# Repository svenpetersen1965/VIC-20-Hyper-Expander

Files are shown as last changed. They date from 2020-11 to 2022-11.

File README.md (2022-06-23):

# VIC-20-Hyper-Expander
The Hyper Expander is a cartridge for the Commodore VIC-20, which provides up to 16kB EPROM and up to 37kB RAM. It is a super-set of the original Commodore VIC-1211A Super Expander, which provides only 3k of RAM.

The Hyper Expander can hold up to two 27C512 EPROMs, the 8k memory bank of both EPROMs (A13...A15) can be selected for both EPROMs. The same selection applies to both of them. Each EPROM (IC1 and IC2) can be jumpered to two chip selects. That is BLK2 or BLK5 for IC1 and BLK1 or BLK3 for IC2. 

The RAM od two 32kB 62256 type static RAMs. The memory is divided into seven banks. Two 74LS148s decodes the active chip selects to one of each memory bank. The used chip selects can be configured with JP5 and JP4.

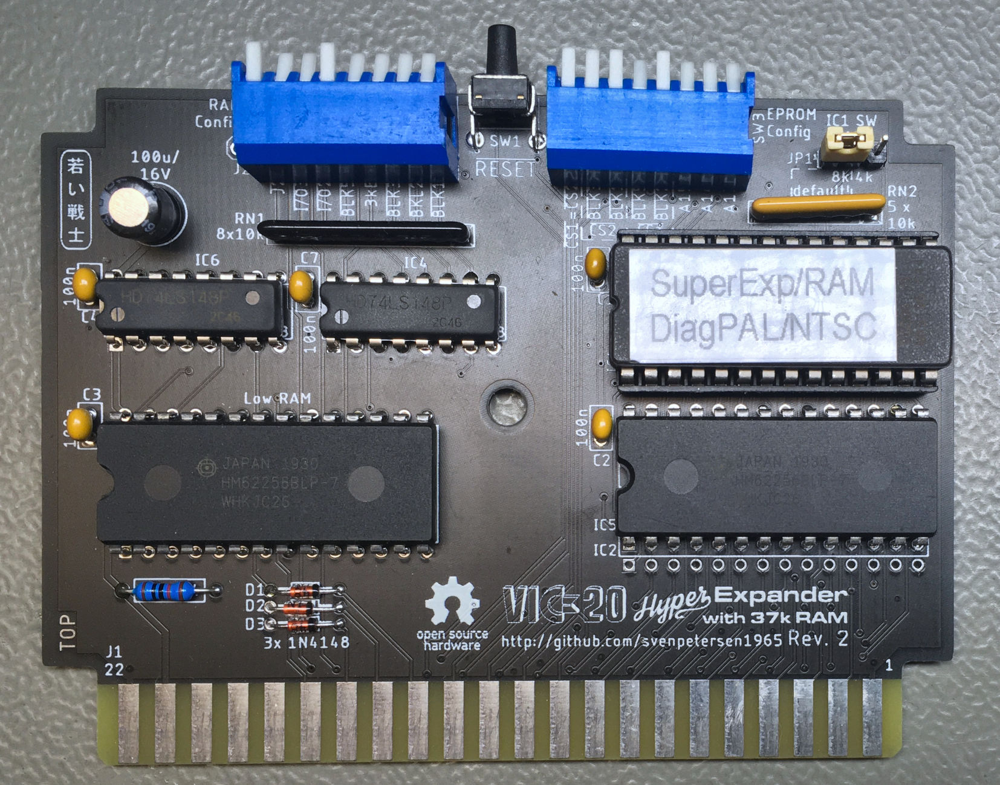
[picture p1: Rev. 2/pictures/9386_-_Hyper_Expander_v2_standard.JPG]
VIC-20 Hyper Expander


The BOM values do not include a case
* The calculated BOM value of Rev. 0 is: 12.86€ (12.12.2020)
* The calculated BOM value of Rev. 1 is: 15.23€ (11.04.2021)
* The calculated BOM value of Rev. 2 is: 16.17€ (02.11.2021)

# RAM issues
I was recently reported (May 2022), that there were cross-link issues with the Alliance 45ns and 55ns RAMs. I believe, that those might be too fast and that it is not an issue of the brand. Replacing those RAMs with slower models (70ns) has solved this problem. A friend has successfully used 100ns and 120ns RAMs as well (he had built a couple of the Hyper Expander). I am mainly using 70ns and 80ns RAMs and never found any issues with them. At least, my test software can recognize those problems.

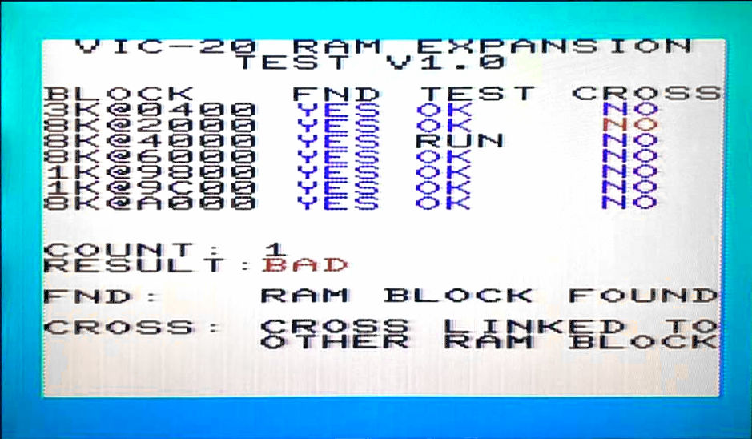
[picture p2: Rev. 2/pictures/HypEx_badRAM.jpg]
45ns RAM issue


# Testsoftware
Find the Testsoftware here: https://github.com/svenpetersen1965/VIC-20-RAM-Expansion-Test-Software

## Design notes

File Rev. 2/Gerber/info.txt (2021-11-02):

      
       Board: VIC20_HypExp
       Rev.:  2
  
       Files:
       ======
  
       All Gerber files are generated in extended gerber format (RS274X)
       *.TOP        : Film top copper
       *.BOT        :  -"- bottom copper
       *.STC        :  -"- top soldermask 
       *.STS        :  -"- bottom soldermask
       *.PLC        :  -"- silk screen top
       *.PLS        :  -"- silk screen bottom
       *.DK         : Drills plated Through (Excellon)
       *.NDK        : Drills not plated Through (Excellon)
       *.OUT        : Board outline

       Board Size:
       ===========
       Length     :   102.0 mm
       Width      :   75.0 mm
       Thickness  :   1.6 mm
       Material   :   FR 4
       Copper     :   35 um
       Surface    :   HASL
       
       Remarks:
       ========
       Width >= 8mil
       Distance >= 6mil
       Drill >= 0.35mm

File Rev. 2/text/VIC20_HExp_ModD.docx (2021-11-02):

Commodore VIC-20: Hyper Expander Rev. 2

Module Description

# Introduction

The Hyper Expander is a cartridge for the Commodore VIC-20, which provides up to 16kB EPROM and up to 37kB RAM. It is a super-set of the original Commodore VIC-1211A Super Expander, which provides only 3k of RAM.

The Hyper Expander can hold up to two 27C512 EPROMs, the 8k memory bank of both EPROMs (A13...A15) can be selected for both EPROMs. The same selection applies to both of them. Each EPROM (IC1 and IC2) can be configured to two chip selects (one each). That is or for IC1 and or for IC2 or in case SW3, switch 8 (CS1 = CS2) is selected, all four chip selects can be assigned to one EPROM (one at a time!).

The RAM consists of two 32kB 62256 type static RAMs. The memory is divided into four banks each. Two 74LS148 decode the active chip selects to one of each memory bank. The used chip selects can be configured with SW2.

# Configuration

## Note

The chip selects of the EPROM and the RAM can be concurrent. The same chip select must not be used for RAM and EPROM at the same time.

## DIP-Switches

There are two DIP Switches, which are used to configure the cartridge. The footprints of the DIP-switches are versatile and offer several ways for a fix or variable configuration:

1. A fix configuration via solder bridges
2. Jumpers
3. Horizontal DIP-switches
4. Vertical DIP-switches with 2.54mm (0.1”) row distance
5. Vertical (piano style) DIP-switches with 7.62mm (0.3”) row distance

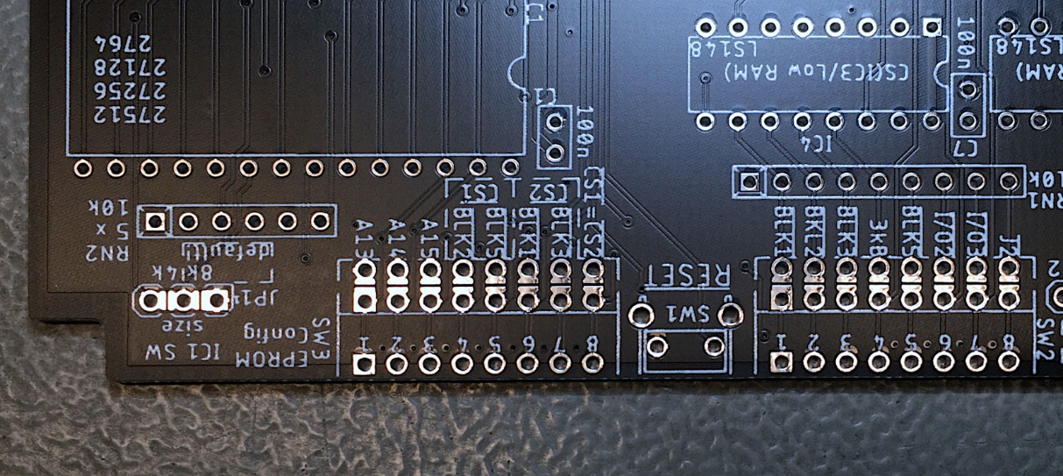
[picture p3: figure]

Figure 1: The footprint of the configuration DIP-switches allows a fix configuration with solder bridges

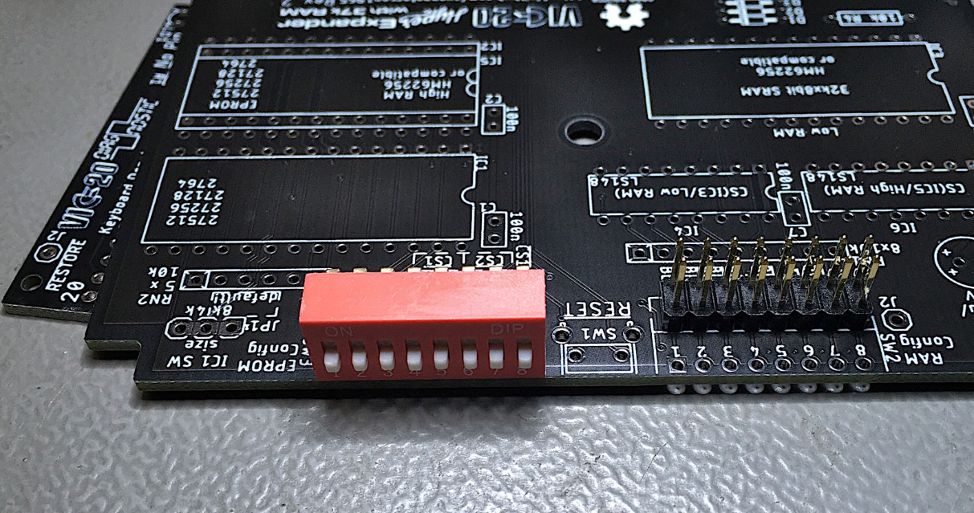
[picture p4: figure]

Figure 2: Vertical DIP-switch (row distance 2.54mm) or configuration with jumpers

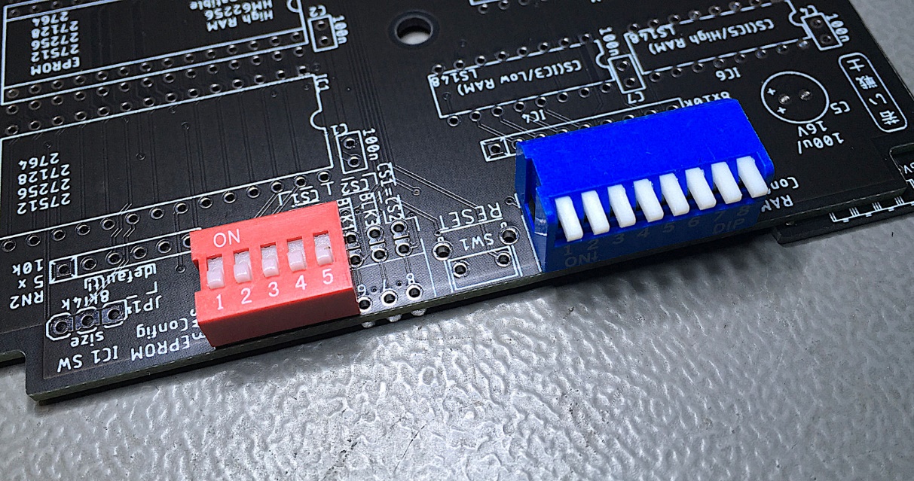
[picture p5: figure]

Figure 3: A horizontal or a piano style DIP-switch

## SW3 – EPROM configuration

The DIP switches do not need to be 8 switches wide, in case just one EPROM is used (refer to Figure 3). In this case, only a 5 switches wide model is sufficient. For a mere EPROM cartridge, it would be a good idea to program software that uses the same chip select () (or the same two chip selects for a 16k cartridge) and configure those with solder bridges. This way, the cartridge cannot be misconfigured.

Switch | Function | VIC-20 Address | Note
SW3-1 | EPROM Bank Select A13 | | Selects 8k Bank
SW3-2 | EPROM Bank Select A14 | | Selects 8k Bank
SW3-3 | EPROM Bank Select A15 | | Selects 8k Bank
SW3-4 | IC1 chip select | $4000 - $5FFF
SW3-5 | IC1 chip select | $A000 - $BFFF
SW3-6 | IC2 chip select | $2000 - $3FFF
SW3-7 | IC2 chip select | $6000 - $7FFF
SW3-8 | = | | All effect both ICs

Table 1: EPROM configuration

In case all four of the previous chip selects should be configured to address one of the EPROMs, switch 8 (“= “) could be closed. In this case, both chip selects are tied together. It is only allowed to activate one chip select! This configuration is desired, in case both RAMs are placed and EPROM software residing at $2000 or $6000 is contained in IC1.

The mapping of the chip selects to the ICs are inherited from the original Super Expander. They support the known 16kB cartridge configurations. Hence, they are not in an ascending sequence on the DIP switch.

In case an EPROM should be deactivated, it is only required to switch the respective switch “off”. The chip select then is HIGH (inactive) due to pull-up resistors.

## SW3 - Memory Bank Select (EPROM)

There are two different types of addresses mentioned in this document:

- VIC-20 Address
- EPROM Offset Address

Both types must not be confused! The EPROM Offset Address is the address of the selected memory bank within (the program buffer of the EPROM). This is, where you load the different binary files to the EPROM buffer. One of those memory banks is selected with the DIP Switch SW3 (switch 1/2/3). This appears in/is mapped to the VIC-20 memory at the address determined by the chip select (see Fehler! Verweisquelle konnte nicht gefunden werden.).

SW3-3 | SW3-2 | SW3-1 | Address Bits | | | EPROM Address (Offset)
A15 | A14 | A13 | A15 | A14 | A13
ON | ON | ON | L | L | L | 0x0000 – 0x1FFF
ON | ON | OFF | L | L | H | 0x2000 – 0x3FFF
ON | OFF | ON | L | H | L | 0x4000 – 0x5FFF
ON | OFF | OFF | L | H | H | 0x6000 – 0x7FFF
OFF | ON | ON | H | L | L | 0x8000 – 0x9FFF
OFF | ON | OFF | H | L | H | 0xA000 – 0xBFFF
OFF | OFF | ON | H | H | L | 0xC000 – 0xDFFF
OFF | OFF | OFF | H | H | H | 0xE000 – 0xFFFF

Table 2: 8k cartridges memory banks

A switch that is ON corresponds to a SET jumper, in case the cartridge is configured with jumpers instead of DIP-Switches.

For EPROMs smaller than a 27C512, the highest address pins have to be HIGH (see Table 7). To prevent these pins to accidentally be switched to LOW, the corresponding DIP-Switch pins could be clipped off.

## IC1 Software Size - JP1

The software size of IC1 can be set to 4kB. In this case, only the first 4kB of an 8kB EPROM bank is active. This may be desired, if the hyper expander (EPROM) should be combined with cartridges, that use the second 4k memory of an 8k bank, like some machine language monitor or serial cartridges do. Of course, this only works with a software, that only requires 4k, like the Super Expander software.

The address range of the EPROMs (as seen by the CPU) with JP1 set to “4k”

Chip Select | VIC-20 Address
| $4000 - $4FFF
| $A000 - $AFFF
| $2000 - $2FFF
| $6000 - $6FFF

Table 3: Address ranges with SW size (JP1) set to "4k"

The default software size is 8k. If it is desired to combine two cartridge software (like Super Expander and the VIC-MON machine language monitor, it is recommended to burn those two bin files in the same 8k block at the proper position.

## SW2 – RAM Configuration

SW2 activates the chip select signals, that are then decoded and address the respective RAM bank of IC3.

Switch | Jumper | Chip Select | Addresses
SW2-1 | 1-16 | | $2000 - $3FFF
SW2-2 | 2-15 | | $4000 - $5FFF
SW2-3 | 3-14 | | $6000 - $7FFF
SW2-4 | 4-13 | | $0400 - $0FFF
SW2-5 | 5-12 | | $A000 - $BFFF
SW2-6 | 6-11 | | $9800 - $9BFF
SW2-7 | 7-10 | | $9C00 - $9FFF
SW2-8 | 8-9 | | Unused (experimental)

Table 4: Settings SW2

# BYTES FREE

Be aware, that not all RAM configurations will lead to a more BASIC memory (the BYTES FREE) on switch on. The BASIC memory has to be coherent.

The memory map (screen RAM, BASIC RAM) of the VIC-20 depends on the memory expansion. It will be different for internal RAM and 3k Expansion.

RAM Configuration | BYTES FREE
| 6655
| 11775
and | 11775
and | 19967
, and | 28159
, , , and | 28159
, , | 6655

Table 5: Reported BASIC RAM

RAM that is not visible as BASIC RAM can of course still be accessed. In case is selected, the lowest 3k are not visible as BASIC RAM. In case a memory gap is configured (like and are configured, but is missing, the BASIC RAM consists of the internal RAM and the 3k RAM expansion.

The Super Expander Software (in ROM) requires 136 bytes of RAM. In case this software is activated (it is associated to) the BASIC memory will be reduced by this number of bytes.

# EPROMs

Four different types/sizes of EPROMs can be used with the Super Expander II, not all settings make sense with them. Their pin out is shown in Table 6.

The effect of the settings and the recommended configurations are shown in Table 7.

27C64
| 27C128
| | 27C256
| | | 27C512
| | | | SOCKET
Vpp | Vpp | Vpp | A15 | 1 | A15 | VCC | 28 | VCC | VCC | VCC | VCC
A12 | A12 | A12 | A12 | 2 | A12 | A14 | 27 | A14 | A14 | /PGM | /PGM
A7 | A7 | A7 | A7 | 3 | A7 | A13 | 26 | A13 | A13 | A13 | n.c.
A6 | A6 | A6 | A6 | 4 | A6 | A8 | 25 | A8 | A8 | A8 | A8
A5 | A5 | A5 | A5 | 5 | A5 | A9 | 24 | A9 | A9 | A9 | A9
A4 | A4 | A4 | A4 | 6 | A4 | A11 | 23 | A11 | A11 | A11 | A11
A3 | A3 | A3 | A3 | 7 | A3 | /OE | 22 | /G/Vpp | /G | /G | /G
A2 | A2 | A2 | A2 | 8 | A2 | A10 | 21 | A10 | A10 | A10 | A10
A1 | A1 | A1 | A1 | 9 | A1 | GND | 20 | /E | /E | /E | /E
A0 | A0 | A0 | A0 | 10 | A0 | D7 | 19 | D7 | D7 | D7 | D7
D0 | D0 | D0 | D0 | 11 | D0 | D6 | 18 | D6 | D6 | D6 | D6
D1 | D1 | D1 | D1 | 12 | D1 | D5 | 17 | D5 | D5 | D5 | D5
D2 | D2 | D2 | D2 | 13 | D2 | D4 | 16 | D4 | D4 | D4 | D4
GND | GND | GND | GND | 14 | GND | D3 | 15 | D3 | D3 | D3 | D3

Table 6: EPROM pin compatibility

EPROM | Size | A15 | A14 | A13
27C512 | 64kx8 | yes | yes | yes
27C256 | 32kx8 | HIGH | yes | yes
27C128 | 16kx8 | HIGH | HIGH | yes
27C64 | 8kx8 | HIGH | HIGH | HIGH

Table 7: Settings per EPROM type

In case Vpp is located at a dedicated pin (pin 1), A15 has no effect anymore. A HIGH level is recommended (switch is off). The /PGM Pin should be set HIGH. The n.c. (not connected) pin should be HIGH (with pull-up resistor) or open.

# Using parallel EEPROMs

There are parallel EPROMs, which fit into the EPROM sockets. They do not require erasing with a UV eraser, like EPROMs, but the price is higher.

Since they can be written, which is controlled by the signal, but the Super Expander II cartridge is lacking of this functionality, this signal has to be HIGH (inactive). The 28C256 has the A14 signal connected to Pin 1, which is A15 of the EEPROM socket. This is no problem, but it has to be kept in mind, that the jumper for A15 has effect on the bank select A14 of the EPROM.

28C64
| 28C256
| | SOCKET
n.c. | A14 | 1 | A15 | VCC | 28 | VCC | VCC
A12 | A12 | 2 | A12 | A14 | 27 | /WE | /WE
A7 | A7 | 3 | A7 | A13 | 26 | A13 | n.c
A6 | A6 | 4 | A6 | A8 | 25 | A8 | A8
A5 | A5 | 5 | A5 | A9 | 24 | A9 | A9
A4 | A4 | 6 | A4 | A11 | 23 | A11 | A11
A3 | A3 | 7 | A3 | /OE | 22 | /G/Vpp | /OE
A2 | A2 | 8 | A2 | A10 | 21 | A10 | A10
A1 | A1 | 9 | A1 | GND | 20 | /E | /CE
A0 | A0 | 10 | A0 | D7 | 19 | D7 | D7
D0 | D0 | 11 | D0 | D6 | 18 | D6 | D6
D1 | D1 | 12 | D1 | D5 | 17 | D5 | D5
D2 | D2 | 13 | D2 | D4 | 16 | D4 | D4
GND | GND | 14 | GND | D3 | 15 | D3 | D3

Table 8: EEPROM pin compatibility

EEPROM | Size | A15 | A14 | A13
28C256 | 32kx8 | =A14 | OPEN | yes
28C64 | 8kx8 | OPEN | OPEN | OPEN

Table 9: Settings per EEPROM type

# Dimensions

The dimensions of the Hyper Expander are identical to those of the original Super Expander PCB.

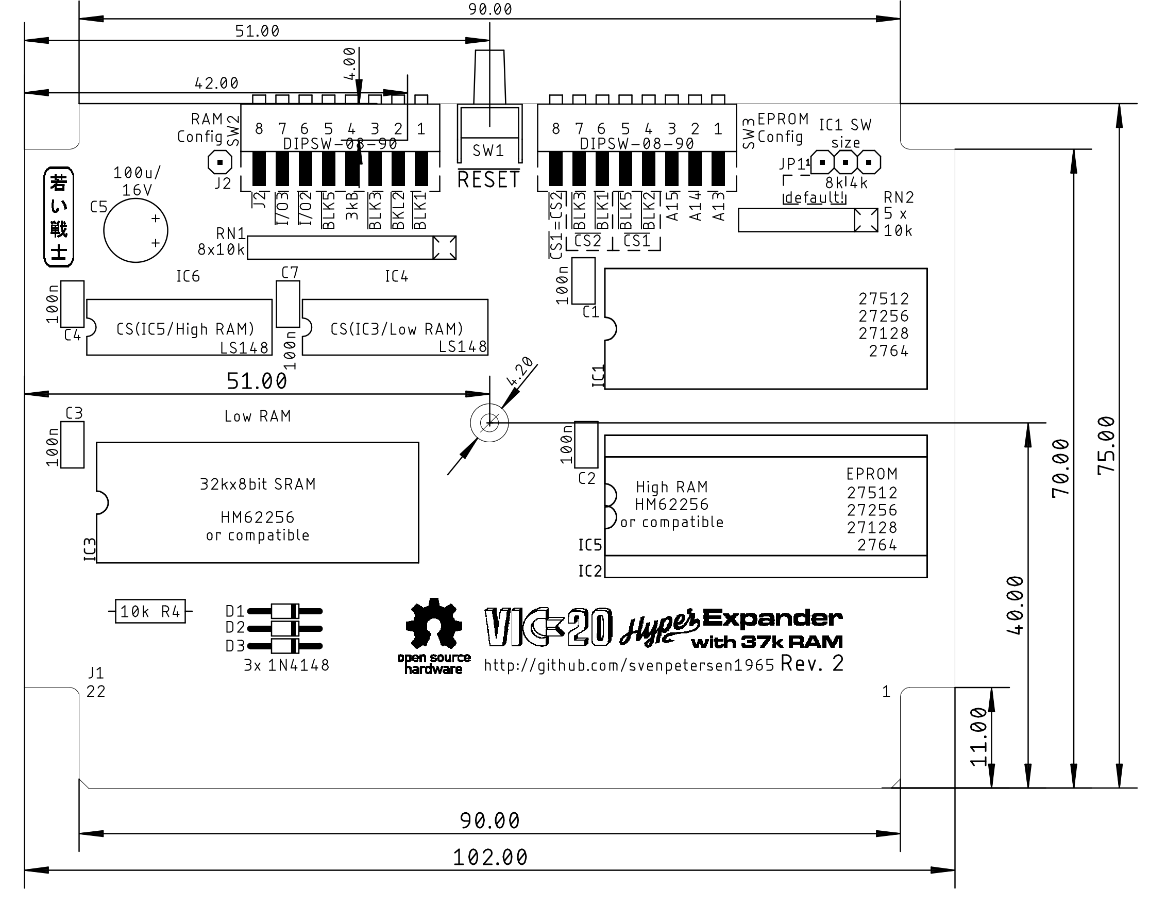
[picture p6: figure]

Figure 4: Dimensions of the Hyper Expander

The PCB fits the original Super Expander cartridge case, another VIC-20 cartridge case from Commodore or the tfw8bit.com cartridge case.

The VIC-20 cartridge cases are high enough to fits the Super Expander II PCB even with the ICs on sockets and vertical jumpers. This has been verified for the Super Expander case and the tfw8bit case. The tfw8bit case and the “other Commodore VIC-20” cases require two T-shaped board supports in the middle of the lower shell to be removed.

# Assembly and BOM

The High RAM (IC5) cannot be installed together with the 2nd EPROM (IC2).

## Full RAM Build

Do not place: JP2, IC2

## No RAM, just EPROM

Do not place: IC3, C3, IC4, C4, IC5, IC6, C6, RN1, D1-3, R4, SW2

# Revision History

## Rev. 0

- Prototype: Fully functional.

## Rev. 1

- Second optional RAM (IC5, “High RAM”) to provide the maximum possible RAM
- All jumpers moved to the front edge, so they can be accessed while the cartridge is installed
- Optional vertical RESET switch
- Resistor networks for many pull ups reduce the required space
- Pull ups for the EPROM chip selects

## Rev. 2

- A completely new layout
- DIP-Switch option for the jumpers
- All four can be configured to one EPROM (by setting = )
- The 4k Software size option for EPROM IC1

VIC20_HExp_ModD.docx 02.11.2021 16:48 Drafted by Sven Petersen Page 2 of 2 Doc.-No.: 172-6-01-02

VIC20_HExp_ModD.docx 02.11.2021 16:48 Drafted by Sven Petersen Page 1 of 1 Doc.-No.: 000-6-00-00

ENZIANWEG 16 ● 83052 BRUCKMÜHL TEL (08062) 728704 ● FAX (08062) 728705

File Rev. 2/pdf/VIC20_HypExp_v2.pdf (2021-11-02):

# Project Documentation

## Commodore VIC-20: Hyper Expander

## Project number: 172

## Revision: 2

## Date: 14.07.2021

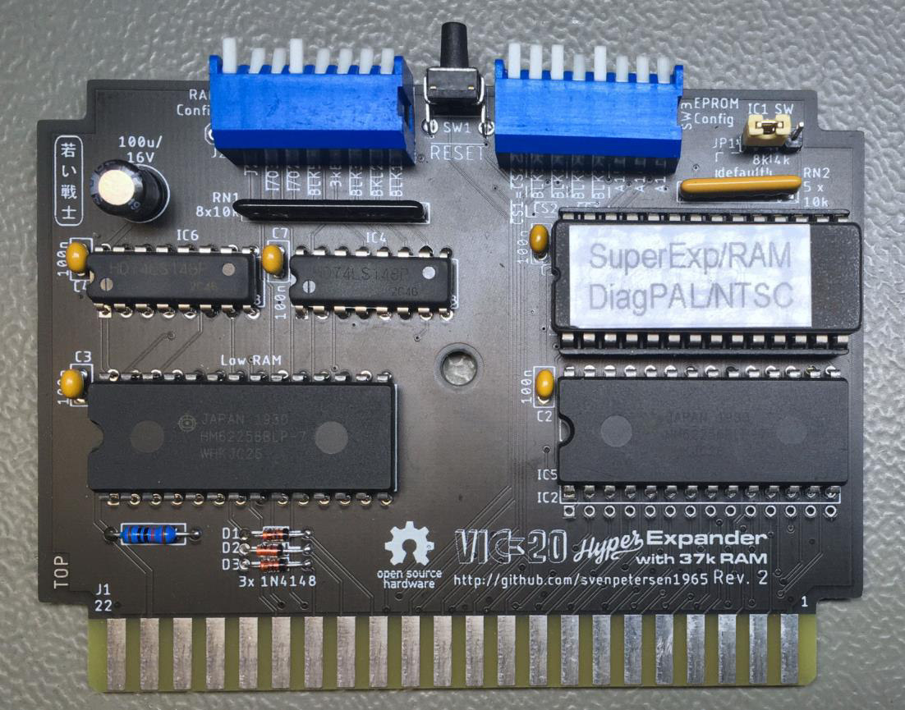
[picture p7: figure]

VIC20_HExp_ModD.docx | | 02.11.2021 16:48
Drafted by Sven Petersen | Page 1 of 9 | Doc.-No.: 172-6-01-02

### Commodore VIC-20: Hyper Expander Rev. 2

### Module Description

Table of Contents

## Introduction

The Hyper Expander is a cartridge for the Commodore VIC-20, which provides up to 16kB EPROM and up to 37kB RAM. It is a super-set of the original Commodore VIC-1211A Super Expander, which provides only 3k of RAM.

The Hyper Expander can hold up to two 27C512 EPROMs, the 8k memory bank of both EPROMs (A13...A15) can be selected for both EPROMs. The same selection applies to both of them. Each EPROM (IC1 and IC2) can be configured to two chip selects (one each). That is BLK2 or BLK5 for IC1 and BLK1 or BLK3 for IC2 or in case SW3, switch 8 (CS1 = CS2) is selected, all four chip selects can be assigned to one EPROM (one at a time!).

The RAM consists of two 32kB 62256 type static RAMs. The memory is divided into four banks each. Two 74LS148 decode the active chip selects to one of each memory bank. The used chip selects can be configured with SW2.

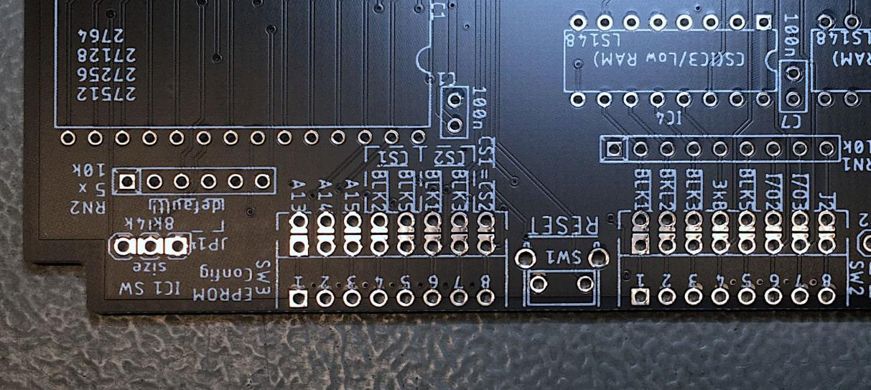
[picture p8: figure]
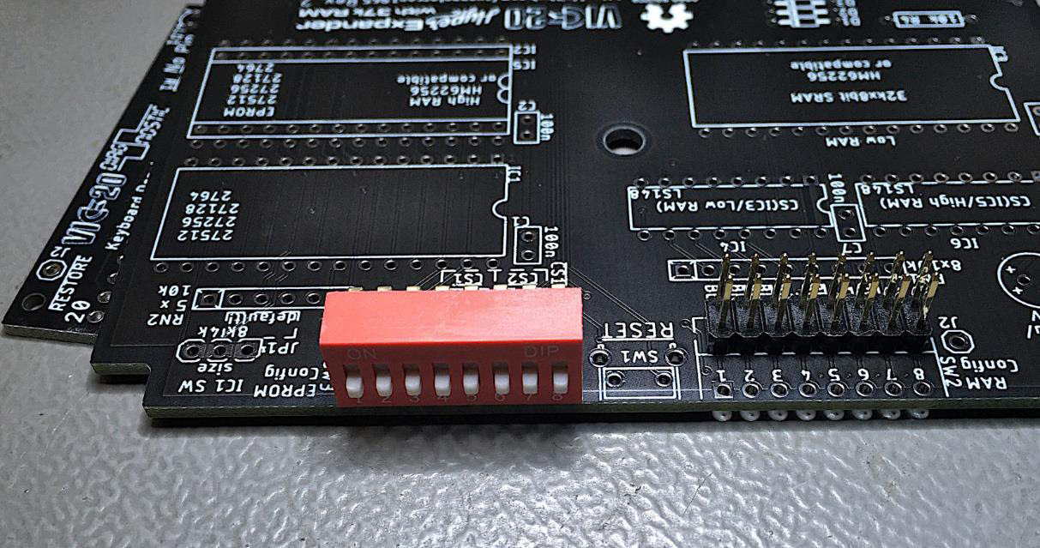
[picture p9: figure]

VIC20_HExp_ModD.docx | | 02.11.2021 16:48
Drafted by Sven Petersen | Page 2 of 9 | Doc.-No.: 172-6-01-02

## Configuration

### Note

The chip selects of the EPROM and the RAM can be concurrent. The same chip select must not be used for RAM and EPROM at the same time.

### DIP-Switches

There are two DIP Switches, which are used to configure the cartridge. The footprints of the DIP-switches are versatile and offer several ways for a fix or variable configuration:

### 1. A fix configuration via solder bridges 2. Jumpers 3. Horizontal DIP-switches

### 4. Vertical DIP-switches with 2.54mm (0.1”) row distance

### 5. Vertical (piano style) DIP-switches with 7.62mm (0.3”) row distance

Figure 1: The footprint of the configuration DIP-switches allows a fix configuration with solder bridges

Figure 2: Vertical DIP-switch (row distance 2.54mm) or configuration with jumpers

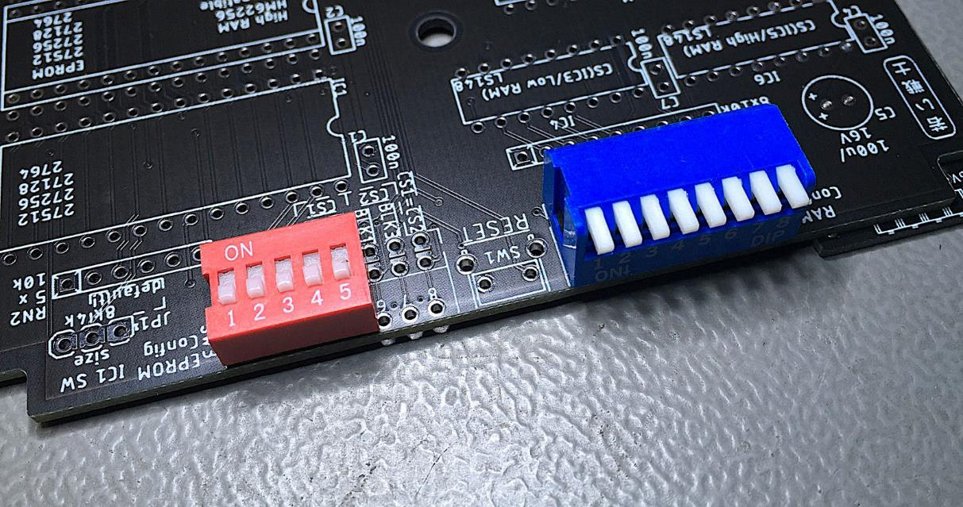
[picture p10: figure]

VIC20_HExp_ModD.docx | | 02.11.2021 16:48
Drafted by Sven Petersen | Page 3 of 9 | Doc.-No.: 172-6-01-02

Figure 3: A horizontal or a piano style DIP-switch

### SW3 – EPROM configuration

The DIP switches do not need to be 8 switches wide, in case just one EPROM is used (refer to Figure 3). In this case, only a 5 switches wide model is sufficient. For a mere EPROM cartridge, it would be a good idea to program software that uses the same chip select ( BLK* ) (or the same two chip selects for a 16k cartridge) and configure those with solder bridges. This way, the cartridge cannot be misconfigured.

Switch | Function | VIC-20 Address Note
SW3-1 | EPROM Bank Select A13 | | Selects 8k Bank
SW3-2 | EPROM Bank Select A14 | | Selects 8k Bank
SW3-3 | EPROM Bank Select A15 | | Selects 8k Bank
SW3-4 | IC1 chip select BLK2 | $4000 - $5FFF
SW3-5 | IC1 chip select BLK5 | $A000 - $BFFF
SW3-6 | IC2 chip select BLK1 | $2000 - $3FFF
SW3-7 | IC2 chip select BLK3 | $6000 - $7FFF
SW3-8 | CS1 = CS2 | | All BLK* effect both ICs

Table 1: EPROM configuration

In case all four of the previous chip selects should be configured to address one of the
EPROMs, switch 8 (“ CS1 = CS2 “) could be closed. In this case, both chip selects are tied

together. It is only allowed to activate one chip select! This configuration is desired, in case both RAMs are placed and EPROM software residing at $2000 or $6000 is contained in IC1.

The mapping of the chip selects BLK* to the ICs are inherited from the original Super Expander. They support the known 16kB cartridge configurations. Hence, they are not in an ascending sequence on the DIP switch.

In case an EPROM should be deactivated, it is only required to switch the respective switch “off”. The chip select then is HIGH (inactive) due to pull-up resistors.

VIC20_HExp_ModD.docx | | 02.11.2021 16:48
Drafted by Sven Petersen | Page 4 of 9 | Doc.-No.: 172-6-01-02

### SW3 - Memory Bank Select (EPROM)

There are two different types of addresses mentioned in this document:

- VIC-20 Address
- EPROM Offset Address

Both types must not be confused! The EPROM Offset Address is the address of the selected memory bank within (the program buffer of the EPROM). This is, where you load the different binary files to the EPROM buffer. One of those memory banks is selected with the DIP Switch SW3 (switch 1/2/3). This appears in/is mapped to the VIC-20 memory at the address determined by the chip select BLK* (see Fehler! Verweisquelle konnte nicht gefunden werden.).

SW3-3 | SW3-2 | SW3-1 | Address Bits | EPROM Address
A15 | A14 | A13 | A15 | A14 | A13 | (Offset)
ON | ON | ON | L | L | L | 0x0000 – 0x1FFF
ON | ON | OFF | L | L | H | 0x2000 – 0x3FFF
ON | OFF | ON | L | H | L | 0x4000 – 0x5FFF
ON | OFF | OFF | L | H | H | 0x6000 – 0x7FFF
OFF | ON | ON | H | L | L | 0x8000 – 0x9FFF
OFF | ON | OFF | H | L | H | 0xA000 – 0xBFFF
OFF | OFF | ON | H | H | L | 0xC000 – 0xDFFF
OFF | OFF | OFF | H | H | H | 0xE000 – 0xFFFF
Table 2: 8k cartridges memory banks

A switch that is ON corresponds to a SET jumper, in case the cartridge is configured with jumpers instead of DIP-Switches.

For EPROMs smaller than a 27C512, the highest address pins have to be HIGH (see Table 7). To prevent these pins to accidentally be switched to LOW, the corresponding DIP-Switch pins could be clipped off.

### IC1 Software Size - JP1

The software size of IC1 can be set to 4kB. In this case, only the first 4kB of an 8kB EPROM bank is active. This may be desired, if the hyper expander (EPROM) should be combined with cartridges, that use the second 4k memory of an 8k bank, like some machine language monitor or serial cartridges do. Of course, this only works with a software, that only requires 4k, like the Super Expander software.

### The address range of the EPROMs (as seen by the CPU) with JP1 set to “4k”

Chip Select | VIC-20 Address
BLK2 | $4000 - $4FFF
BLK5 | $A000 - $AFFF
BLK1 | $2000 - $2FFF
BLK3 | $6000 - $6FFF

Table 3: Address ranges with SW size (JP1) set to "4k"

The default software size is 8k. If it is desired to combine two cartridge software (like Super Expander and the VIC-MON machine language monitor, it is recommended to burn those two bin files in the same 8k block at the proper position.

VIC20_HExp_ModD.docx | | 02.11.2021 16:48
Drafted by Sven Petersen | Page 5 of 9 | Doc.-No.: 172-6-01-02

### SW2 – RAM Configuration

SW2 activates the chip select signals, that are then decoded and address the respective RAM bank of IC3.

Switch | Jumper | Chip Select | Addresses
SW2-1 | 1-16 | BLK1 | $2000 - $3FFF
SW2-2 | 2-15 | BLK2 | $4000 - $5FFF
SW2-3 | 3-14 | BLK3 | $6000 - $7FFF
SW2-4 | 4-13 | CS3K | $0400 - $0FFF
SW2-5 | 5-12 | BLK5 | $A000 - $BFFF
SW2-6 | 6-11 | I/O2 | $9800 - $9BFF
SW2-7 | 7-10 | I/O3 | $9C00 - $9FFF
SW2-8 | 8-9 | J2 | Unused (experimental)

Table 4: Settings SW2

## BYTES FREE

Be aware, that not all RAM configurations will lead to a more BASIC memory (the BYTES FREE) on switch on. The BASIC memory has to be coherent.

The memory map (screen RAM, BASIC RAM) of the VIC-20 depends on the memory expansion. It will be different for internal RAM and 3k Expansion.

RAM Configuration | BYTES FREE
CS3K | 6655
BLK1 | 11775
CS3K and BLK1 | 11775
BLK1 and BLK2 | 19967
BLK1 , BLK2 and BLK3 | 28159
BLK1 , BLK2 , BLK3 , CS3K and BLK5 | 28159
CS3K , BLK2 , BLK3 | 6655

Table 5: Reported BASIC RAM

RAM that is not visible as BASIC RAM can of course still be accessed. In case BLK1 is selected,

the lowest 3k are not visible as BASIC RAM. In case a memory gap is configured (like BLK2 and

BLK3 are configured, but BLK1 is missing, the BASIC RAM consists of the internal RAM and the 3k RAM expansion.

The Super Expander Software (in ROM) requires 136 bytes of RAM. In case this software is activated (it is associated to BLK5 ) the BASIC memory will be reduced by this number of bytes.

VIC20_HExp_ModD.docx | | 02.11.2021 16:48
Drafted by Sven Petersen | Page 6 of 9 | Doc.-No.: 172-6-01-02

## EPROMs

Four different types/sizes of EPROMs can be used with the Super Expander II, not all settings make sense with them. Their pin out is shown in Table 6.

The effect of the settings and the recommended configurations are shown in Table 7.

27C64

| 27C128
| 27C256
| 27C512
| SOCKET
Vpp | Vpp | Vpp | A15 | 1 A15 | VCC 28 | VCC | VCC | VCC | VCC
A12 | A12 | A12 | A12 | 2 A12 | A14 27 | A14 | A14 | /PGM | /PGM
A7 | A7 | A7 | A7 | 3 A7 | A13 26 | A13 | A13 | A13 | n.c.
A6 | A6 | A6 | A6 | 4 A6 | A8 25 | A8 | A8 | A8 | A8
A5 | A5 | A5 | A5 | 5 A5 | A9 24 | A9 | A9 | A9 | A9
A4 | A4 | A4 | A4 | 6 A4 | A11 23 | A11 | A11 | A11 | A11
A3 | A3 | A3 | A3 | 7 A3 | /OE 22 | /G/Vpp | /G | /G | /G
A2 | A2 | A2 | A2 | 8 A2 | A10 21 | A10 | A10 | A10 | A10
A1 | A1 | A1 | A1 | 9 A1 | GND 20 | /E | /E | /E | /E
A0 | A0 | A0 | A0 | 10 A0 | D7 19 | D7 | D7 | D7 | D7
D0 | D0 | D0 | D0 | 11 D0 | D6 18 | D6 | D6 | D6 | D6
D1 | D1 | D1 | D1 | 12 D1 | D5 17 | D5 | D5 | D5 | D5
D2 | D2 | D2 | D2 | 13 D2 | D4 16 | D4 | D4 | D4 | D4
GND | GND | GND | GND | 14 GND | D3 15 | D3 | D3 | D3 | D3

Table 6: EPROM pin compatibility

EPROM | Size | A15 | A14 | A13
27C512 | 64kx8 | yes | yes | yes
27C256 | 32kx8 | HIGH | yes | yes
27C128 | 16kx8 | HIGH | HIGH | yes
27C64 | 8kx8 | HIGH | HIGH | HIGH
Table 7: Settings per EPROM type

In case Vpp is located at a dedicated pin (pin 1), A15 has no effect anymore. A HIGH level is recommended (switch is off). The /PGM Pin should be set HIGH. The n.c. (not connected) pin should be HIGH (with pull-up resistor) or open.

VIC20_HExp_ModD.docx | | 02.11.2021 16:48
Drafted by Sven Petersen | Page 7 of 9 | Doc.-No.: 172-6-01-02

## Using parallel EEPROMs

There are parallel EPROMs, which fit into the EPROM sockets. They do not require erasing with a UV eraser, like EPROMs, but the price is higher.

Since they can be written, which is controlled by the WE signal, but the Super Expander II cartridge is lacking of this functionality, this signal has to be HIGH (inactive). The 28C256 has the A14 signal connected to Pin 1, which is A15 of the EEPROM socket. This is no problem, but it has to be kept in mind, that the jumper for A15 has effect on the bank select A14 of the EPROM.

28C64

| 28C256
| SOCKET
n.c. | A14 | 1 A15 | VCC 28 | VCC | VCC
A12 | A12 | 2 A12 | A14 27 | /WE | /WE
A7 | A7 | 3 A7 | A13 26 | A13 | n.c
A6 | A6 | 4 A6 | A8 25 | A8 | A8
A5 | A5 | 5 A5 | A9 24 | A9 | A9
A4 | A4 | 6 A4 | A11 23 | A11 | A11
A3 | A3 | 7 A3 | /OE 22 | /G/Vpp | /OE
A2 | A2 | 8 A2 | A10 21 | A10 | A10
A1 | A1 | 9 A1 | GND 20 | /E | /CE
A0 | A0 | 10 A0 | D7 19 | D7 | D7
D0 | D0 | 11 D0 | D6 18 | D6 | D6
D1 | D1 | 12 D1 | D5 17 | D5 | D5
D2 | D2 | 13 D2 | D4 16 | D4 | D4
GND | GND | 14 GND | D3 15 | D3 | D3

Table 8: EEPROM pin compatibility

EEPROM | Size | A15 | A14 | A13
28C256 | 32kx8 | =A14 | OPEN | yes
28C64 | 8kx8 | OPEN | OPEN | OPEN
Table 9: Settings per EEPROM type

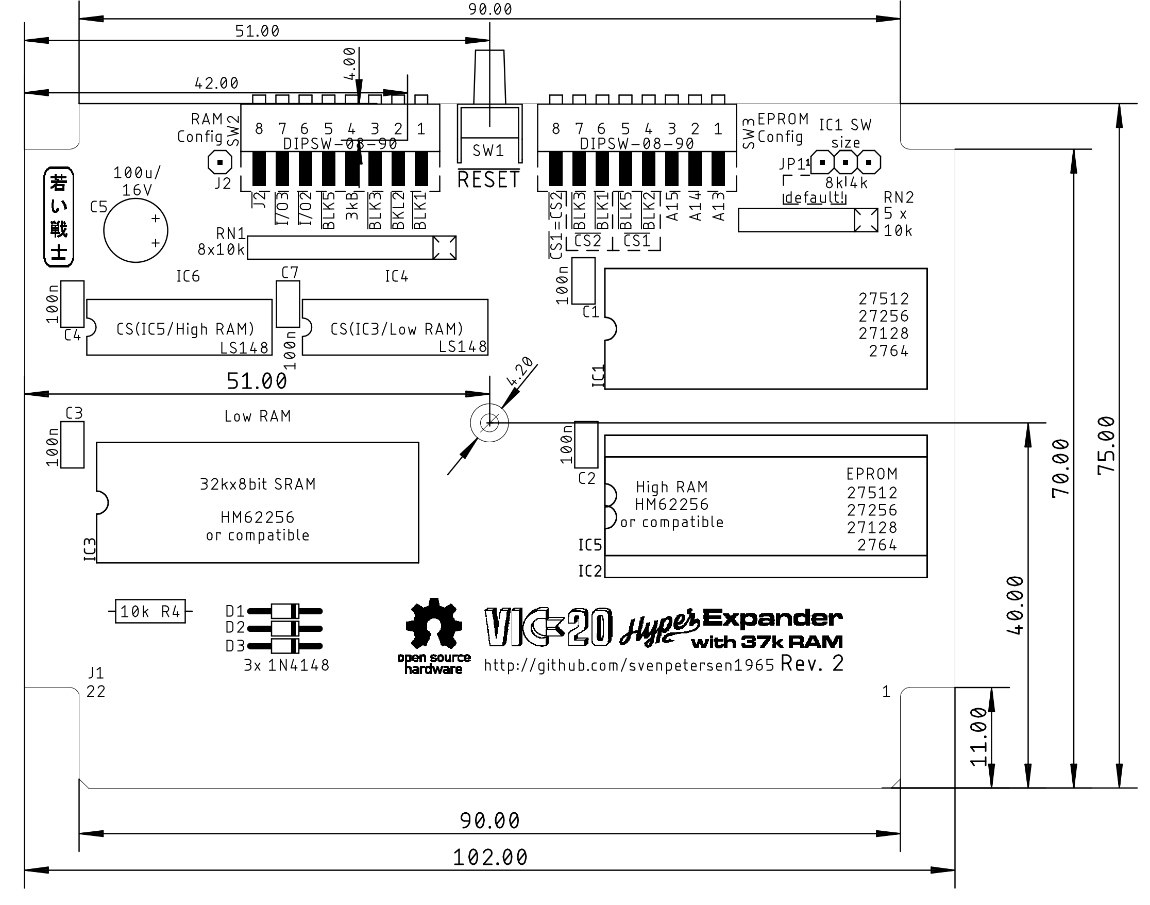
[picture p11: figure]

VIC20_HExp_ModD.docx | | 02.11.2021 16:48
Drafted by Sven Petersen | Page 8 of 9 | Doc.-No.: 172-6-01-02

## Dimensions

The dimensions of the Hyper Expander are identical to those of the original Super Expander PCB.

Figure 4: Dimensions of the Hyper Expander

The PCB fits the original Super Expander cartridge case, another VIC-20 cartridge case from Commodore or the tfw8bit.com cartridge case.

The VIC-20 cartridge cases are high enough to fits the Super Expander II PCB even with the ICs on sockets and vertical jumpers. This has been verified for the Super Expander case and the tfw8bit

### case. The tfw8bit case and the “other Commodore VIC-20” cases require two T-shaped board

supports in the middle of the lower shell to be removed.

## Assembly and BOM

The High RAM (IC5) cannot be installed together with the 2nd EPROM (IC2).

### Full RAM Build

Do not place: JP2, IC2

### No RAM, just EPROM

Do not place: IC3, C3, IC4, C4, IC5, IC6, C6, RN1, D1-3, R4, SW2

## Revision History

### Rev. 0

- Prototype: Fully functional.

### Rev. 1 - Second optional RAM (IC5, “High RAM”) to provide the maximum possible RAM

VIC20_HExp_ModD.docx | | 02.11.2021 16:48
Drafted by Sven Petersen | Page 9 of 9 | Doc.-No.: 172-6-01-02
- All jumpers moved to the front edge, so they can be accessed while the cartridge is installed
- Optional vertical RESET switch
- Resistor networks for many pull ups reduce the required space
- Pull ups for the EPROM chip selects

### Rev. 2

- A completely new layout
- DIP-Switch option for the jumpers
- All four BLK* can be configured to one EPROM (by setting CS1 = CS2 )
- The 4k Software size option for EPROM IC1

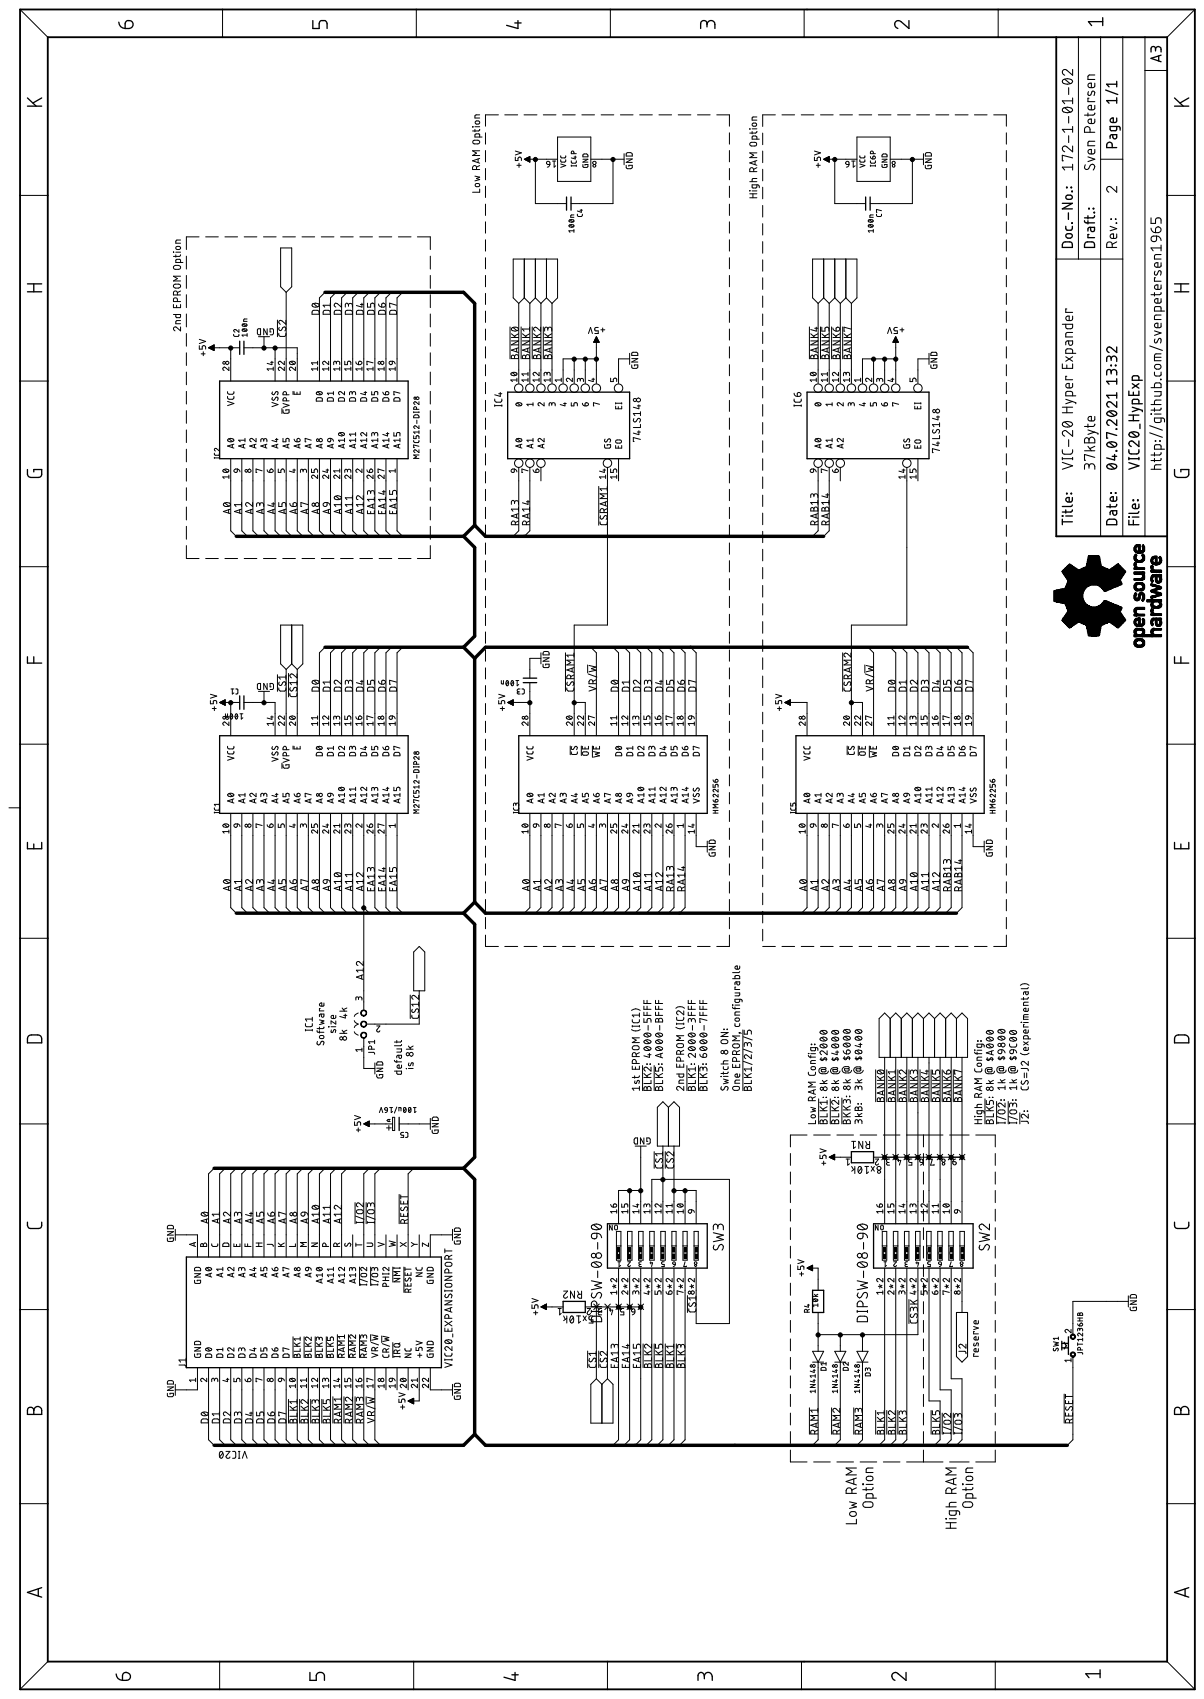
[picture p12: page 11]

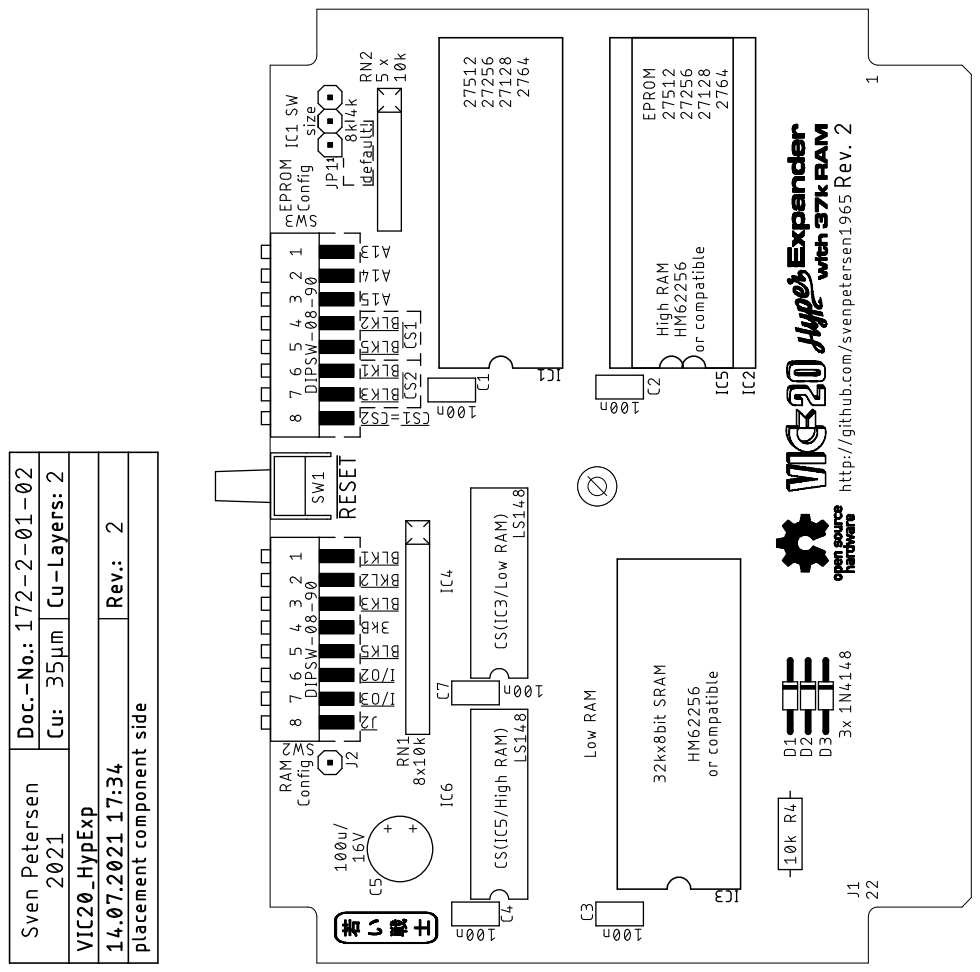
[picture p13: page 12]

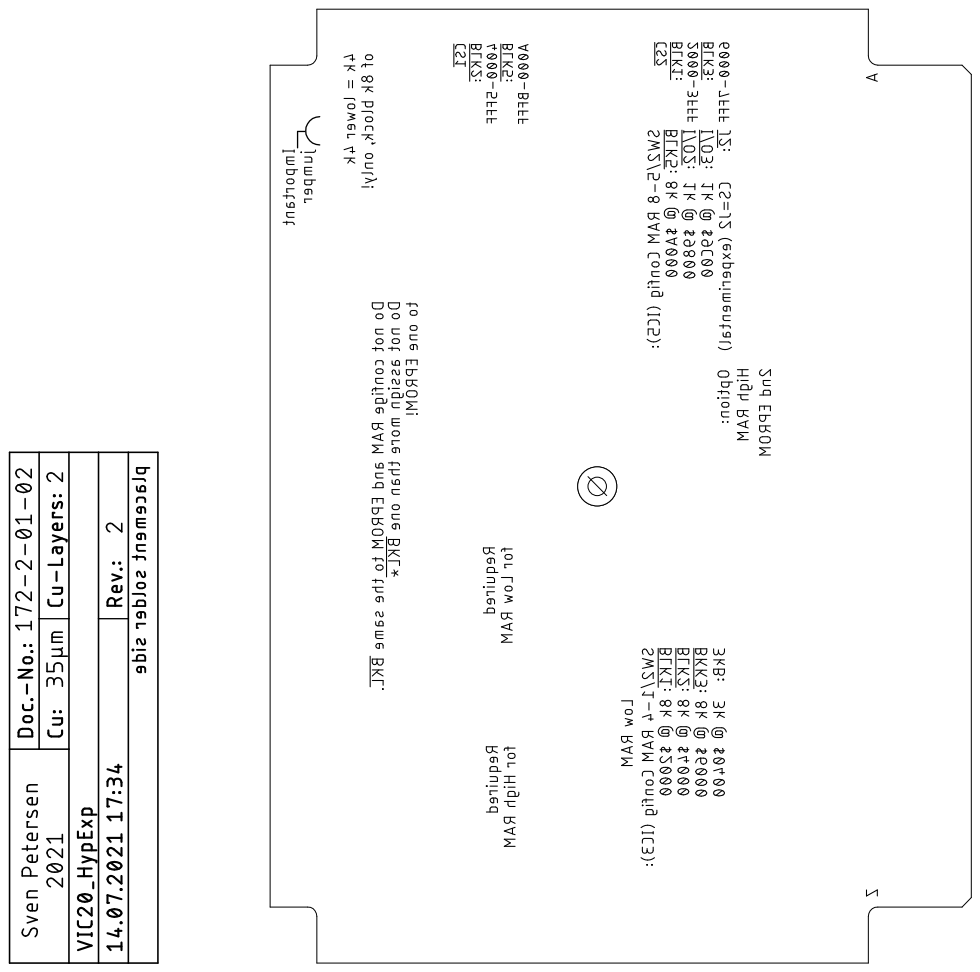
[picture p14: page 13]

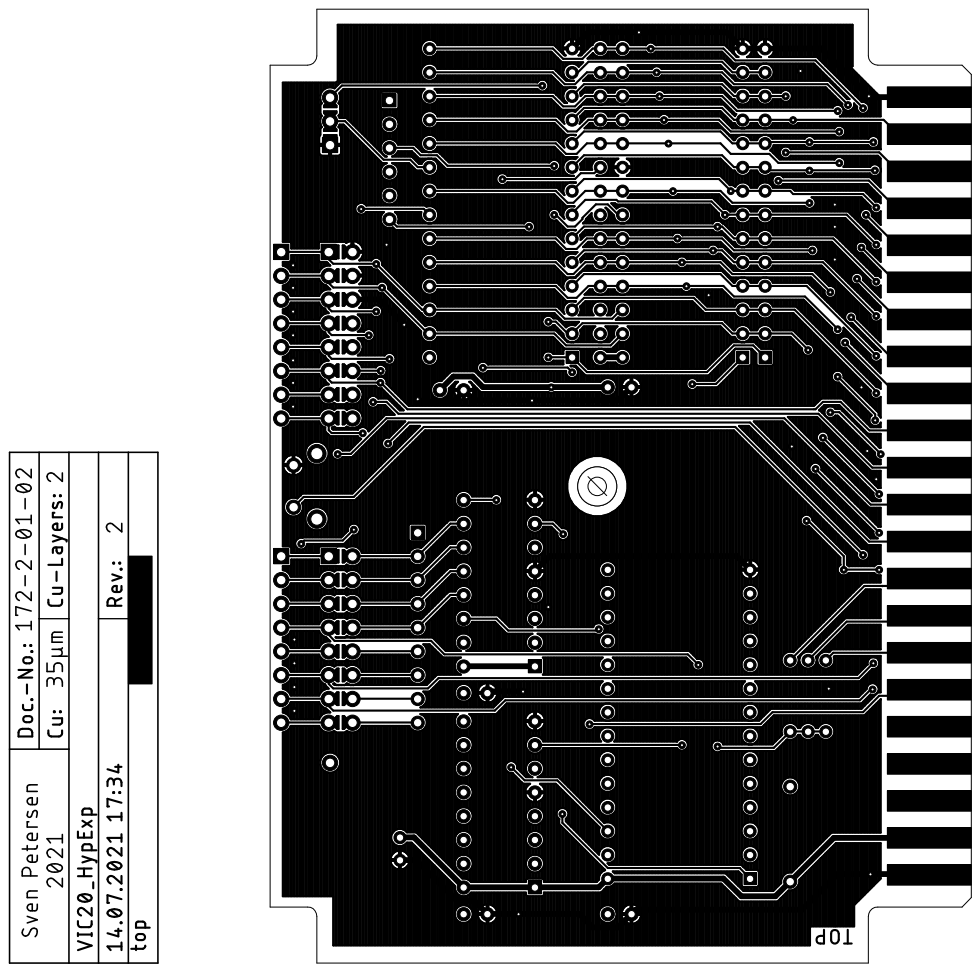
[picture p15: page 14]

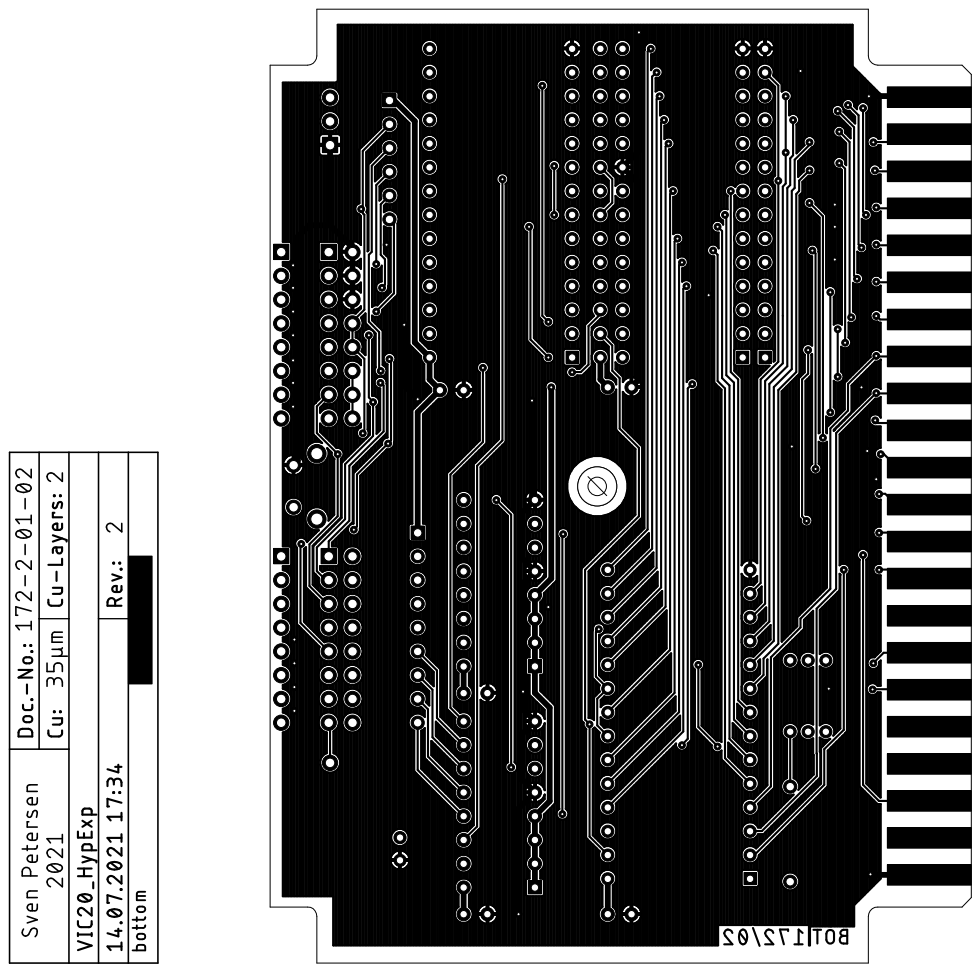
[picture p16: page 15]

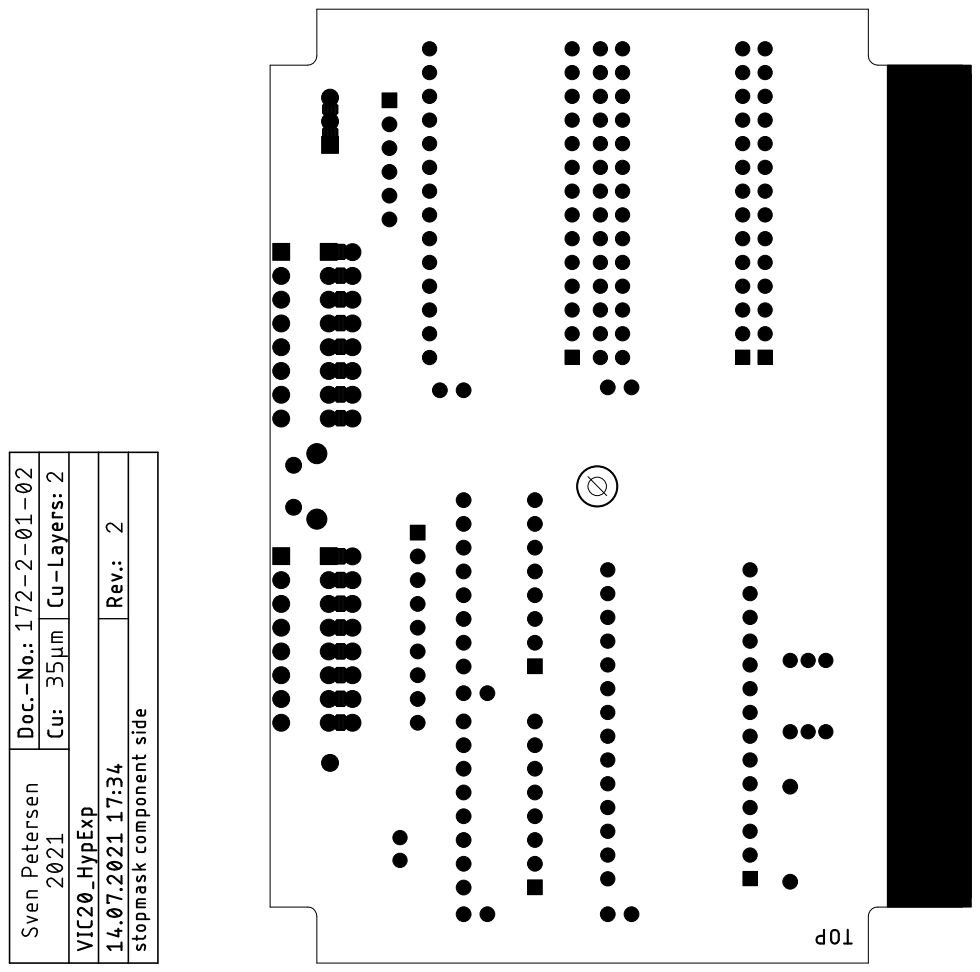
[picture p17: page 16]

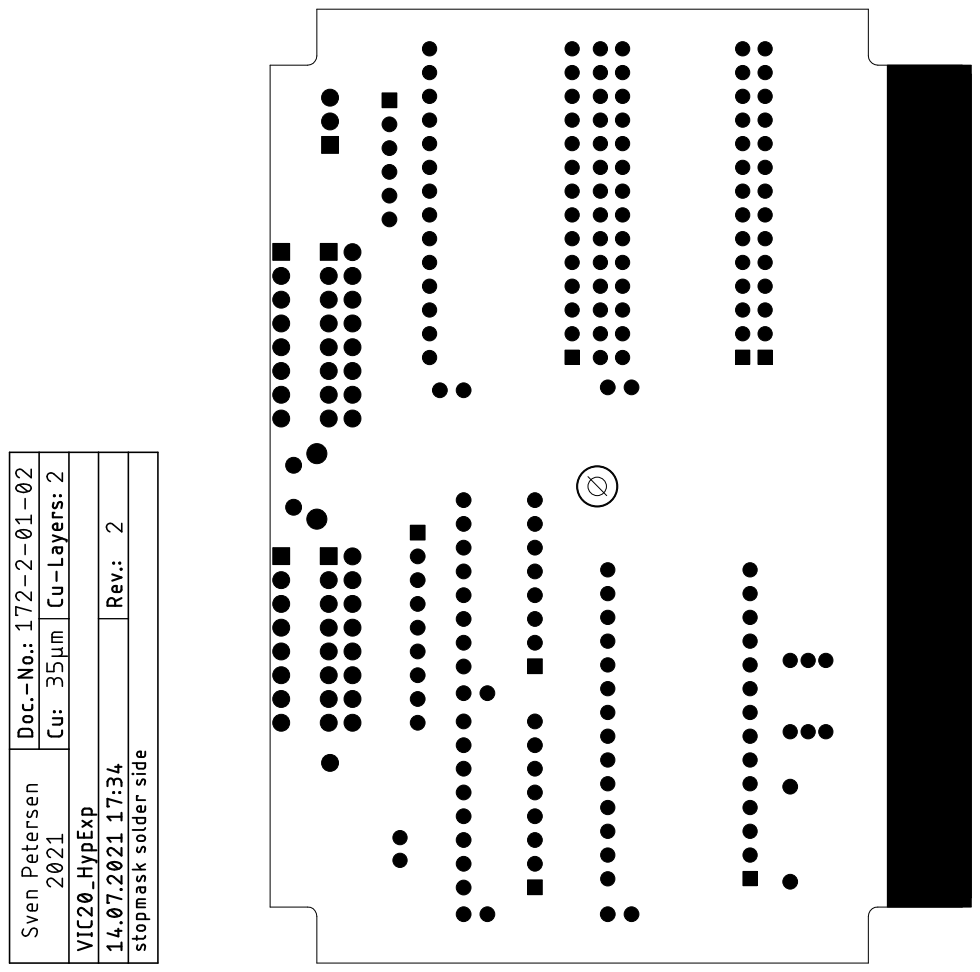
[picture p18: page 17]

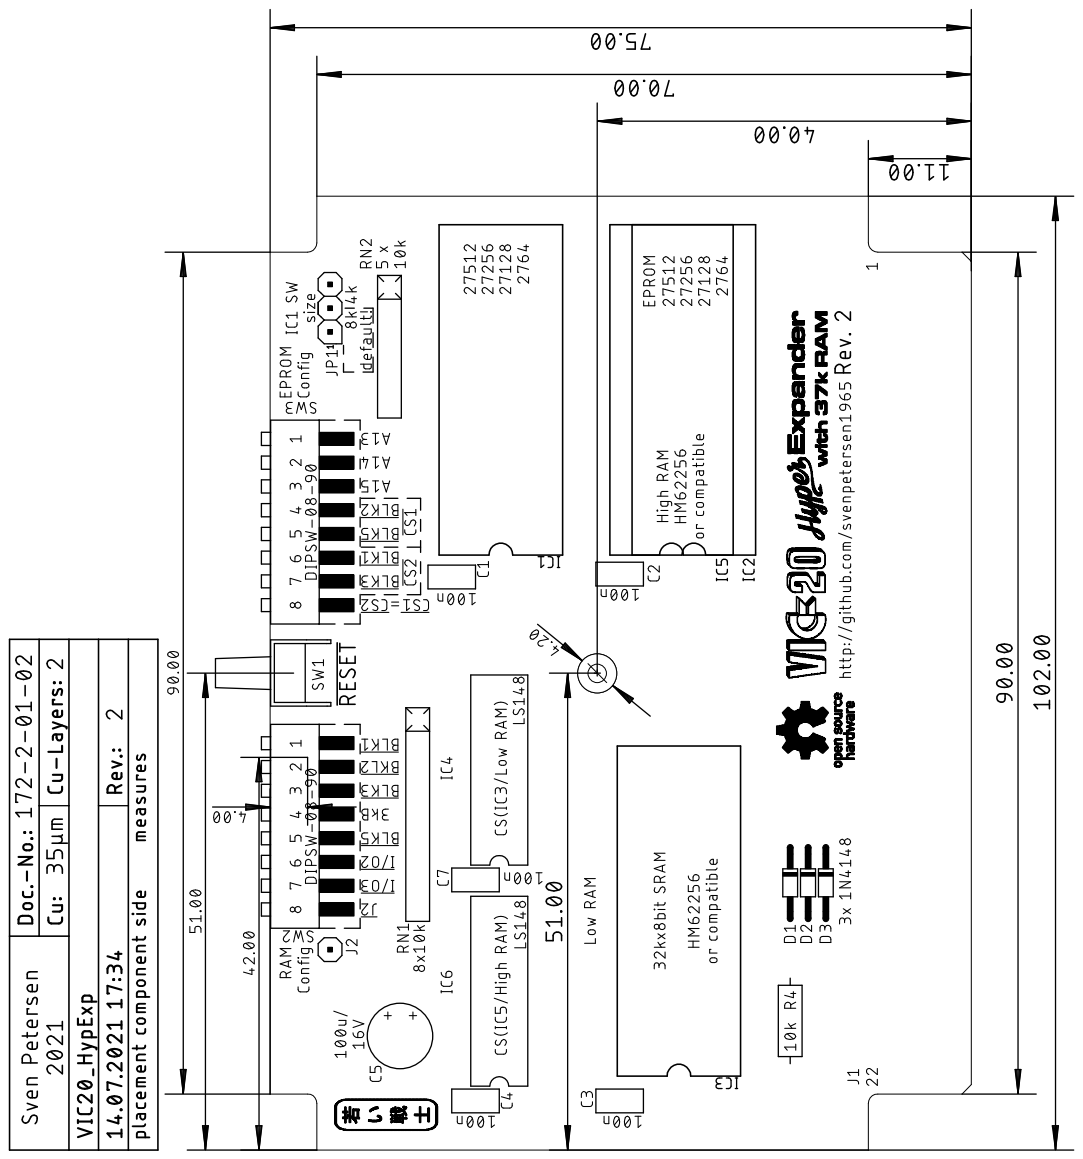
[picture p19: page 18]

VIC20_HExp_FunD.docx | | 02.11.2021 16:50
Drafted by Sven Petersen | Page 1 of 1 | Doc.-No.: 172-6-02-02

### Commodore VIC-20: Hyper Expander Rev. 2

### Functional Description

The EPROM part with IC1 and IC2 is pretty much a straight forward VIC-20 EPROM cartridge.

### The data bus (D0…D7) and the address bus (A0…A12) are connected to the EPROM. This allows to address 8k of memory. The address bit A13…A15 can be jumpered (SW3), which

results in selectable 8k memory banks.

The chip selects can be set for each EPROM differently (SW3). It is not every chip select possible to use with IC1 and IC2. Rev. 2 added the opportunity to set CS1 = CS2 .

IC3 and IC5 are static RAMs (32kByte each). Again, the data bus (D0…D7) and the address bus (A0…A12) is connected to both ICs, which results in an 8k RAM bank size. These four RAM banks are selected with the signals RA13 and RA14 (IC3 = Low RAM)) and RAB13 and RAB14 (IC5 = High RAM)). Those additional address signals are generated by the 8 to 3 decoder IC4 and IC6 for the High RAM). If one of the chip selects gets LOW, the signal CSRAM1 or

CSRAM2 gets LOW, too. This is forming the chip select signal of IC3/IC5.

The three chip select signals for the 3k RAM expansion are originally made for addressing 2114 1kx4 RAMs. Since the 4th RAM block is addressed with the 3k chip selects RAM1..3 , those need to be combined to a single chip select, which is accomplished with D1, D2 and D3 and the pull-up resistor R4. In case one of those signals is LOW, the combined CS3K is LOW as well.

The 2nd EPROM IC2 is optional and can only be installed, in case the High RAM IC5 is not installed. In this case, IC6 and JP4 are not required.

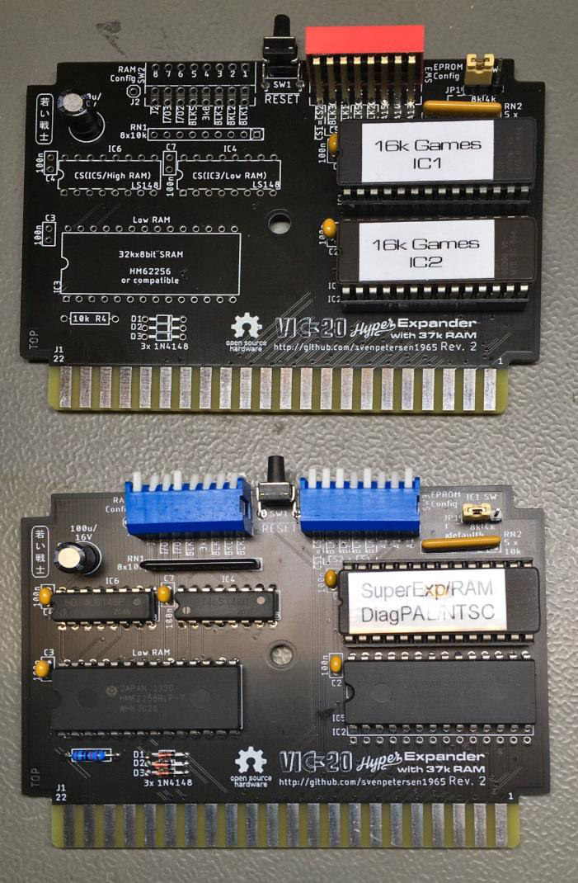
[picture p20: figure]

VIC20_HExpI_Test.docx | | 02.11.2021 16:51
Drafted by Sven Petersen | Page 1 of 7 | Doc.-No.: 171-6-03-02

### Commodore VIC-20: Hyper Expander Rev. 2

### Testing

## Test Setup

The tests were conducted with a VickyTwenty (a reproduction of the VIC-20 ASSY 250403) and two Hyper Expander cartridges Rev. 2. One was a RAM and 1 EPROM configuration with two HN61256BLP-7 RAM and up to two 27C512 EPROMs, the other was a 16k EPROM cartridge with two HN61256BLP-7 RAM.

Figure 1: Prototypes of Hyper Expander Rev. 2: 16kB EPROM (top), Full RAM and 8k EPROM (bottom)

## Test Execution

### Super Expander Software

First, the original Super Expander Software from zimmers.net and the VIC-MON for $B000 were programed to an EPROM. These two programs fit into one 8k memory bank, since the Super Expander software is a 4k software. The EPROM was inserted the in IC1 socket and CS1 was set

to BLK5 ($A000-$BFFF). The RAM was configured to 3k RAM expansion only (SW2: all off, except switch 4 on ).

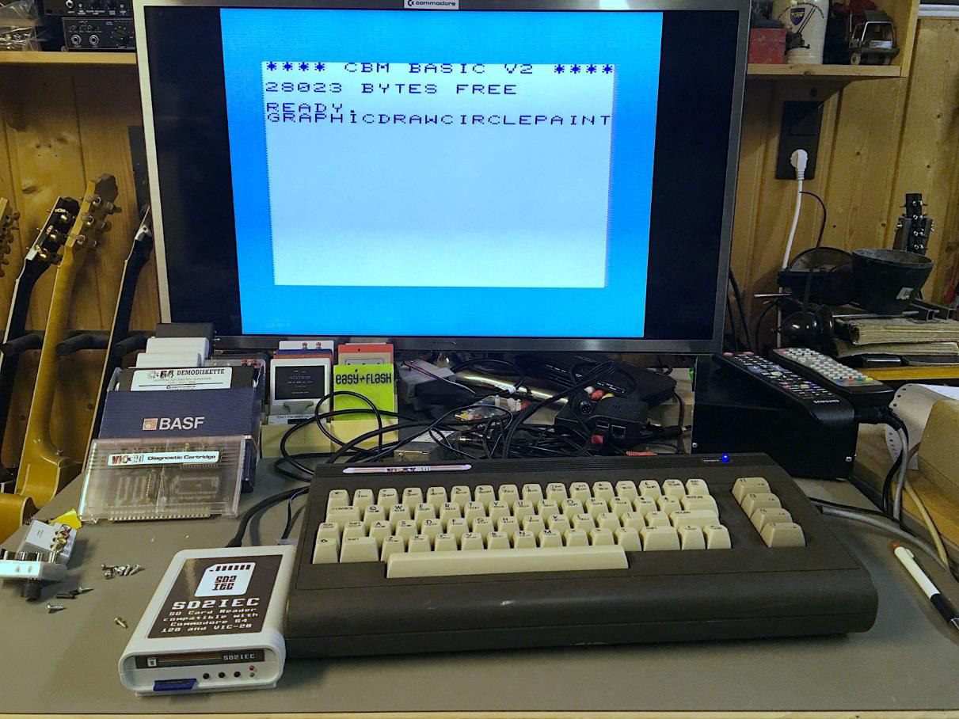
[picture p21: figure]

VIC20_HExpI_Test.docx | | 02.11.2021 16:51
Drafted by Sven Petersen | Page 2 of 7 | Doc.-No.: 171-6-03-02

SW3-8
CS1=CS2

SW3-7
BLK3

SW3-6
BLK1

SW3-5
BLK5

SW3-4
BLK2

SW3-3
A15

SW3-2
A14

SW3-1
A13
off | off | off | on | off | on | on | on

The cartridge was inserted into the VIC-20 and the computer was switched on. It booted normally and 6519 Bytes Free were reported. The Super Expander requires bytes in RAM, so this is correct.

Figure 2: Test with Super Expander Firmware and full RAM expansion

The function keys produce some of the additional Super Expander instructions. A short program, which is using those instructions, was executed successfully.

✓ Function of RAM and EPROM IC1 with BLK5 and the Super Expander Software verified.

SYS11*4096 (which is $B000) started the VIC-MON.

✓ Additional test.

The Super Expander Software was tested with all other RAM configurations, the VIC-20 always booted properly.

### RESET Button

The RESET button (SW1) was pressed. The VIC-20 rebooted properly.

✓ RESET button verified

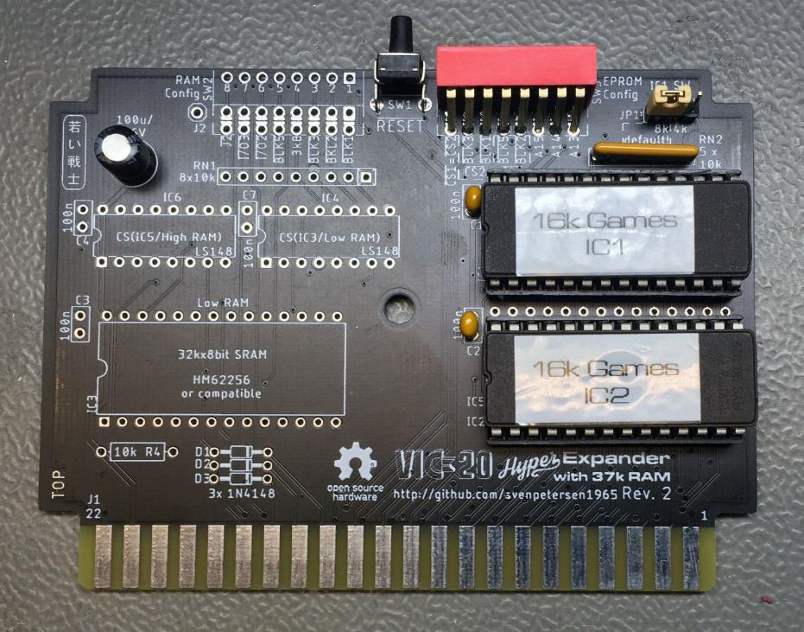
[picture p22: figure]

VIC20_HExpI_Test.docx | | 02.11.2021 16:51
Drafted by Sven Petersen | Page 3 of 7 | Doc.-No.: 171-6-03-02

### VIC-20 Diagnostic Software

The software (PAL) also origins from zimmers.net. It was programmed into the 2nd 8k bank of the said EPROM, a different version of this software (NTSC) was programmed to the 3rd 8k bank.

The EPROM banks were set to the 2nd 8k SW3 switch 5 remained on ( BLK5 ).

SW3-8
CS1=CS2

SW3-7
BLK3

SW3-6
BLK1

SW3-5
BLK5

SW3-4
BLK2

SW3-3
A15

SW3-2
A14

SW3-1
A13
off | off | off | on | off | on | on | off

The RAM was configured to 3k Expansion only.

The diagnostics software started and executed properly (together with the VIC-20 diagnostics harness). For the 2nd version of the diagnostic software, SW3 was set to the 3rd 8k bank

SW3-8 CS1=CS2 | SW3-7 BLK3 | SW3-6 BLK1 | SW3-5 BLK5 | SW3-4 BLK2 | SW3-3 A15 | SW3-2 A14 | SW3-1 A13
off | off | off | on | off | on | off | on

This software executed properly, too.

✓ Bank select (000, 001, 010) on SW3 verified

### Game Cartridge Donkey Kong

This game is a 16k game and requires both EPROMs.
The software for $A000 was programmed in a fresh EPROM, which was inserted into IC1. SW3 remained at BLK5 . The other part of the software, which is located at $2000 was programmed into another fresh EPROM, which was then inserted into the IC2 socket.

Figure 3: Configuration withn two EPROMs

SW3 was set to BLK1 (SW3-1..8: on, on, on,off, on, on, off, off).

VIC20_HExpI_Test.docx | | 02.11.2021 16:51
Drafted by Sven Petersen | Page 4 of 7 | Doc.-No.: 171-6-03-02

SW3-8
CS1=CS2

SW3-7
BLK3

SW3-6
BLK1

SW3-5
BLK5

SW3-4
BLK2

SW3-3
A15

SW3-2
A14

SW3-1
A13
off | off | on | on | off | on | on | on

The software started properly and the game could be played.

✓ EPROM IC2 with BLK1 verified

### Game Cartridge AE

The software origins from zimmers.net. It consisted of two images, one for $A000 and one for $6000. The images were programmed into two EPROMs, the $A000 software was inserted into IC1, the $6000 software into IC2 (chip select BLK3 ).

SW3-8 CS1=CS2 | SW3-7 BLK3 | SW3-6 BLK1 | SW3-5 BLK5 | SW3-4 BLK2 | SW3-3 A15 | SW3-2 A14 | SW3-1 A13
off | on | off | on | off | off | on | on

The software started properly and the game could be played.

✓ EPROM IC2 with BLK3 verified

### VIC-MON (for $4000)

The source of this software is once again zimmers.net. It was programmed into the 5th 8k memory bank (@ buffer address $8000) of an EPROM. The EPROM was inserted into IC1 and SW3 was set to BLK2 .

SW3-8 CS1=CS2 | SW3-7 BLK3 | SW3-6 BLK1 | SW3-5 BLK5 | SW3-4 BLK2 | SW3-3 A15 | SW3-2 A14 | SW3-1 A13
off | off | off | off | on | off | on | on
SYS4*1024 started the software properly.

✓ Bank select (100) on JP3 and BLK2 (JP1) verified

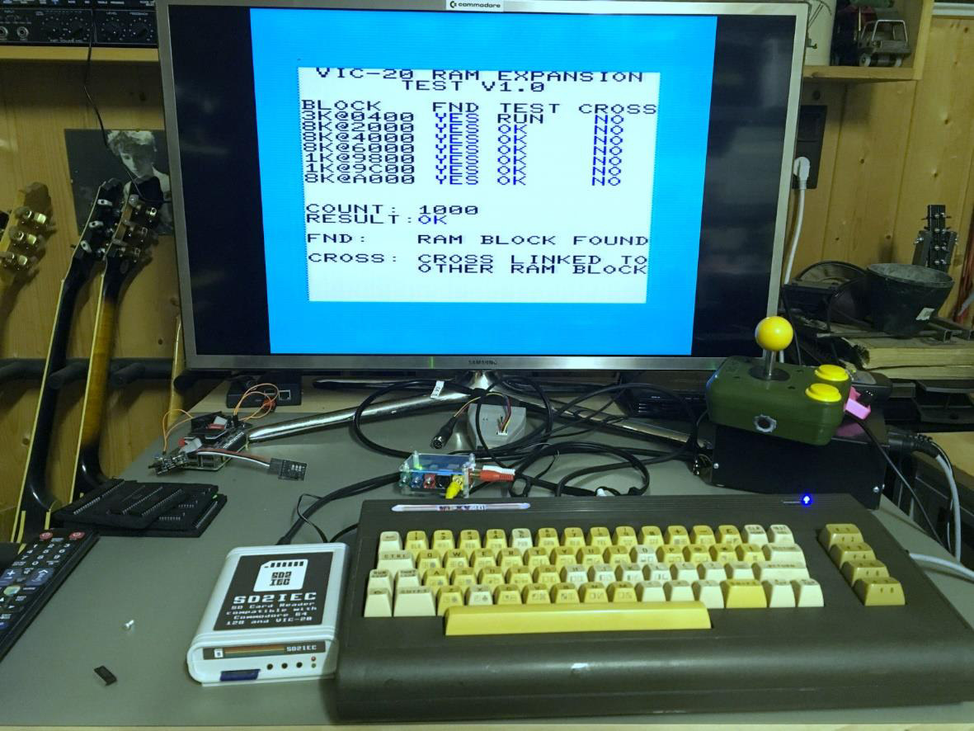
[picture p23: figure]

BLK5; BLK3; BLK2; BLK1; off

VIC20_HExpI_Test.docx | | 02.11.2021 16:51
Drafted by Sven Petersen | Page 5 of 7 | Doc.-No.: 171-6-03-02

### RAM Test

The RAM configuration was tested with the RAM Expansion Test Software Rev. 1.0 (https://github.com/svenpetersen1965/VIC-20-RAM-Expansion-Test-Software)

Figure 4: RAM Expansion Test running from EPROM

The version v1.0 of the RAM Test Software is capable of testing the RAM blocks attached to I/O2 and I/O3 . This software tests every bit in a RAM block for LOW and for HIGH. Also address line conflicts and a cross talk to other RAM blocks are detected.

EPROM configuration:

SW3-8
CS1=CS2

SW3-7
BLK3

SW3-6
BLK1

SW3-5
BLK5

SW3-4
BLK2

SW3-3
A15

SW3-2
A14

SW3-1
A13
off | off | off | on | off | on | off | on

RAM configuration

In the first pass, the RAM Test was running from the on-board EPROM IC1, configured to $A000 with BLK5). The test was running several thousand times without reporting any problems.

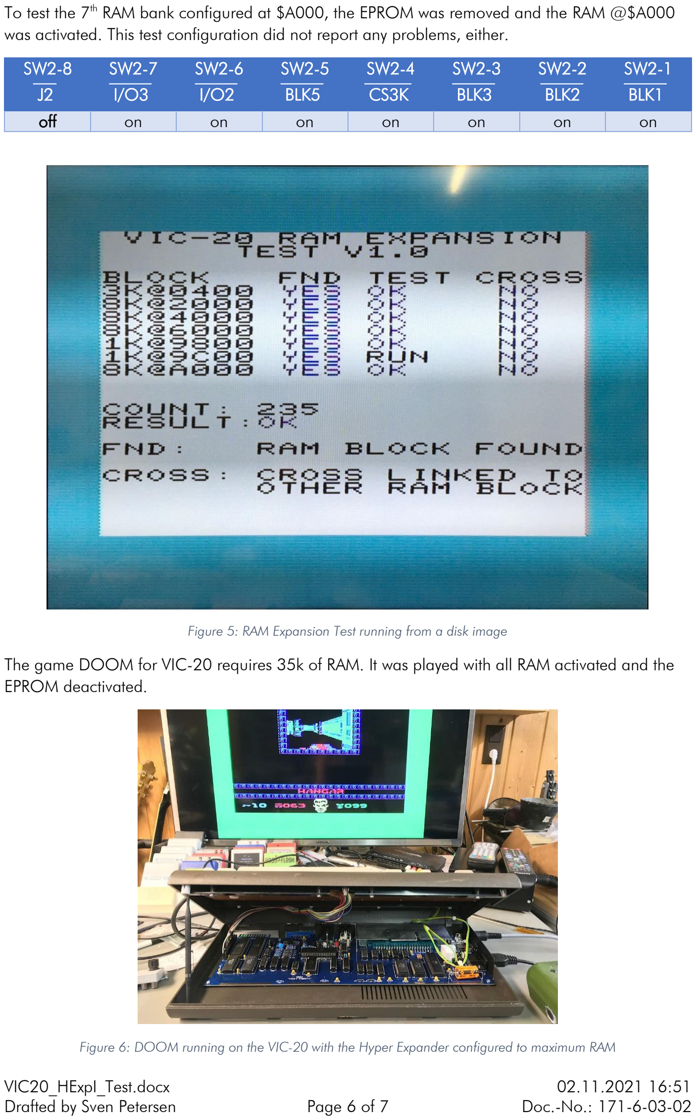
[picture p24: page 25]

VIC20_HExpI_Test.docx | | 02.11.2021 16:51
Drafted by Sven Petersen | Page 6 of 7 | Doc.-No.: 171-6-03-02

To test the 7th RAM bank configured at $A000, the EPROM was removed and the RAM @$A000 was activated. This test configuration did not report any problems, either.

SW2-8
J2

SW2-7
I/O3

SW2-6
I/O2

SW2-5
BLK5

SW2-4
CS3K

SW2-3
BLK3

SW2-2
BLK2

SW2-1
BLK1
off | on | on | on | on | on | on | on

Figure 5: RAM Expansion Test running from a disk image

The game DOOM for VIC-20 requires 35k of RAM. It was played with all RAM activated and the EPROM deactivated.

Figure 6: DOOM running on the VIC-20 with the Hyper Expander configured to maximum RAM

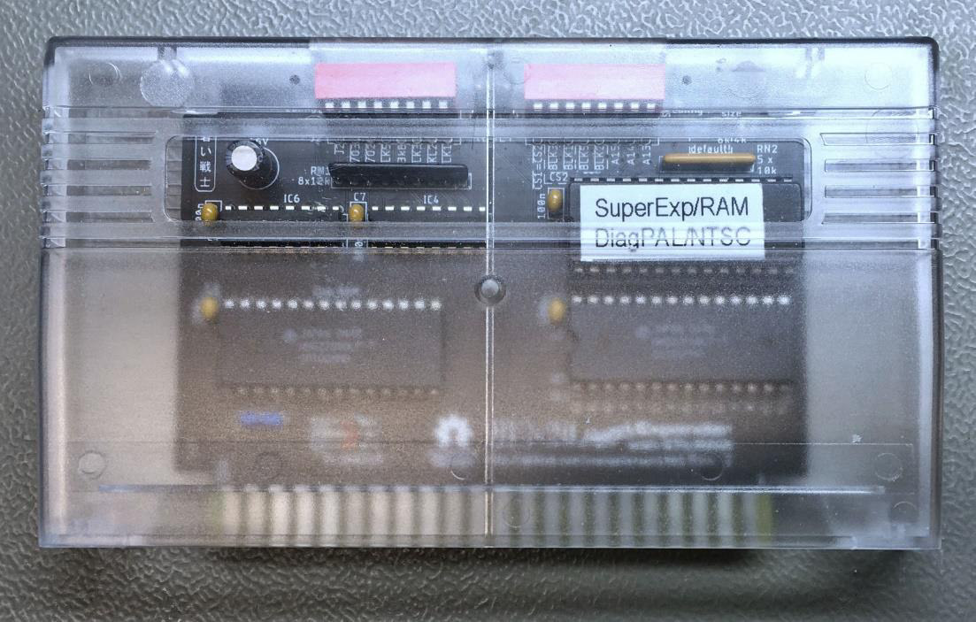
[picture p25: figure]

VIC20_HExpI_Test.docx | | 02.11.2021 16:51
Drafted by Sven Petersen | Page 7 of 7 | Doc.-No.: 171-6-03-02

✓ RAM function verified

### Installation in cartridge cases

Figure 7: Installation in a tfw8bit case

The tfw8bit.com VIC-20 cartridge case fits after removing the support structures for the short PCBs.

In case the RESET switch is desired, the cases require a modification (5mm hole in the back)

✓ Dimensions verified

## Conclusion

The Hyper Expander Rev. 2 is fully functional

Pos. Qty Value Footprint Ref.-No. Comment

1 1 172-2-01-02 2 Layer PCB Rev. 2 2 layer, Cu 35µ, HASL, 102.0mm x 75.0mm, 1.6mm FR4

2 5 100n C-2,5 C1, C2, C3, C4, C7 Ceramic capacitor, pitch 2.5mm (25V or 50V)

3 1 100u/16V C07/2,5 C5 Electrolytic cap, pitch 2.5mm, Ø 7mm

4 1 10k R-10 R4 Metal film resistor, 10% or better

5 3 1N4148 DO-35 D1, D2, D3 Diode

6 2 74LS148 DIL-16 IC4, IC6 TI or other

7 2 DIP-Switch 8, vertical DIP8 SW2, SW3 Vertical DIP-switches are recommended, horizontal are

possible, jumper or solder bridges are an option

8 1 1x2 pin header (2.54mm

pitch)

COMBI-1X2 JP1 standard pin header (option, can be configured with solder

bridge)

9 2 HM62256 DIL28-6 IC3, IC5 Hitachi SRAM, 32k or compatible. E.G. AliExpress

https://www.aliexpress.com/item/4001203718996.html?sp

m=a2g0s.9042311.0.0.22cb4c4dLFzppg, or Reichelt

62256-80

10 1 JPT1236HB JTP_1236HB SW1 Namae Electronics, e.g. Reichelt TASTER 3305B, tme.eu:

TACTA-68N-F

11 1 M27C512-DIP28 DIL28-6 IC1 EPROM: 27C64, 27C128, 27C256 possible. Refere to

document 172-6-01-**

12 1 M27C512-DIP28 DIL28-6 IC2 option, not required for super expander, do not populate for

full RAM

13 3 DIP28-Sockets (IC1), (IC2), (IC3 or IC5) option, refer to IC1, IC2 and IC3

14 1 pinheader 1 pin 1X01 J2 do not populate

15 1 5x10k RN-6 RN2 resistor network, 5 resistors, 6 pins

16 1 8x10k RN-9 RN1 resistor network, 8 resistors, 9 pins

## Commodore VIC-20: Hyper Expander Rev. 2

## Bill of Material Rev. 2.0

Please refer to the Module Description to determin the BOM required for your application

VIC20_HypExp_BOM_v2_0.xlsx

Drafted by Sven Petersen Page 1 of 1

02.11.2021 16:59
Doc.No.: 172-5-01-02.0

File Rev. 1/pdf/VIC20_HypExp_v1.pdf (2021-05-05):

# Project Documentation

## Commodore VIC-20: Hyper Expander

## Project number: 172

## Revision: 1

## Date: 05.05.2021

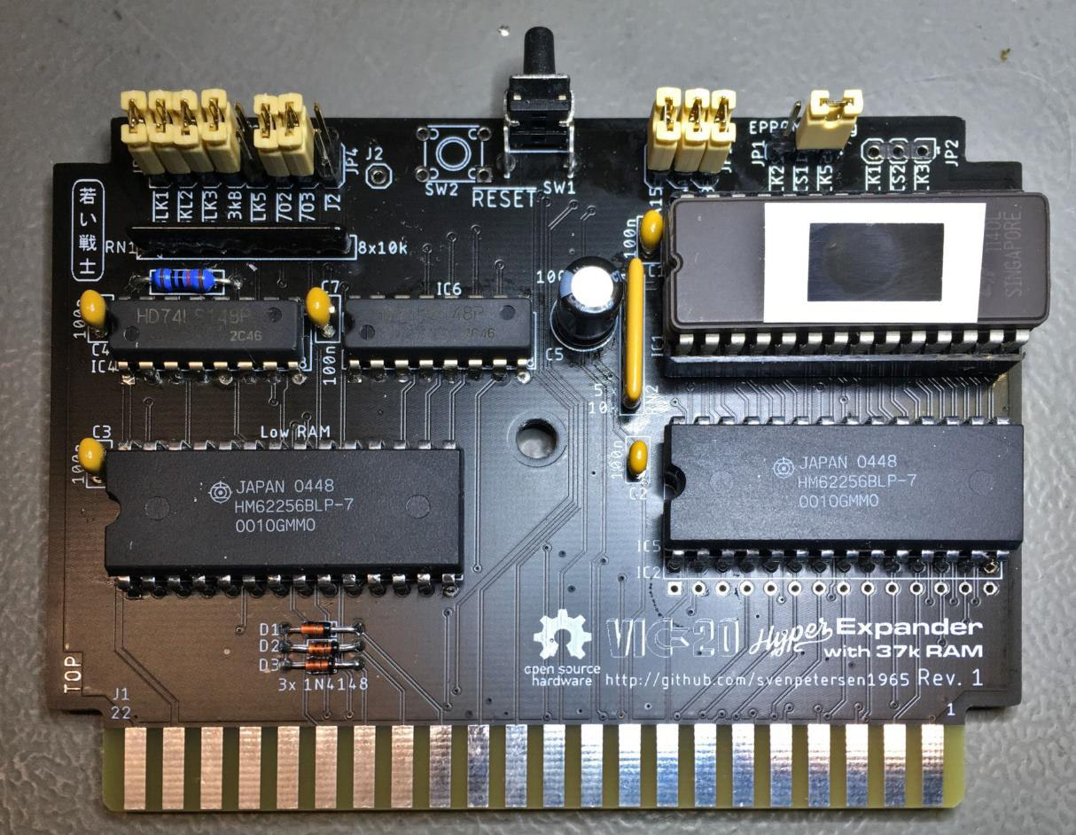
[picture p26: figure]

VIC20_HExp_ModD.docx | | 05.05.2021 18:44
Drafted by Sven Petersen | Page 1 of 7 | Doc.-No.: 172-6-01-01

### Commodore VIC-20: Hyper Expander Rev. 1

### Module Description

Table of Content

## Introduction

The Hyper Expander is a cartridge for the Commodore VIC-20, which provides up to 16kB EPROM and up to 37kB RAM. It is a super-set of the original Commodore VIC-1211A Super Expander, which provides only 3k of RAM.

The Hyper Expander can hold up to two 27C512 EPROMs, the 8k memory bank of both EPROMs (A13...A15) can be selected for both EPROMs. The same selection applies to both of them. Each EPROM (IC1 and IC2) can be jumpered to two chip selects. That is BLK2 or

BLK5 for IC1 and BLK1 or BLK3 for IC2.

The RAM consists of two 32kB 62256 type static RAMs. The memory is divided into four banks each. Two 74LS148 decode the active chip selects to one of each memory bank. The used chip selects can be configured with JP4 and JP5.

VIC20_HExp_ModD.docx | | 05.05.2021 18:44
Drafted by Sven Petersen | Page 2 of 7 | Doc.-No.: 172-6-01-01

## Configuration

### Note

The chip selects of the EPROM and the RAM can be concurrent. The same chip select must not be used for RAM and EPROM at the same time.

### EPROM Chip selects

EPROM | Jumper | Chip Select | VIC-20 Address
IC1 | JP1 | BLK2 | $4000 - $5FFF
| | BLK5 | $A000 - $BFFF
IC2 | JP2 | BLK1 | $2000 - $3FFF
| | BLK3 | $6000 - $7FFF

Table 1: Configurable Chip Selects

In case an EPROM should be deactivated, it is only required to pull JP1 and/or JP2. The chip select then is HIGH (inactive) due to new pull-up resistors.

### RAM Chip Selects

JP5
JP5 activates the chip select signals, that are then decoded and address the respective RAM bank of IC3.
Pin | Chip Select | Addresses
1-2 | BLK1 | $2000 - $3FFF
3-4 | BLK2 | $4000 - $5FFF
5-6 | BLK3 | $6000 - $7FFF
7-8 | CS3K | $0400 - $0FFF

Table 2: Jumper settings JP5

JP4
JP4 activates the chip select signals, that are then decoded and address the respective RAM bank of IC5.
Pin | Chip Select | Addresses
1-2 | BLK5 | $A000 - $BFFF
3-4 | I/O2 | $9800 - $9BFF
5-6 | I/O3 | $9C00 - $9FFF
7-8 | J2 | Unused (experimental)

Table 3: Jumper settings JP5

## BYTES FREE

Be aware, that not all RAM configurations will lead to a more BASIC memory (the BYTES FREE) on switch on. The BASIC memory has to be coherent.

VIC20_HExp_ModD.docx | | 05.05.2021 18:44
Drafted by Sven Petersen | Page 3 of 7 | Doc.-No.: 172-6-01-01

The memory map (screen RAM, BASIC RAM) of the VIC-20 depends on the memory expansion. It will be different for internal RAM and 3k Expansion.

RAM Configuration | BYTES FREE
CS3K | 6655
BLK1 | 11775
CS3K and BLK1 | 11775
BLK1 and BLK2 | 19967
BLK1 , BLK2 and BLK3 | 28159
BLK1 , BLK2 , BLK3 , CS3K and BLK5 | 28159
CS3K , BLK2 , BLK3 | 6655

Table 4: Reported BASIC RAM

RAM that is not visible as BASIC RAM can of course still be accessed. In case an BLK1 is selected, the lowest 3k are not visible as BASIC RAM. In case a memory gap is configured (like BLK2 and BLK3 are configured, but BLK1 is missing, the BASIC RAM consists of the internal RAM and the 3k RAM expansion.

The Super Expander Software (in ROM) requires 136 bytes of RAM. In case this software is activated (it is associated to BLK5 ) the BASIC memory will be reduced by this number of bytes.

## Memory Bank Select (EPROM)

There are two different types of addresses mentioned in this document:

- VIC-20 Address
- EPROM Offset Address

Both types must not be confused! The EPROM Offset Address is the address of the selected memory bank within (the program buffer of the EPROM). This is, where you load the different binary files to the EPROM buffer. One of those memory banks is selected with the Jumper JP3. This appears in/is mapped to the VIC-20 memory at the address determined by the chip select BLK1/2/3/5 (see Table 1).

JP3 | Address Bits | EPROM Address
A15 | A14 | A35 | A15 | A14 | A13 | (Offset)
SET | SET | SET | L | L | L | 0x0000 – 0x1FFF
SET | SET | OPEN | L | L | H | 0x2000 – 0x3FFF
SET | OPEN | SET | L | H | L | 0x4000 – 0x5FFF
SET | OPEN | OPEN | L | H | H | 0x6000 – 0x7FFF
OPEN | SET | SET | H | L | L | 0x8000 – 0x9FFF
OPEN | SET | OPEN | H | L | H | 0xA000 – 0xBFFF
OPEN | OPEN | SET | H | H | L | 0xC000 – 0xDFFF
OPEN | OPEN | OPEN | H | H | H | 0xE000 – 0xFFFF
Table 5: 8k cartridges memory banks

VIC20_HExp_ModD.docx | | 05.05.2021 18:44
Drafted by Sven Petersen | Page 4 of 7 | Doc.-No.: 172-6-01-01

## EPROMs

Four different types/sizes of EPROMs can be used with the Super Expander II, not all settings make sense with them. Their pin out is shown in Table 6.

The effect of the settings and the recommended configurations are shown in Table 7.

27C64

| 27C128
| 27C256
| 27C512
| SOCKET
Vpp | Vpp | Vpp | A15 | 1 A15 | VCC 28 | VCC | VCC | VCC | VCC
A12 | A12 | A12 | A12 | 2 A12 | A14 27 | A14 | A14 | /PGM | /PGM
A7 | A7 | A7 | A7 | 3 A7 | A13 26 | A13 | A13 | A13 | n.c.
A6 | A6 | A6 | A6 | 4 A6 | A8 25 | A8 | A8 | A8 | A8
A5 | A5 | A5 | A5 | 5 A5 | A9 24 | A9 | A9 | A9 | A9
A4 | A4 | A4 | A4 | 6 A4 | A11 23 | A11 | A11 | A11 | A11
A3 | A3 | A3 | A3 | 7 A3 | /OE 22 | /G/Vpp | /G | /G | /G
A2 | A2 | A2 | A2 | 8 A2 | A10 21 | A10 | A10 | A10 | A10
A1 | A1 | A1 | A1 | 9 A1 | GND 20 | /E | /E | /E | /E
A0 | A0 | A0 | A0 | 10 A0 | D7 19 | D7 | D7 | D7 | D7
D0 | D0 | D0 | D0 | 11 D0 | D6 18 | D6 | D6 | D6 | D6
D1 | D1 | D1 | D1 | 12 D1 | D5 17 | D5 | D5 | D5 | D5
D2 | D2 | D2 | D2 | 13 D2 | D4 16 | D4 | D4 | D4 | D4
GND | GND | GND | GND | 14 GND | D3 15 | D3 | D3 | D3 | D3

Table 6: EPROM pin compatibility

EPROM | Size | A15 | A14 | A13
27C512 | 64kx8 | yes | yes | yes
27C256 | 32kx8 | HIGH | yes | yes
27C128 | 16kx8 | HIGH | HIGH | yes
27C64 | 8kx8 | HIGH | HIGH | HIGH
Table 7: Settings per EPROM type

In case Vpp is located at a dedicated pin (pin 1), A15 has no effect anymore. A HIGH level is recommended (switch is off). The /PGM Pin should be set HIGH. The n.c. (not connected) pin should be HIGH (with pull-up resistor) or open.

VIC20_HExp_ModD.docx | | 05.05.2021 18:44
Drafted by Sven Petersen | Page 5 of 7 | Doc.-No.: 172-6-01-01

## Using parallel EEPROMs

There are parallel EPROMs, which fit into the EPROM sockets. They do not require erasing with a UV eraser, like EPROMs, but the price is higher.

Since they can be written, which is controlled by the WE signal, but the Super Expander II cartridge is lacking of this functionality, this signal has to be HIGH (inactive). The 28C256 has the A14 signal connected to Pin 1, which is A15 of the EEPROM socket. This is no problem, but it has to be kept in mind, that the jumper for A15 has effect on the bank select A14 of the EPROM.

28C64

| 28C256
| SOCKET
n.c. | A14 | 1 A15 | VCC 28 | VCC | VCC
A12 | A12 | 2 A12 | A14 27 | /WE | /WE
A7 | A7 | 3 A7 | A13 26 | A13 | n.c
A6 | A6 | 4 A6 | A8 25 | A8 | A8
A5 | A5 | 5 A5 | A9 24 | A9 | A9
A4 | A4 | 6 A4 | A11 23 | A11 | A11
A3 | A3 | 7 A3 | /OE 22 | /G/Vpp | /OE
A2 | A2 | 8 A2 | A10 21 | A10 | A10
A1 | A1 | 9 A1 | GND 20 | /E | /CE
A0 | A0 | 10 A0 | D7 19 | D7 | D7
D0 | D0 | 11 D0 | D6 18 | D6 | D6
D1 | D1 | 12 D1 | D5 17 | D5 | D5
D2 | D2 | 13 D2 | D4 16 | D4 | D4
GND | GND | 14 GND | D3 15 | D3 | D3

Table 8: EEPROM pin compatibility

EEPROM | Size | A15 | A14 | A13
28C256 | 32kx8 | =A14 | OPEN | yes
28C64 | 8kx8 | OPEN | OPEN | OPEN
Table 9: Settings per EEPROM type


VIC20_HExp_ModD.docx | | 05.05.2021 18:44
Drafted by Sven Petersen | Page 6 of 7 | Doc.-No.: 172-6-01-01

## Dimensions

The dimensions of the Hyper Expander are identical to those of the original Super Expander PCB.

Figure 1: Dimensions of the Super Expander II

The PCB fits the original Super Expander cartridge case, another VIC-20 cartridge case from Commodore or the tfw8bit.com cartridge case.

The VIC-20 cartridge cases are high enough to fits the Super Expander II PCB even with the ICs on sockets and vertical jumpers. This has been verified for the Super Expander case and the tfw8bit

### case. The tfw8bit case and the “other Commodore VIC-20” cases require two T-shaped board

supports in the middle of the lower shell to be removed.

## Assembly and BOM

The High RAM (IC5) cannot be installed together with the 2nd EPROM (IC2).

### 2 EPROM Build

Do not place: JP4, IC5 and IC6, C7

### Full RAM Build

Do not place: JP2, IC2

### No RAM, just EPROM

Do not place: IC3, C3, IC4, C4, IC5, IC6, C6, RN1, D1-3, R4, JP5, JP4

### Other Options

SW2 is a vertical RESET switch, while SW1 is the horizontal option. It is only required to place one.

JP4 and JP5 are in the same grid. If bother are required (for full RAM), one 8x2 pin header can be installed.

VIC20_HExp_ModD.docx | | 05.05.2021 18:44
Drafted by Sven Petersen | Page 7 of 7 | Doc.-No.: 172-6-01-01

## Revision History

### Rev. 0

- Prototype: Fully functional.

### Rev. 1

- Second optional RAM (IC5, “High RAM”) to provide the maximum possible RAM
- All jumpers moved to the front edge, so they can be accessed while the cartridge is installed
- Optional vertical RESET switch
- Resistor networks for many pull ups reduce the required space
- Pull ups for the EPROM chip selects










VIC20_HExp_FunD.docx | | 05.05.2021 17:56
Drafted by Sven Petersen | Page 1 of 1 | Doc.-No.: 172-6-02-01

### Commodore VIC-20: Hyper Expander Rev. 1

### Functional Description

The EPROM part with IC1 and IC2 is pretty much a straight forward VIC-20 EPROM cartridge.

### The data bus (D0…D7) and the address bus (A0…A12) are connected to the EPROM. This allows to address 8k of memory. The address bit A13…A15 can be jumpered (JP3), which

results in selectable 8k memory banks.

The chip selects can be set for each EPROM differently (JP1 and JP2). It is not every chip select possible to use with IC1 and IC2.

IC3 and IC5 are static RAMs (32kByte each). Again, the data bus (D0…D7) and the address bus (A0…A12) is connected to both ICs, which results in an 8k RAM bank size. These four RAM banks are selected with the signals RA13 and RA14 (IC3 = Low RAM)) and RAB13 and RAB14 (IC5 = High RAM)). Those additional address signals are generated by the 8 to 3 decoder IC4 and IC6 for the High RAM). If one of the chip selects gets LOW, the signal CSRAM1 or CSRAM2 gets LOW, too. This is forming the chip select signal of IC3/IC5.

The three chip select signals for the 3k RAM expansion are originally made for addressing 2114 1kx4 RAMs. Since the 4th RAM block is addressed with the 3k chip selects RAM1..3 , those need to be combined to a single chip select, which is accomplished with D1, D2 and D3 and the pull-up resistor R4. In case one of those signals is LOW, the combined CS3K is LOW as well.

The 2nd EPROM IC2 is optional and can only be installed, in case the High RAM IC5 is not installed. In this case, IC6 and JP4 are not required.


VIC20_HExpI_Test.docx | | 05.05.2021 21:03
Drafted by Sven Petersen | Page 1 of 6 | Doc.-No.: 171-6-03-01

### Commodore VIC-20: Hyper Expander Rev. 1

### Testing

## Test Setup

The tests were conducted with a VickyTwenty (a reproduction of the VIC-20 ASSY 250403) and a Hyper Expander cartridge (Rev. 1) with two HN61256BLP-7 RAM and up to two 27C512 EPROMs.

Figure 1: Prototype of Hyper Expander Rev. 1

## Test Execution

### Super Expander Software

First, the original Super Expander Software from zimmers.net and the VIC-MON for $B000 were programed to an EPROM. These two programs fit into one 8k memory bank, since the Super Expander software is a 4k software. The EPROM was inserted the in IC1 socket and CS1 (JP1) was

set to BLK5 ($A000-$BFFF). The RAM was configured to 3k RAM expansion only (JP4=3k, J5: 7-8 only = BLK5/3k).

The cartridge was inserted into the VIC-20 and the computer was switched on. It booted normally and 6519 Bytes Free were reported. The Super Expander requires bytes in RAM, so this is correct.


VIC20_HExpI_Test.docx | | 05.05.2021 21:03
Drafted by Sven Petersen | Page 2 of 6 | Doc.-No.: 171-6-03-01

Figure 2: Test with Super Expander Firmware and full RAM expansion

The function keys produce some of the additional Super Expander instructions. A short program, which is using those instructions, was executed successfully.

✓ Function of RAM and EPROM IC1 with BLK5 and the Super Expander Software verified.

SYS11*4096 (which is $B000) started the VIC-MON.

✓ Additional test.

The Super Expander Software was tested with all other RAM configurations, the VIC-20 always booted properly.

### RESET Button

The RESET button (SW1) was pressed. The VIC-20 rebooted properly. The same applies to SW2.

✓ RESET button verified

### VIC-20 Diagnostic Software

The software (PAL) also origins from zimmers.net. It was programmed into the 2nd 8k of the said EPROM, a different version of this software (NTSC) was programmed to the 3rd 8k.

The jumpers on JP3 were set to the 2nd 8k (A15...A13: set open), JP1 remained at BLK5 .

The RAM was configured to 3k Expansion only.

The diagnostics software started and executed properly (together with the VIC-20 diagnostics harness). For the 2nd version of the diagnostic software, JP3 was set to the 3rd 8k bank (A15...A13: set open set). This software executed properly, too.


VIC20_HExpI_Test.docx | | 05.05.2021 21:03
Drafted by Sven Petersen | Page 3 of 6 | Doc.-No.: 171-6-03-01

✓ Bank select (000, 001, 010) on JP3 verified

### Game Cartridge Donkey Kong

This game is a 16k game and requires both EPROMs.
The software for $A000 was programmed in a fresh EPROM, which was inserted into IC1. JP1 remained at BLK5 . The other part of the software, which is located at $2000 was programmed into another fresh EPROM, which was then inserted into the IC2 socket.

Figure 3: Configuration withn two EPROMs

JP2 was set to BLK1 . All jumpers on JP3 were set. The software started properly and the game could be played.

✓ EPROM IC2 with BLK1 verified

### Game Cartridge AE

The software origins from zimmers.net. It consisted of two images, one for $A000 and one for $6000. The images were programmed into two EPROMs, the $A000 software was inserted into IC1, the $6000 software into IC2. Jumper JP1 was set to BLK5 , JP2 to BLK3 . The software started properly and the game could be played.

✓ EPROM IC2 with BLK3 verified

### VIC-MON (for $4000)

The source of this software is once again zimmers.net. It was programmed into the 5th 8k memory bank (@ buffer address $8000) of an EPROM. The EPROM was inserted into IC1 and JP1 was set to BLK2 .

SYS4x1022 started the software properly.

✓ Bank select (100) on JP3 and BLK2 (JP1) verified


VIC20_HExpI_Test.docx | | 05.05.2021 21:03
Drafted by Sven Petersen | Page 4 of 6 | Doc.-No.: 171-6-03-01

### RAM Test

The RAM configuration was tested with the RAM Expansion Test Software Rev. 1.0 (https://github.com/svenpetersen1965/VIC-20-RAM-Expansion-Test-Software)

Figure 4: RAM Expansion Test running from EPROM

The version v1.0 of the RAM Test Software is capable of testing the RAM blocks attached to I/O2 and I/O3 . This software tests every bit in a RAM block for LOW and for HIGH. Also address line conflicts and a cross talk to other RAM blocks are detected.

In the first pass, the RAM Test was running from the on-board EPROM IC1, configured to $A000 with BLK5). The test was running several thousand times without reporting any problems.

To test the 7th RAM bank configured at $A000, the EPROM was removed and the JP4 was set to BLK5. This test configuration did not report any problems, either.


VIC20_HExpI_Test.docx | | 05.05.2021 21:03
Drafted by Sven Petersen | Page 5 of 6 | Doc.-No.: 171-6-03-01

Figure 5: RAM Expansion Test running from a disk image

The game DOOM for VIC-20 requires 35k of RAM. It was played with all RAM activated and the EPROM deactivated.

Figure 6: DOOM running on the VIC-20 with the Hyper Expander configured to maximum RAM


VIC20_HExpI_Test.docx | | 05.05.2021 21:03
Drafted by Sven Petersen | Page 6 of 6 | Doc.-No.: 171-6-03-01

✓ RAM function verified

### Installation in cartridge cases

The fully assembled Hyper Expander PCB (all ICs on sockets and all vertical jumpers) was installed in the original Commodore Super Expander cartridge case. This could be accomplished without a problem.

Figure 7: Installation in a tfw8bit case

The original Commodore Game cartridge case required removing some support structures for small PCBs, after that, it also fit.

The tfw8bit.com VIC-20 cartridge case fits after removing the support structures for the short PCBs.

In case the RESET switch is desired, the cases require a modification (5mm hole in the back)

✓ Dimensions verified

## Conclusion

The Hyper Expander Rev. 1 is fully functional

Pos. Qty Value Footprint Ref.-No. Comment

1 1 172-2-01-01 2 Layer PCB Rev. 1 2 layer, Cu 35µ, HASL, 102.0mm x 75.0mm, 1.6mm FR4

2 5 100n C-2,5 C1, C2, C3, C4, C7 Ceramic capacitor, pitch 2.5mm (25V or 50V)

3 1 100u/16V C07/2,5 C5 Electrolytic cap, pitch 2.5mm, Ø 7mm

4 1 10k R-10 R4 Metal film resistor, 10% or better

5 3 1N4148 DO-35 D1, D2, D3 Diode

6 2 74LS148 DIL-16 IC4, IC6 TI or other

7 2 1x3 pin header (2.54mm

pitch)

COMBI-3P JP1, JP2 standard pin header (option, can be configured with solder

bridge)

8 1 3X2 pin header (2.54mm

pitch)

COMBI-3X2 JP3 standard pin header (option, can be configured with solder

bridge)

9 1 8X2 pin header (2.54mm

pitch)

COMBI-4X2 JP4 and JP5 standard pin header (option, can be configured with solder

bridge), JP4 and JP5 share the same raster, one component

can be püopulated

10 2 HM62256 DIL28-6 IC3, IC5 Hitachi SRAM, 32k or compatible. E.G. AliExpress

https://www.aliexpress.com/item/4001203718996.html?sp

m=a2g0s.9042311.0.0.22cb4c4dLFzppg, or Reichelt

62256-80

11 1 JPT1236HB JTP_1236HB SW1 Namae Electronics, e.g. Reichelt TASTER 3305B, tme.eu:

TACTA-68N-F

12 1 6x6mm tact switch SW2 alternative to SW1

12 1 M27C512-DIP28 DIL28-6 IC1 EPROM: 27C64, 27C128, 27C256 possible. Refere to

document 172-6-01-**

13 1 M27C512-DIP28 DIL28-6 IC2 option, not required for super expander, do not populate for

full RAM

14 3 DIP28-Sockets (IC1), (IC2), (IC3 or IC5) option, refer to IC1, IC2 and IC3

15 1 pinheader 1 pin 1X01 J2 do not populate

16 1 5x10k RN-6 RN2 resistor network, 5 resistors, 6 pins

17 1 8x10k RN-9 RN1 resistor network, 8 resistors, 9 pins

## Commodore VIC-20: Hyper Expander Rev. 1

## Bill of Material Rev. 1.0

Please refer to the Module Description to determin the BOM required for your application

VIC20_HypExp_BOM_v1_0.xlsx

Drafted by Sven Petersen Page 1 of 1

05.05.2021 21:06
Doc.No.: 172-5-01-01.0

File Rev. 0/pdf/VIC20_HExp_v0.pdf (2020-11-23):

# Project Documentation

## Commodore VIC-20: Hyper Expander

## Project number: 172

## Revision: 0

## Date: 02.11.2020


VIC20_HExp_ModD.docx | | 23.11.2020 20:33
Drafted by Sven Petersen | Page 1 of 6 | Doc.-No.: 172-6-01-00

### Commodore VIC-20: Hyper Expander Rev. 0

### Module Description

Table of Content

## Introduction

The Hyper Expander is a cartridge for the Commodore VIC-20, which provides up to 16kB EPROM and up to 32kB RAM. It is a super-set of the original Commodore VIC-1211A Super Expander, which provides only 3k of RAM.

The Hyper Expander can hold up to two 27C512 EPROMs, the 8k memory bank of both EPROMs (A13...A15) can be selected for both EPROMs. The same selection applies to both of them. Each EPROM (IC1 and IC2) can be jumpered to two chip selects. That is BLK2 or

BLK5 for IC1 and BLK1 or BLK3 for IC2.

The RAM is a 32kB 62256 type static RAM. The memory is divided into four banks. A 74LS148 decodes the active chip selects to one of each memory bank. The used chip selects can be configured with JP5 and JP4.

## Configuration

### Note

The chip selects of the EPROM and the RAM can be concurrent. The same chip select must not be used for RAM and EPROM at the same time.

VIC20_HExp_ModD.docx | | 23.11.2020 20:33
Drafted by Sven Petersen | Page 2 of 6 | Doc.-No.: 172-6-01-00

### EPROM Chip selects

EPROM | Jumper | Chip Select | VIC-20 Address
IC1 | JP1 | BLK2 | $4000 - $5FFF
| | BLK5 | $A000 - $BFFF
IC2 | JP2 | BLK1 | $2000 - $3FFF
| | BLK3 | $6000 - $7FFF

Table 1: Configurable Chip Selects

### RAM Chip Selects

JP4

JP4 selects between the three RAM chip selects ( RAM1 , RAM2 and RAM3 ) which are

merged to a single chip selects by the diode AND (D1…D3) to CS3K or BLK5 . Both, the 3k

Expansion and the 8k Expansion of BLK5 cannot be configured at the same time.

JP5
JP5 activates the chip select signals, that are then decoded and address the respective RAM bank.
Pin | Chip Select | Addresses
1-2 | BLK1 | $2000 - $3FFF
3-4 | BLK2 | $4000 - $5FFF
5-6 | BLK3 | $6000 - $7FFF
7-8 | CS3K or BLK5 | $0400 - $0FFF or $A000 - $BFFF (see JP4)

Table 2: Jumper settings JP5

## BYTES FREE

Be aware, that not all RAM configurations will lead to a more BASIC memory (the BYTES FREE) on switch on. The BASIC memory has to be coherent.

The memory map (screen RAM, BASIC RAM) of the VIC-20 depends on the memory expansion. It will be different for internal RAM and 3k Expansion.

RAM Configuration | BYTES FREE
CS3K
| 6655
| 11775
CS3K and BLK1 | 11775
BLK1 and BLK2 | 19967
BLK1 , BLK2 and BLK3 | 28159
BLK1 , BLK2 , BLK3 and BLK5 | 28159
CS3K , BLK2 , BLK3 | 6655

BLK1

Table 3: Reported BASIC RAM

VIC20_HExp_ModD.docx | | 23.11.2020 20:33
Drafted by Sven Petersen | Page 3 of 6 | Doc.-No.: 172-6-01-00

RAM that is not visible as BASIC RAM can of course still be accessed. In case an BLK1 is selected, the lowest 3k are not visible as BASIC RAM. In case a memory gap is configured (like BLK2 and BLK3 are configured, but BLK1 is missing, the BASIC RAM consists of the internal RAM and the 3k RAM expansion.

The Super Expander Software (in ROM) requires 136 bytes of RAM. In case this software is activated (it is associated to BLK5 ) the BASIC memory will be reduced by this number of bytes.

## Memory Bank Select (EPROM)

There are two different types of addresses mentioned in this document:

- VIC-20 Address
- EPROM Offset Address

Both types must not be confused! The EPROM Offset Address is the address of the selected memory bank within (the program buffer of the EPROM). This is, where you load the different binary files to the EPROM buffer. One of those memory banks is selected with the Jumper JP3. This appears in/is mapped to the VIC-20 memory at the address determined by the chip select BLK1/2/3/5 (see Table 1).

JP3 | Address Bits | EPROM Address
A15 | A14 | A35 | A15 | A14 | A13 | (Offset)
SET | SET | SET | L | L | L | 0x0000 – 0x1FFF
SET | SET | OPEN | L | L | H | 0x2000 – 0x3FFF
SET | OPEN | SET | L | H | L | 0x4000 – 0x5FFF
SET | OPEN | OPEN | L | H | H | 0x6000 – 0x7FFF
OPEN | SET | SET | H | L | L | 0x8000 – 0x9FFF
OPEN | SET | OPEN | H | L | H | 0xA000 – 0xBFFF
OPEN | OPEN | SET | H | H | L | 0xC000 – 0xDFFF
OPEN | OPEN | OPEN | H | H | H | 0xE000 – 0xFFFF
Table 4: 8k cartridges memory banks

VIC20_HExp_ModD.docx | | 23.11.2020 20:33
Drafted by Sven Petersen | Page 4 of 6 | Doc.-No.: 172-6-01-00

## EPROMs

Four different types/sizes of EPROMs can be used with the Super Expander II, not all settings make sense with them. Their pin out is shown in Table 5.

The effect of the settings and the recommended configurations are shown in Table 6.

27C64

27C128

27C256

27C512

SOCKET

Vpp | Vpp | Vpp | A15 | 1 A15 | VCC 28 VCC | VCC VCC | VCC
A12 | A12 | A12 | A12 | 2 A12 | A14 27 A14 | A14 | /PGM /PGM
A7 | A7 | A7 | A7 | 3 A7 | A13 26 A13 | A13 | A13 | n.c.
A6 | A6 | A6 | A6 | 4 A6 | A8 25 A8 | A8 | A8 | A8
A5 | A5 | A5 | A5 | 5 A5 | A9 24 A9 | A9 | A9 | A9
A4 | A4 | A4 | A4 | 6 A4 | A11 23 A11 | A11 | A11 | A11
A3 | A3 | A3 | A3 | 7 A3 | /OE 22 /G/Vpp /G | /G | /G
A2 | A2 | A2 | A2 | 8 A2 | A10 21 A10 | A10 | A10 | A10
A1 | A1 | A1 | A1 | 9 A1 | GND 20 /E | /E | /E | /E
A0 | A0 | A0 | A0 10 A0 | D7 19 D7 | D7 | D7 | D7
D0 | D0 | D0 | D0 11 D0 | D6 18 D6 | D6 | D6 | D6
D1 | D1 | D1 | D1 12 D1 | D5 17 D5 | D5 | D5 | D5
D2 | D2 | D2 | D2 13 D2 | D4 16 D4 | D4 | D4 | D4
GND GND GND | GND 14 GND | D3 15 D3 | D3 | D3 | D3

Table 5: EPROM pin compatibility

EPROM | Size | A15 | A14 | A13
27C512 | 64kx8 | yes | yes | yes
27C256 | 32kx8 | HIGH | yes | yes
27C128 | 16kx8 | HIGH | HIGH | yes
27C64 | 8kx8 | HIGH | HIGH | HIGH
Table 6: Settings per EPROM type

In case Vpp is located at a dedicated pin (pin 1), A15 has no effect anymore. A HIGH level is recommended (switch is off). The /PGM Pin should be set HIGH. The n.c. (not connected) pin should be HIGH (with pull-up resistor) or open.

VIC20_HExp_ModD.docx | | 23.11.2020 20:33
Drafted by Sven Petersen | Page 5 of 6 | Doc.-No.: 172-6-01-00

## Using parallel EEPROMs

There are parallel EPROMs, which fit into the EPROM sockets. They do not require erasing with a UV eraser, like EPROMs, but the price is higher.

Since they can be written, which is controlled by the WE signal, but the Super Expander II cartridge is lacking of this functionality, this signal has to be HIGH (inactive). The 28C256 has the A14 signal connected to Pin 1, which is A15 of the EEPROM socket. This is no problem, but it has to be kept in mind, that the jumper for A15 has effect on the bank select A14 of the EPROM.

28C64

28C256

SOCKET

n.c. A14 | 1 A15 | VCC 28 | VCC | VCC
A12 | A12 | 2 A12 | A14 27 | /WE | /WE
A7 | A7 | 3 A7 | A13 26 | A13 | n.c
A6 | A6 | 4 A6 | A8 25 | A8 | A8
A5 | A5 | 5 A5 | A9 24 | A9 | A9
A4 | A4 | 6 A4 | A11 23 | A11 | A11
A3 | A3 | 7 A3 | /OE 22 | /G/Vpp /OE
A2 | A2 | 8 A2 | A10 21 | A10 | A10
A1 | A1 | 9 A1 | GND 20 | /E | /CE
A0 | A0 | 10 A0 | D7 19 | D7 | D7
D0 | D0 | 11 D0 | D6 18 | D6 | D6
D1 | D1 | 12 D1 | D5 17 | D5 | D5
D2 | D2 | 13 D2 | D4 16 | D4 | D4
GND | GND | 14 GND | D3 15 | D3 | D3

Table 7: EEPROM pin compatibility

EEPROM | Size | A15 | A14 | A13
28C256 | 32kx8 | =A14 | OPEN | yes
28C64 | 8kx8 | OPEN | OPEN | OPEN
Table 8: Settings per EEPROM type


VIC20_HExp_ModD.docx | | 23.11.2020 20:33
Drafted by Sven Petersen | Page 6 of 6 | Doc.-No.: 172-6-01-00

## Dimensions

The dimensions of the Hyper Expander are identical to those of the original Super Expander PCB.

Figure 1: Dimensions of the Super Expander II

The PCB fits the original Super Expander cartridge case, another VIC-20 cartridge case from Commodore or the tfw8bit.com cartridge case.

The VIC-20 cartridge cases are high enough to fits the Super Expander II PCB even with the ICs on sockets and vertical jumpers. This has been verified for the Super Expander case and the tfw8bit

### case. The tfw8bit case and the “other Commodore VIC-20” cases require two T-shaped board

supports in the middle of the lower shell to be removed.

## Revision History

### Rev. 0

- Prototype: Fully functional.









VIC20_HExp_FunD.docx | | 23.11.2020 19:34
Drafted by Sven Petersen | Page 1 of 1 | Doc.-No.: 172-6-02-00

### Commodore VIC-20: Hyper Expander Rev. 0

### Functional Description

The EPROM part with IC1 and IC2 is pretty much a straight forward VIC-20 EPROM cartridge. The data bus (D0…D7) and the address bus (A0…A12) are connected to the EPROM. This allows to address 8k of memory. The address bit A13…A15 can be jumpered (JP3), which results in selectable 8k memory banks.

The chip selects can be set for each EPROM differently (JP1 and JP2). It is not every chip select possible to use with IC1 and IC2.

IC3 is a static 32kB RAM. Again, the data bus (D0…D7) and the address bus (A0…A12) is connected to IC3, which results in an 8k RAM bank size. These four RAM banks are selected with the signals RA13 and RA14. Those additional address signals are generated by the 8 to 3 decoder IC4. If one of the chip selects gets LOW, the signal CSRAM gets LOW, too. This is forming the chip select signal of IC3.

The three chip select signals for the 3k RAM expansion are originally made for addressing 2114 1kx4 RAMs. Since the 4th RAM block is either addressed with BLK5 or the 3k chip

selects RAM1..3 , those need to be combined to a single chip select, which is accomplished with D1, D2 and D3 and the pull-up resistor R4. In case one of those signals is LOW, the combined CS3K is LOW as well.


VIC20_HExpI_Test.docx | | 23.11.2020 20:31
Drafted by Sven Petersen | Page 1 of 5 | Doc.-No.: 171-6-03-00

### Commodore VIC-20: Hyper Expander Rev. 0

### Testing

## Test Setup

The tests were conducted with a VIC-20 (ASSY 250403 Rev. D) and a Hyper Expander cartridge (Rev. 0) with a HN61256BLP-7 RAM and up to two 27C512 EPROMs.

## Test Execution

### Super Expander Software

First, the original Super Expander Software from zimmers.net and the VIC-MON for $B000 were programed to an EPROM. These two programs fit into one 8k memory bank, since the Super Expander software is a 4k software. The EPROM was inserted the in IC1 socket and CS1 (JP1) was

set to BLK5 ($A000-$BFFF). The RAM was configured to 3k RAM expansion only (JP4=3k, J5: 7-8 only = BLK5/3k).

The cartridge was inserted into the VIC-20 and the computer was switched on. It booted normally and 6519 Bytes Free were reported. The Super Expander requires bytes in RAM, so this is correct.

Figure 1: Test with Super Expander Firmware and full RAM expansion

The function keys produce some of the additional Super Expander instructions. A short program, which is using those instructions, was executed successfully.

✓ Function of RAM and EPROM IC1 with BLK5 and the Super Expander Software verified.

SYS11*4096 (which is $B000) started the VIC-MON.

VIC20_HExpI_Test.docx | | 23.11.2020 20:31
Drafted by Sven Petersen | Page 2 of 5 | Doc.-No.: 171-6-03-00

✓ Additional test.

The Super Expander Software was tested with all other RAM configurations, the VIC-20 always booted properly.

### RESET Button

The RESET button (SW1) was pressed. The VIC-20 rebooted properly.

✓ RESET button verified

### VIC-20 Diagnostic Software

The software (PAL) also origins from zimmers.net. It was programmed into the 2nd 8k of the said EPROM, a different version of this software (NTSC) was programmed to the 3rd 8k.

The jumpers on JP3 were set to the 2nd 8k (A15...A13: set open), JP1 remained at BLK5 .

The RAM was configured to 3k Expansion only.

The diagnostics software started and executed properly (together with the VIC-20 diagnostics harness). For the 2nd version of the diagnostic software, JP3 was set to the 3rd 8k bank (A15...A13: set open set). This software executed properly, too.

✓ Bank select (000, 001, 010) on JP3 verified

### Game Cartridge Donkey Kong

This game is a 16k game and requires both EPROMs.
The software for $A000 was programmed in a fresh EPROM, which was inserted into IC1. JP1 remained at BLK5 . The other part of the software, which is located at $2000 was programmed

into another fresh EPROM, which was then inserted into the IC2 socket. JP2 was set to BLK1 . All jumpers on JP3 were set.

The software started properly and the game could be played.

✓ EPROM IC2 with BLK1 verified

### Game Cartridge AE

The software origins from zimmers.net. It consisted of two images, one for $A000 and one for $6000. The images were programmed into two EPROMs, the $A000 software was inserted into IC1, the $6000 software into IC2. Jumper JP1 was set to BLK5 , JP2 to BLK3 . The software started properly and the game could be played.

✓ EPROM IC2 with BLK3 verified

### VIC-MON (for $4000)

The source of this software is once again zimmers.net. It was programmed into the 5th 8k memory bank (@ buffer address $8000) of an EPROM. The EPROM was inserted into IC1 and JP1 was set to BLK2 .

SYS4x1022 started the software properly.


VIC20_HExpI_Test.docx | | 23.11.2020 20:31
Drafted by Sven Petersen | Page 3 of 5 | Doc.-No.: 171-6-03-00

✓ Bank select (100) on JP3 and BLK2 (JP1) verified

### RAM Test

The RAM configuration was tested with the RAM Expansion Test Software Rev. 0.0 (https://github.com/svenpetersen1965/VIC-20-RAM-Expansion-Test-Software)

This software tests every bit in a RAM block for LOW and for HIGH. Also address line conflicts and a cross talk to other RAM blocks are detected.

In the first pass, the RAM Test was running from the on-board EPROM IC1, configured to $A000 with BLK5). The 4th RAM block was configured to be the 3kByte RAM expansion.

The test was running several thousand times without reporting any problems.

Figure 2: RAM Expansion Test running from EPROM

To test the 4th RAM bank configured at $A000, the EPROM was removed and the JP4 was set to BLK5.

This test configuration did not report any problems, either.


VIC20_HExpI_Test.docx | | 23.11.2020 20:31
Drafted by Sven Petersen | Page 4 of 5 | Doc.-No.: 171-6-03-00

Figure 3: RAM Expansion Test running from a disk image

✓ RAM function verified

### Installation in cartridge cases

The fully assembled Hyper Expander PCB (all ICs on sockets and all vertical jumpers) was installed in the original Commodore Super Expander cartridge case. This could be accomplished without a problem.

Figure 4: Installation in a tfw8bit case

VIC20_HExpI_Test.docx | | 23.11.2020 20:31
Drafted by Sven Petersen | Page 5 of 5 | Doc.-No.: 171-6-03-00

The original Commodore Game cartridge case required removing some support structures for small PCBs, after that, it also fit.

The tfw8bit.com VIC-20 cartridge case fits after removing the support structures for the short PCBs.

In case the RESET switch is desired, the cases require a modification (5mm hole in the back)

✓ Dimensions verified

## Conclusion

The Hyper Expander Rev. 0 is fully functional

Pos. Qty Value Footprint Ref.-No. Comment

1 1 172-2-01-00 2 Layer PCB Rev. 0 2 layer, Cu 35µ, HASL, 102.0mm x 75.0mm, 1.6mm FR4

2 4 100n C-2,5 C1, C2, C3, C4 Ceramic capacitor, pitch 2.5mm (25V or 50V)

3 1 100u/16V C07/2,5 C5 Electrolytic cap, pitch 2.5mm, Ø 7mm

4 8 10k R-10 R1, R2, R3, R4, R5, R6, R7, R8 Metal film resistor, 10% or better

5 3 1N4148 DO-35 D1, D2, D3 Diode

6 1 74LS148 DIL-16 IC4 TI or other

7 3 1x3 pin header (2.54mm

pitch)

COMBI-3P JP1, JP2 standard pin header (option, can be configured with solder

bridge)

8 1 3X2 pin header (2.54mm

pitch)

COMBI-3X2 JP3 standard pin header (option, can be configured with solder

bridge)

9 1 4X2 pin header (2.54mm

pitch)

COMBI-4X2 JP5 standard pin header (option, can be configured with solder

bridge)

10 1 HM62256 DIL28-6 IC3 Hitachi SRAM, 32k or compatible. E.G. AliExpress

https://www.aliexpress.com/item/4001203718996.html?sp

m=a2g0s.9042311.0.0.22cb4c4dLFzppg

11 1 JPT1236HB JTP_1236HB SW1 Namae Electronics, e.g. Reichelt TASTER 3305B, tme.eu:

TACTA-68N-F

12 1 M27C512-DIP28 DIL28-6 IC1 EPROM: 27C64, 27C128, 27C256 possible. Refere to

document 172-6-01-**

13 1 M27C512-DIP28 DIL28-6 IC2 option, not required for super expander

14 3 DIP28-Sockets (IC1), (IC2), (IC3) option, refer to IC1, IC2 and IC3

## Commodore VIC-20: Hyper Expander Rev. 0

## Bill of Material Rev. 0.0

VIC20_HypExp_BOM_v0_0.xlsx

Drafted by Sven Petersen Page 1 of 1

23.11.2020 21:52
Doc.No.: 172-5-01-00.0

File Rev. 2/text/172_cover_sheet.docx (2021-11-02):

Project Documentation

Commodore VIC-20: Hyper Expander

Project number: 172

Revision: 2

Date: 14.07.2021


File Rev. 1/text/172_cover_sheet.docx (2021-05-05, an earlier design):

Project Documentation

Commodore VIC-20: Hyper Expander

Project number: 172

Revision: 1

Date: 05.05.2021


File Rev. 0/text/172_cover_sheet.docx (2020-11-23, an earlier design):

Project Documentation

Commodore VIC-20: Hyper Expander

Project number: 172

Revision: 0

Date: 02.11.2020


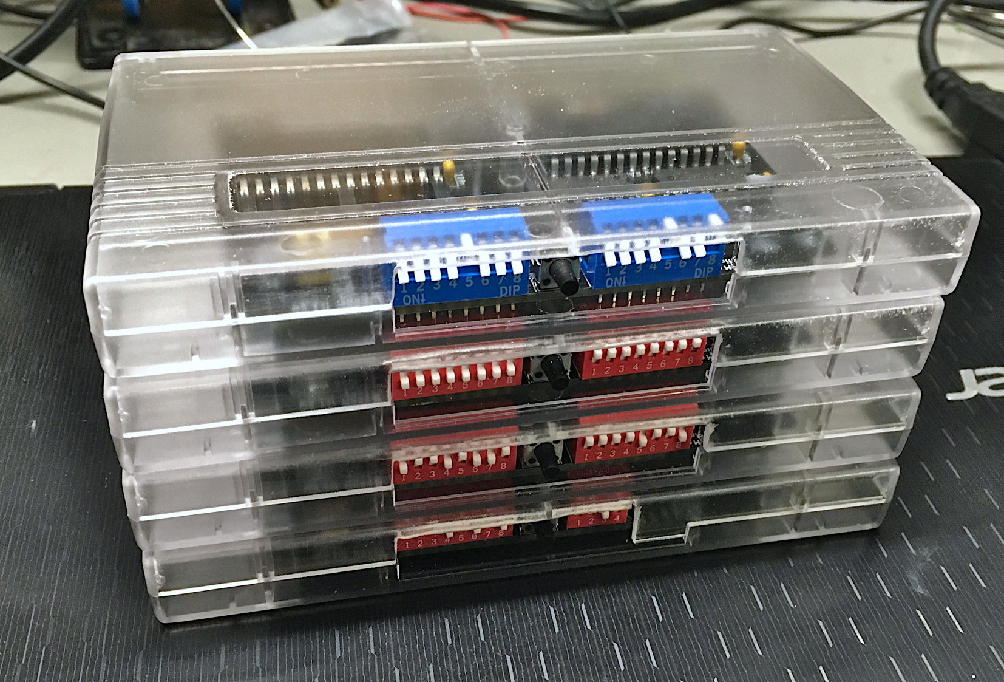
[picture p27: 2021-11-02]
Rev. 2/pictures/9750_4x_in case.JPG

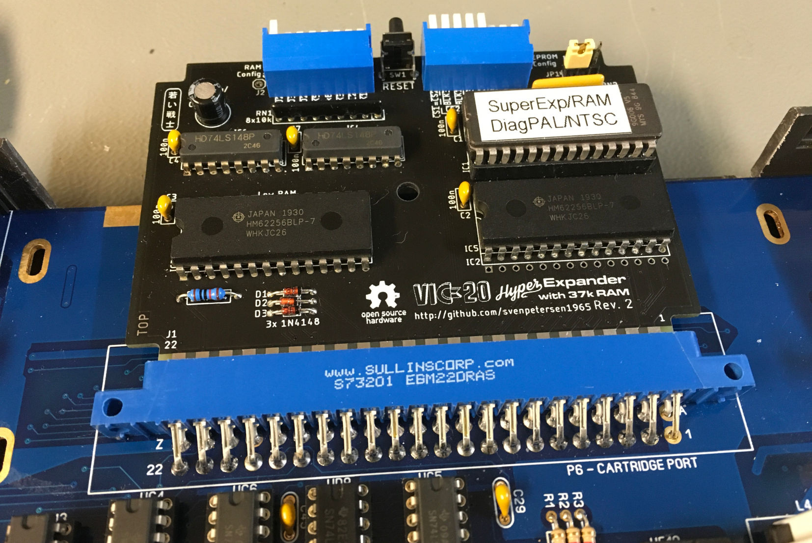
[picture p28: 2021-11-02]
Rev. 2/pictures/9292_-_Rev.2_in_slot.JPG

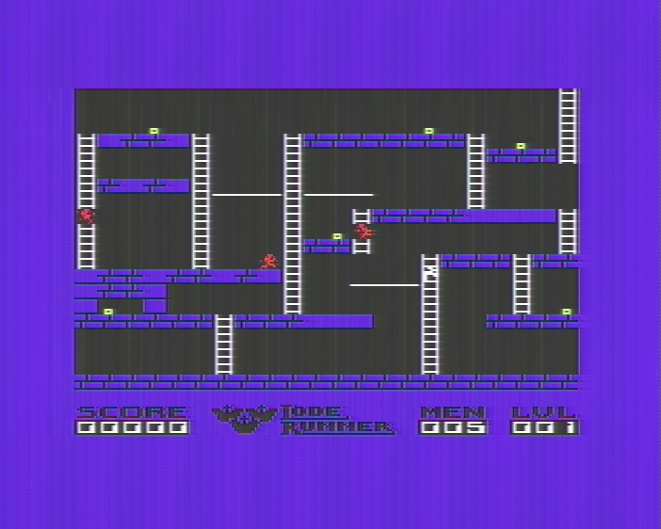
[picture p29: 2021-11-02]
Rev. 2/pictures/loderunner.png

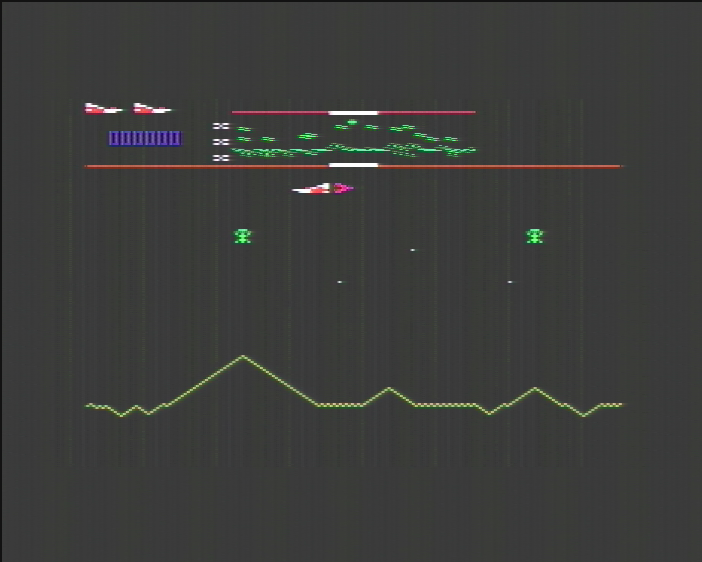
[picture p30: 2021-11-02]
Rev. 2/pictures/defender.png

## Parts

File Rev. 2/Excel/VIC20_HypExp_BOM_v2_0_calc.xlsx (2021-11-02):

Commodore VIC-20: Hyper Expander Rev. 2
Calculation Rev. 2.0
Pos. | Qty | Value | €/ea | € | Comment
1 | 1 | 172-2-01-01 | 1.00 € | 1.00 € | 2 layer, Cu 35µ, HASL, 102.0mm x 75.0mm, 1.6mm FR4
2 | 5 | 100n | 0.20 € | 1.00 € | Ceramic capacitor, pitch 2.5mm (25V or 50V)
3 | 1 | 100u/16V | 0.22 € | 0.22 € | Electrolytic cap, pitch 2.5mm, Ø 7mm
4 | 1 | 10k | 0.08 € | 0.08 € | Metal film resistor, 10% or better
5 | 3 | 1N4148 | 0.02 € | 0.06 € | Diode
6 | 2 | 74LS148 | 0.97 € | 1.94 € | TI or other
7 | 2 | DIP-SW8 | 0.80 € | 1.60 € | standard pin header (option, can be configured with solder bridge)
8 | 1 | 1X2 pin header (2.54mm pitch) | 0.14 € | 0.14 € | standard pin header (option, can be configured with solder bridge)
9 | 2 | HM62256 | 1.60 € | 3.20 € | Hitachi SRAM, 32k or compatible. E.G. AliExpress https://www.aliexpress.com/item/4001203718996.html?spm=a2g0s.9042311.0.0.22cb4c4dLFzppg
10 | 1 | JPT1236HB | 0.15 € | 0.15 € | Namae Electronics, e.g. Reichelt TASTER 3305B, tme.eu: TACTA-68N-F
11 | 1 | M27C512-DIP28 | 5.50 € | 5.50 € | EPROM: 27C64, 27C128, 27C256 possible. Refere to document 172-6-01-**
12 | 1 | M27C512-DIP28 | 0.00 € | 0.00 € | option, not required for super expander
13 | 3 | DIP28-Sockets | 0.42 € | 1.26 € | option, refer to IC1, IC2 and IC3
14 | 1 | Jumper 2.54mm) | 0.02 € | 0.02 €
 |  | Total |  | 16.17 €

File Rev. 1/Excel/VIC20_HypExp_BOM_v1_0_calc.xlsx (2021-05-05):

Commodore VIC-20: Hyper Expander Rev. 1
Calculation Rev. 1.0
Pos. | Qty | Value | €/ea | € | Comment
1 | 1 | 172-2-01-01 | 1.00 € | 1.00 € | 2 layer, Cu 35µ, HASL, 102.0mm x 75.0mm, 1.6mm FR4
2 | 5 | 100n | 0.20 € | 1.00 € | Ceramic capacitor, pitch 2.5mm (25V or 50V)
3 | 1 | 100u/16V | 0.22 € | 0.22 € | Electrolytic cap, pitch 2.5mm, Ø 7mm
4 | 1 | 10k | 0.08 € | 0.08 € | Metal film resistor, 10% or better
5 | 3 | 1N4148 | 0.02 € | 0.06 € | Diode
6 | 2 | 74LS148 | 0.97 € | 1.94 € | TI or other
7 | 2 | 1x3 pin header (2.54mm pitch) | 0.07 € | 0.14 € | standard pin header (option, can be configured with solder bridge)
8 | 1 | 3X2 pin header (2.54mm pitch) | 0.14 € | 0.14 € | standard pin header (option, can be configured with solder bridge)
9 | 2 | 4X2 pin header (2.54mm pitch) | 0.17 € | 0.34 € | standard pin header (option, can be configured with solder bridge)
10 | 2 | HM62256 | 1.60 € | 3.20 € | Hitachi SRAM, 32k or compatible. E.G. AliExpress https://www.aliexpress.com/item/4001203718996.html?spm=a2g0s.9042311.0.0.22cb4c4dLFzppg
11 | 1 | JPT1236HB | 0.15 € | 0.15 € | Namae Electronics, e.g. Reichelt TASTER 3305B, tme.eu: TACTA-68N-F
12 | 1 | M27C512-DIP28 | 5.50 € | 5.50 € | EPROM: 27C64, 27C128, 27C256 possible. Refere to document 172-6-01-**
13 | 1 | M27C512-DIP28 | 0.00 € | 0.00 € | option, not required for super expander
14 | 3 | DIP28-Sockets | 0.42 € | 1.26 € | option, refer to IC1, IC2 and IC3
15 | 10 | Jumper 2.54mm) | 0.02 € | 0.20 €
 |  | Total |  | 15.23 €

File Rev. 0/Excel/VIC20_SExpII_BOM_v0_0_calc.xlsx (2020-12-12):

Commodore VIC-20: Super Expander II Rev. 0
Bill of Material Rev. 0.0
Pos. | Qty | Value | €/ea | € | Comment
1 | 1 | 157-2-01-00 | 1.00 € | 1.00 € | 2 layer, Cu 35µ, HASL, 102.0mm x 75.0mm, 1.6mm FR4
 | 8 | 100n | 0.20 € | 1.60 € | Ceramic capacitor, pitch 2.5mm (25V or 50V)
 | 1 | 100u/16V | 0.22 € | 0.22 € | Electrolytic cap, pitch 2.5mm
 | 3 | 10k | 0.08 € | 0.24 € | Metal fil resistor
 | 6 | 2114 | 1.66 € | 9.96 € | 1k x 4 Static RAM. Type 2114. AliExpress search term "uPD2114". Or some retro computer stores like restore-store.de
 | 6 | DIP18-Sockets | 0.32 € | 1.92 € | optional
 | 2 | 1x3 pin header (2.54mm pitch) | 0.07 € | 0.14 € | standard pin header (option, can be configured with solder bridge)
 | 1 | 3X2 pin header (2.54mm pitch) | 0.14 € | 0.14 € | standard pin header (option, can be configured with solder bridge)
 | 5 | jumper 2.54mm | 0.02 € | 0.10 € | standard jumper. Refer to JP1-3
 | 1 | JTP-1130 | 0.15 € | 0.15 € | 6 x 6 mm tact switch (standard)
 | 1 | M27C512-DIP28 | 5.50 € | 5.50 € | EPROM: 27C64, 27C128, 27C256 possible. Refere to document 157-6-02-**
 | 1 | M27C512-DIP28 | 0.00 € | 0.00 € | option, not required for super expander
 | 1 | DIP28-Sockets | 0.42 € | 0.42 € | option, refer to IC1 and IC2
 |  | Total |  | 21.39 €

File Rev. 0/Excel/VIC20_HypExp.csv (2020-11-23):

Qty | Value | Device | Package | Parts | Description
4 | 100n | CAP01 | C-2,5 | C1, C2, C3, C4
1 | 100u/16V | C07/2,5 | C07/2,5 | C5
8 | 10k | RES04 | R-10 | R1, R2, R3, R4, R5, R6, R7, R8
3 | 1N4148 | 1N41480.3";DO-35/3" | D1, D2, D3
1 | 74LS148 | 74148DIL | DIL-16 | IC4
3 | COMBI-3P | COMBI-3P | COMBI-3P | JP1, JP2, JP4
1 | COMBI-3X2P | COMBI-3X2P | COMBI-3X2 | JP3
1 | COMBI-4X2P | COMBI-4X2P | COMBI-4X2 | JP5
1 | HM62256 | HM62256 | DIL28-6 | IC3
1 | JPT1236HB | JPT1236HB | JTP_1236HB | SW1
2 | M27C512-DIP28 | M27C512-DIP28 | DIL28-6 | IC1, IC2
1 | OPEN_SOURCE_HW | OPEN_SOURCE_HW | OPENHW | U$2
1 | VIC20_EXPANSIONPORT | VIC20_EXPANSIONPORT | VIC20_EXPANSION | J1

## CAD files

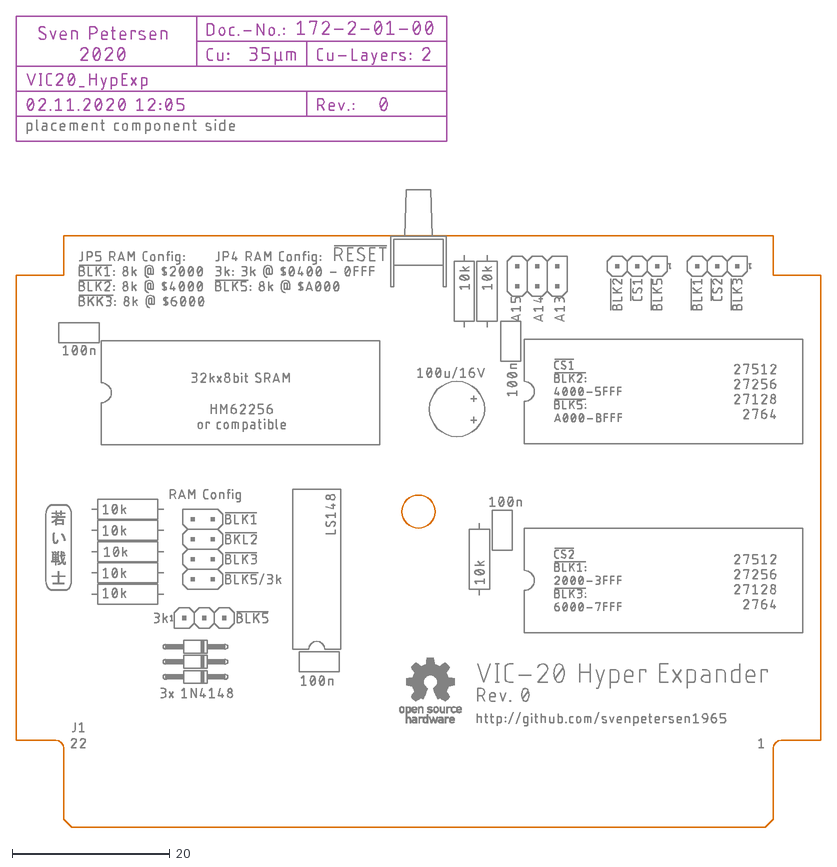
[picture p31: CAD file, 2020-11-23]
Rev. 0/dxf/VIC20_HypExp.dxf
102.0 x 102.9

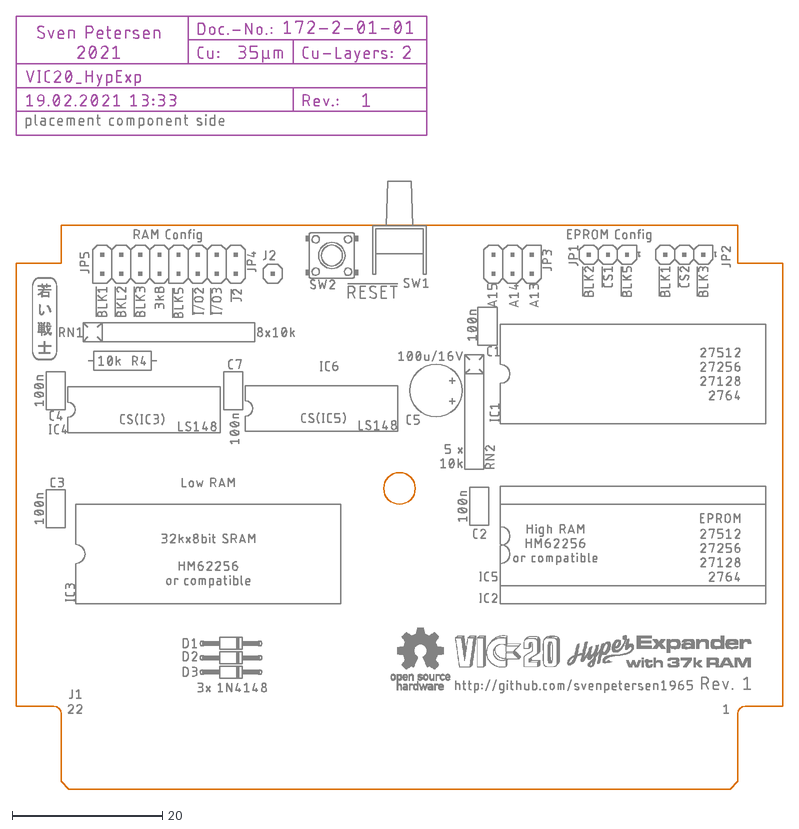
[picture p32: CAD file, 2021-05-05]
Rev. 1/dxf/VIC20_HypExp.dxf
102.0 x 102.9

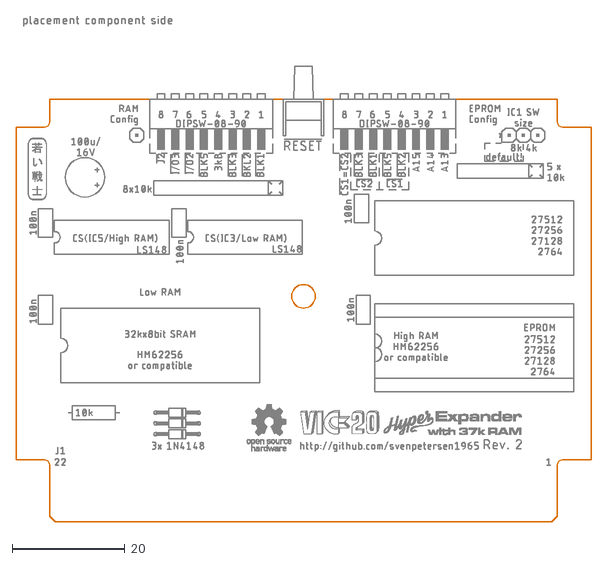
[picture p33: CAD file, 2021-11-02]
Rev. 2/dxf/VIC20_HypExp.dxf
102.0 x 89.7

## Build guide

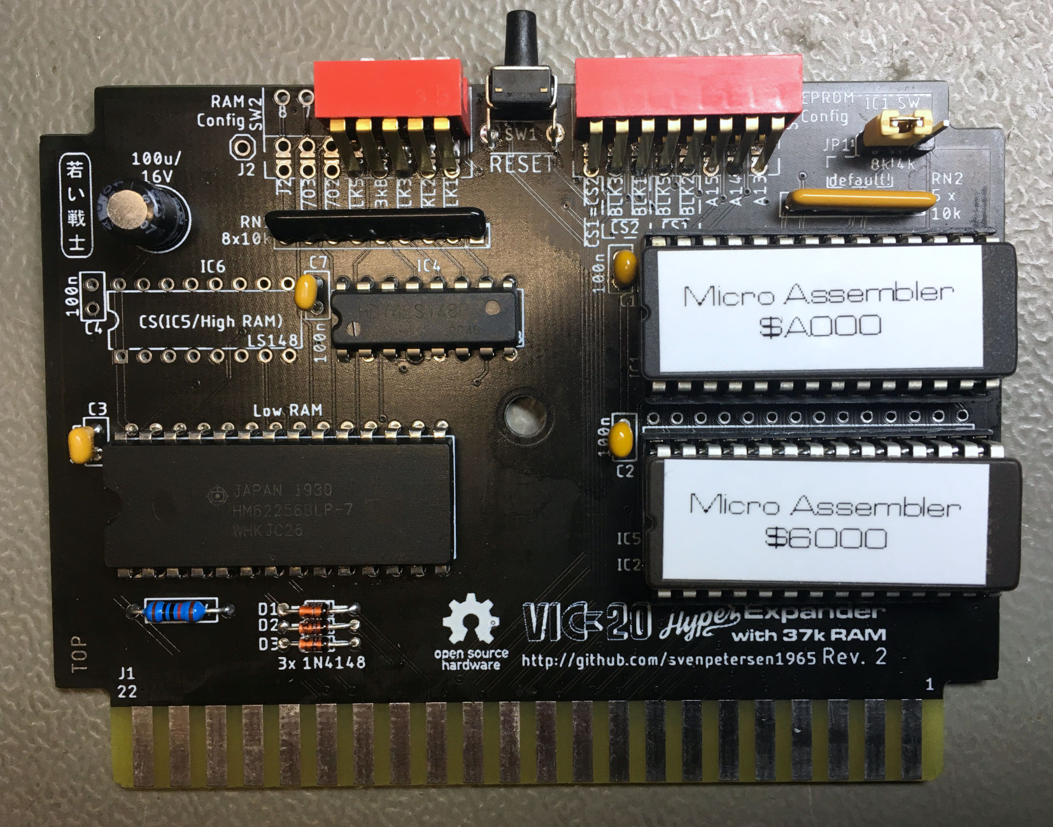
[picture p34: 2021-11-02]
Rev. 2/pictures/9394_-_Hyper_Expander_v2_MicroAssembler.JPG

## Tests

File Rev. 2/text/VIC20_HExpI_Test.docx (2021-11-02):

Commodore VIC-20: Hyper Expander Rev. 2

Testing

# Test Setup

The tests were conducted with a VickyTwenty (a reproduction of the VIC-20 ASSY 250403) and two Hyper Expander cartridges Rev. 2. One was a RAM and 1 EPROM configuration with two HN61256BLP-7 RAM and up to two 27C512 EPROMs, the other was a 16k EPROM cartridge with two HN61256BLP-7 RAM.

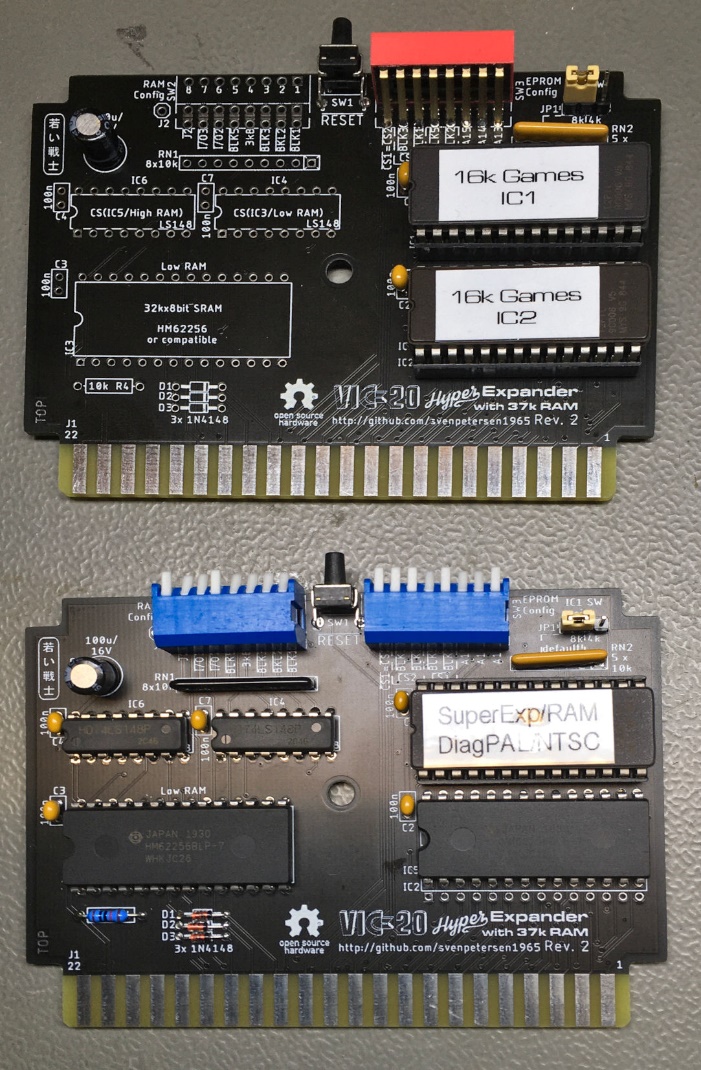
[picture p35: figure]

Figure 1: Prototypes of Hyper Expander Rev. 2: 16kB EPROM (top), Full RAM and 8k EPROM (bottom)

# Test Execution

## Super Expander Software

First, the original Super Expander Software from zimmers.net and the VIC-MON for $B000 were programed to an EPROM. These two programs fit into one 8k memory bank, since the Super Expander software is a 4k software. The EPROM was inserted the in IC1 socket and was set to ($A000-$BFFF). The RAM was configured to 3k RAM expansion only (SW2: all off, except switch 4 on ).

SW3-8 CS1=CS2 | SW3-7 BLK3 | SW3-6 BLK1 | SW3-5 BLK5 | SW3-4 BLK2 | SW3-3 A15 | SW3-2 A14 | SW3-1 A13
off | off | off | on | off | on | on | on

The cartridge was inserted into the VIC-20 and the computer was switched on. It booted normally and 6519 Bytes Free were reported. The Super Expander requires bytes in RAM, so this is correct.

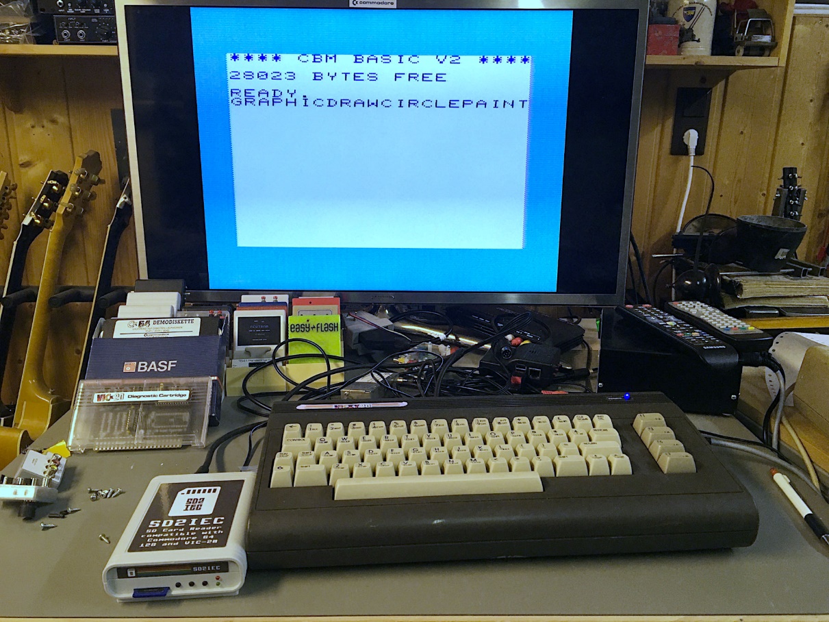
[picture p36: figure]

Figure 2: Test with Super Expander Firmware and full RAM expansion

The function keys produce some of the additional Super Expander instructions. A short program, which is using those instructions, was executed successfully.

- Function of RAM and EPROM IC1 with and the Super Expander Software verified.

SYS11*4096 (which is $B000) started the VIC-MON.

- Additional test.

The Super Expander Software was tested with all other RAM configurations, the VIC-20 always booted properly.

## RESET Button

The RESET button (SW1) was pressed. The VIC-20 rebooted properly.

- RESET button verified

## VIC-20 Diagnostic Software

The software (PAL) also origins from zimmers.net. It was programmed into the 2nd 8k bank of the said EPROM, a different version of this software (NTSC) was programmed to the 3rd 8k bank.

The EPROM banks were set to the 2nd 8k SW3 switch 5 remained on ().

SW3-8 CS1=CS2 | SW3-7 BLK3 | SW3-6 BLK1 | SW3-5 BLK5 | SW3-4 BLK2 | SW3-3 A15 | SW3-2 A14 | SW3-1 A13
off | off | off | on | off | on | on | off

The RAM was configured to 3k Expansion only.

The diagnostics software started and executed properly (together with the VIC-20 diagnostics harness). For the 2nd version of the diagnostic software, SW3 was set to the 3rd 8k bank

SW3-8 CS1=CS2 | SW3-7 BLK3 | SW3-6 BLK1 | SW3-5 BLK5 | SW3-4 BLK2 | SW3-3 A15 | SW3-2 A14 | SW3-1 A13
off | off | off | on | off | on | off | on

This software executed properly, too.

- Bank select (000, 001, 010) on SW3 verified

## Game Cartridge Donkey Kong

This game is a 16k game and requires both EPROMs.
The software for $A000 was programmed in a fresh EPROM, which was inserted into IC1. SW3 remained at . The other part of the software, which is located at $2000 was programmed into another fresh EPROM, which was then inserted into the IC2 socket.

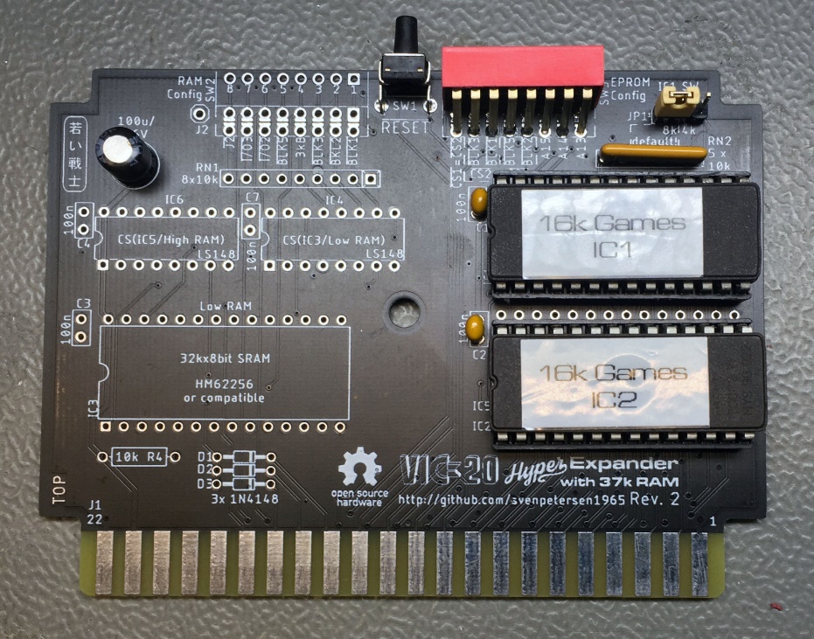
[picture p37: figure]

Figure 3: Configuration withn two EPROMs

SW3 was set to (SW3-1..8: on, on, on,off, on, on, off, off).

SW3-8 CS1=CS2 | SW3-7 BLK3 | SW3-6 BLK1 | SW3-5 BLK5 | SW3-4 BLK2 | SW3-3 A15 | SW3-2 A14 | SW3-1 A13
off | off | on | on | off | on | on | on

The software started properly and the game could be played.

- EPROM IC2 with verified

## Game Cartridge AE

The software origins from zimmers.net. It consisted of two images, one for $A000 and one for $6000. The images were programmed into two EPROMs, the $A000 software was inserted into IC1, the $6000 software into IC2 (chip select ).

SW3-8 CS1=CS2 | SW3-7 BLK3 | SW3-6 BLK1 | SW3-5 BLK5 | SW3-4 BLK2 | SW3-3 A15 | SW3-2 A14 | SW3-1 A13
off | on | off | on | off | off | on | on

The software started properly and the game could be played.

- EPROM IC2 with verified

## VIC-MON (for $4000)

The source of this software is once again zimmers.net. It was programmed into the 5th 8k memory bank (@ buffer address $8000) of an EPROM. The EPROM was inserted into IC1 and SW3 was set to .

SW3-8 CS1=CS2 | SW3-7 BLK3 | SW3-6 BLK1 | SW3-5 BLK5 | SW3-4 BLK2 | SW3-3 A15 | SW3-2 A14 | SW3-1 A13
off | off | off | off | on | off | on | on

SYS4*1024 started the software properly.

- Bank select (100) on JP3 and (JP1) verified

## RAM Test

The RAM configuration was tested with the RAM Expansion Test Software Rev. 1.0 (https://github.com/svenpetersen1965/VIC-20-RAM-Expansion-Test-Software)

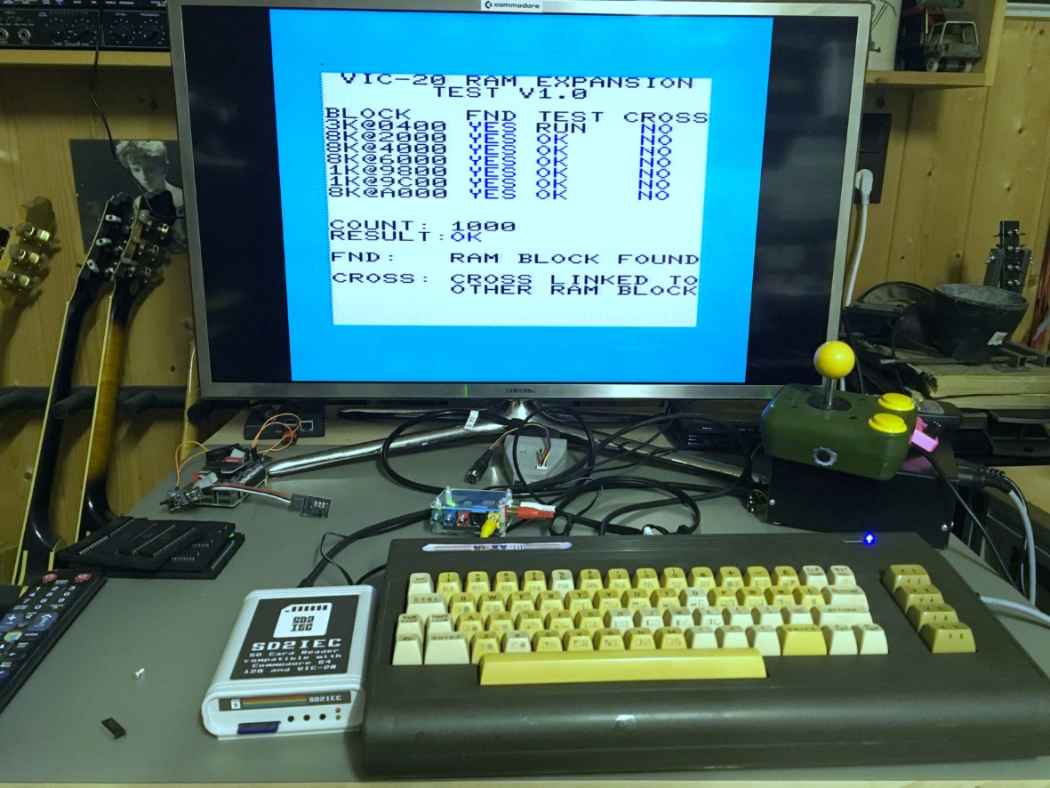
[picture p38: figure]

Figure 4: RAM Expansion Test running from EPROM

The version v1.0 of the RAM Test Software is capable of testing the RAM blocks attached to and . This software tests every bit in a RAM block for LOW and for HIGH. Also address line conflicts and a cross talk to other RAM blocks are detected.

EPROM configuration:

SW3-8 CS1=CS2 | SW3-7 BLK3 | SW3-6 BLK1 | SW3-5 BLK5 | SW3-4 BLK2 | SW3-3 A15 | SW3-2 A14 | SW3-1 A13
off | off | off | on | off | on | off | on

RAM configuration

SW2-8 | SW2-7 | SW2-6 | SW2-5 | SW2-4 | SW2-3 | SW2-2 | SW2-1
off | on | on | off | on | on | on | on

In the first pass, the RAM Test was running from the on-board EPROM IC1, configured to $A000 with BLK5). The test was running several thousand times without reporting any problems.

To test the 7th RAM bank configured at $A000, the EPROM was removed and the RAM @$A000 was activated. This test configuration did not report any problems, either.

SW2-8 | SW2-7 | SW2-6 | SW2-5 | SW2-4 | SW2-3 | SW2-2 | SW2-1
off | on | on | on | on | on | on | on

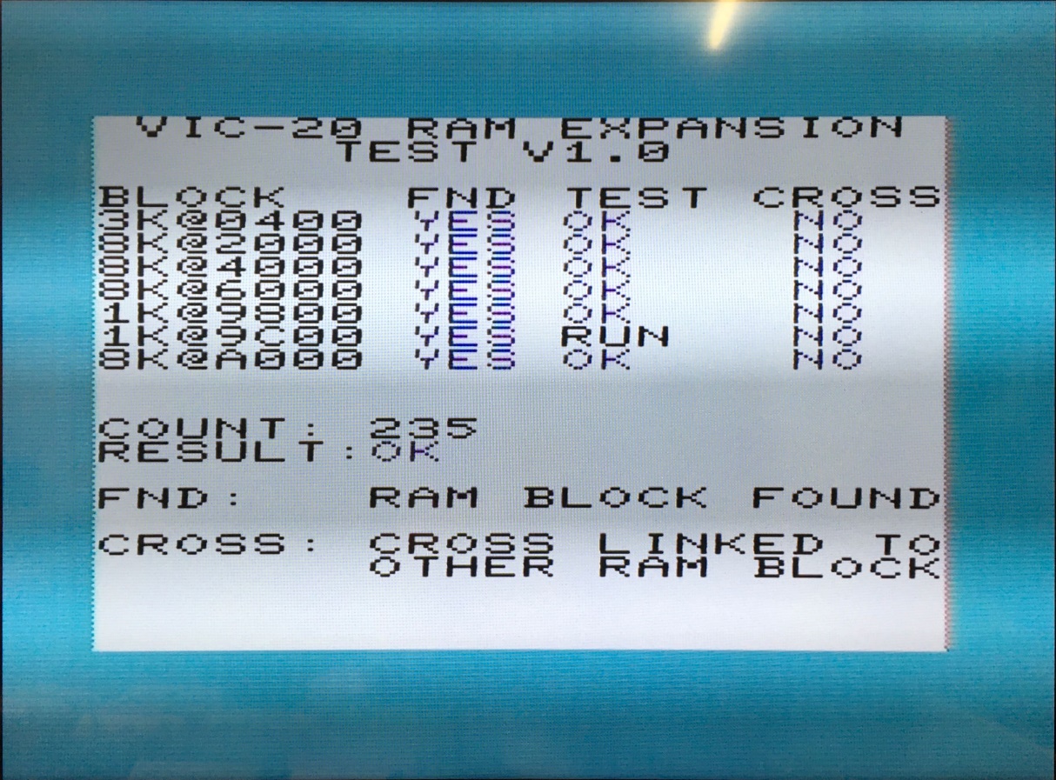
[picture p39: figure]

Figure 5: RAM Expansion Test running from a disk image

The game DOOM for VIC-20 requires 35k of RAM. It was played with all RAM activated and the EPROM deactivated.

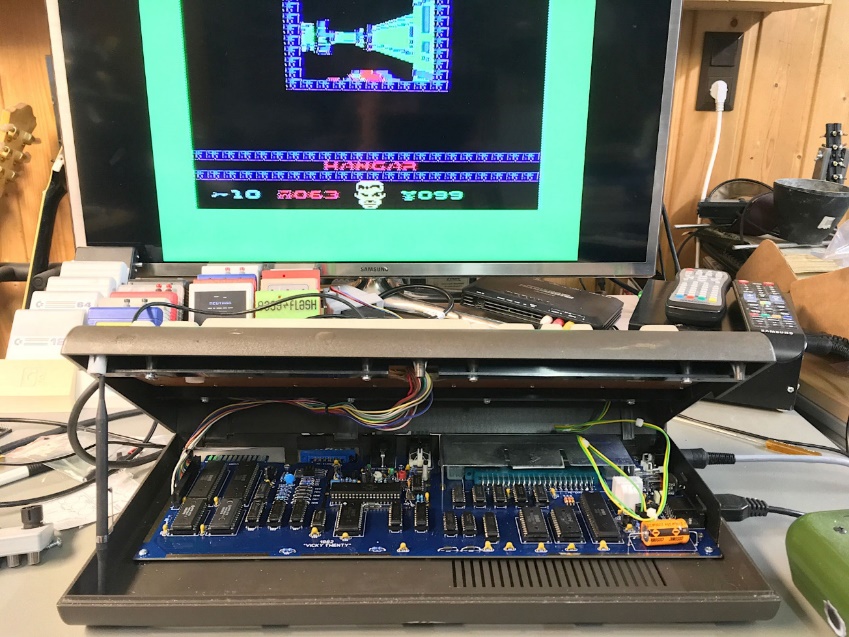
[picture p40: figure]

Figure 6: DOOM running on the VIC-20 with the Hyper Expander configured to maximum RAM

- RAM function verified

## Installation in cartridge cases

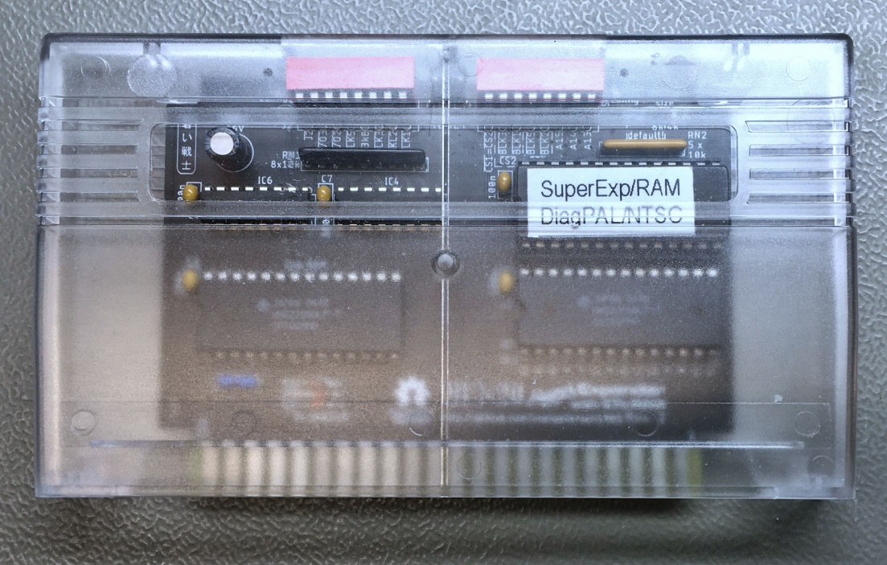
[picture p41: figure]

Figure 7: Installation in a tfw8bit case

The tfw8bit.com VIC-20 cartridge case fits after removing the support structures for the short PCBs.

In case the RESET switch is desired, the cases require a modification (5mm hole in the back)

- Dimensions verified

# Conclusion

The Hyper Expander Rev. 2 is fully functional

VIC20_HExpI_Test.docx 02.11.2021 16:51 Drafted by Sven Petersen Page 2 of 2 Doc.-No.: 171-6-03-02

VIC20_HExpI_Test.docx 02.11.2021 16:51 Drafted by Sven Petersen Page 1 of 1 Doc.-No.: 000-6-00-00

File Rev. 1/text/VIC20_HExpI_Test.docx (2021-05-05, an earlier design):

Commodore VIC-20: Hyper Expander Rev. 1

Testing

# Test Setup

The tests were conducted with a VickyTwenty (a reproduction of the VIC-20 ASSY 250403) and a Hyper Expander cartridge (Rev. 1) with two HN61256BLP-7 RAM and up to two 27C512 EPROMs.

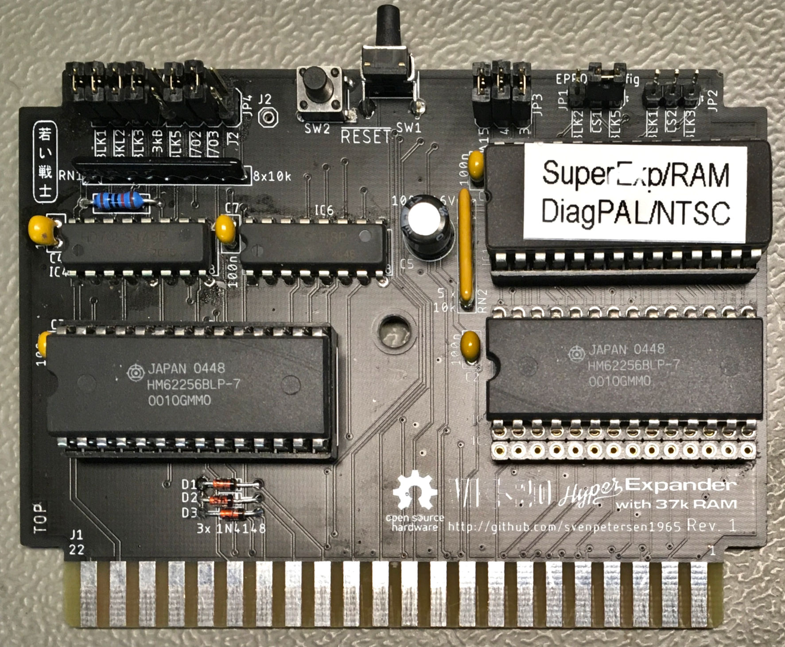
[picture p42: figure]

Figure 1: Prototype of Hyper Expander Rev. 1

# Test Execution

## Super Expander Software

First, the original Super Expander Software from zimmers.net and the VIC-MON for $B000 were programed to an EPROM. These two programs fit into one 8k memory bank, since the Super Expander software is a 4k software. The EPROM was inserted the in IC1 socket and (JP1) was set to ($A000-$BFFF). The RAM was configured to 3k RAM expansion only (JP4=3k, J5: 7-8 only = BLK5/3k).

The cartridge was inserted into the VIC-20 and the computer was switched on. It booted normally and 6519 Bytes Free were reported. The Super Expander requires bytes in RAM, so this is correct.


Figure 2: Test with Super Expander Firmware and full RAM expansion

The function keys produce some of the additional Super Expander instructions. A short program, which is using those instructions, was executed successfully.

- Function of RAM and EPROM IC1 with and the Super Expander Software verified.

SYS11*4096 (which is $B000) started the VIC-MON.

- Additional test.

The Super Expander Software was tested with all other RAM configurations, the VIC-20 always booted properly.

## RESET Button

The RESET button (SW1) was pressed. The VIC-20 rebooted properly. The same applies to SW2.

- RESET button verified

## VIC-20 Diagnostic Software

The software (PAL) also origins from zimmers.net. It was programmed into the 2nd 8k of the said EPROM, a different version of this software (NTSC) was programmed to the 3rd 8k.

The jumpers on JP3 were set to the 2nd 8k (A15...A13: set open), JP1 remained at .

The RAM was configured to 3k Expansion only.

The diagnostics software started and executed properly (together with the VIC-20 diagnostics harness). For the 2nd version of the diagnostic software, JP3 was set to the 3rd 8k bank (A15...A13: set open set). This software executed properly, too.

- Bank select (000, 001, 010) on JP3 verified

## Game Cartridge Donkey Kong

This game is a 16k game and requires both EPROMs.
The software for $A000 was programmed in a fresh EPROM, which was inserted into IC1. JP1 remained at . The other part of the software, which is located at $2000 was programmed into another fresh EPROM, which was then inserted into the IC2 socket.

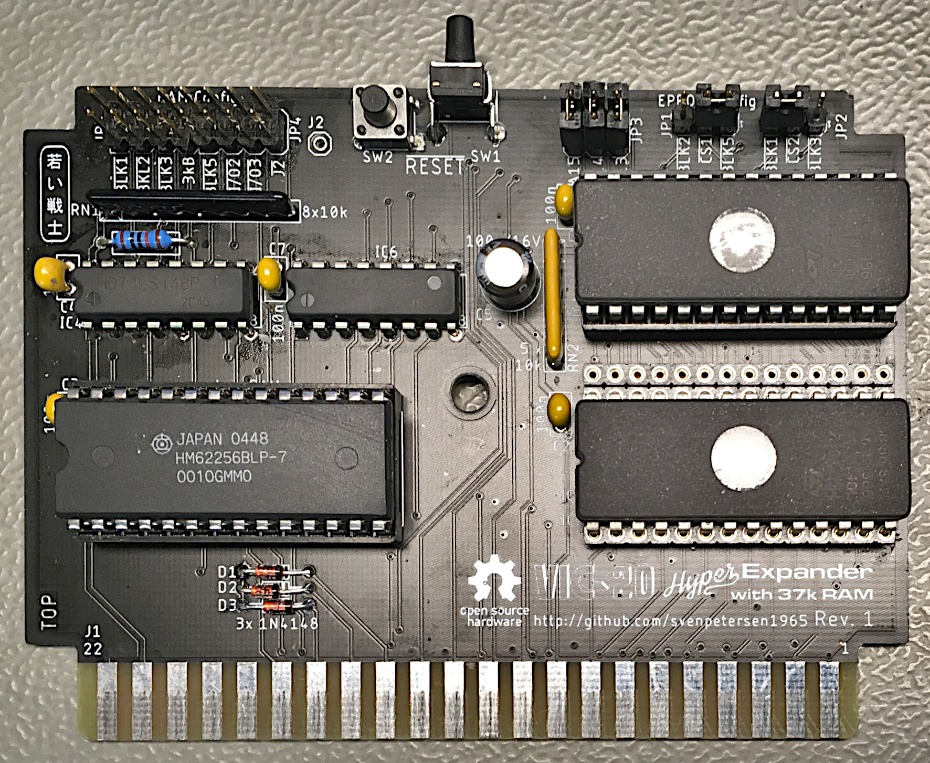
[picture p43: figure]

Figure 3: Configuration withn two EPROMs

JP2 was set to . All jumpers on JP3 were set. The software started properly and the game could be played.

- EPROM IC2 with verified

## Game Cartridge AE

The software origins from zimmers.net. It consisted of two images, one for $A000 and one for $6000. The images were programmed into two EPROMs, the $A000 software was inserted into IC1, the $6000 software into IC2. Jumper JP1 was set to , JP2 to . The software started properly and the game could be played.

- EPROM IC2 with verified

## VIC-MON (for $4000)

The source of this software is once again zimmers.net. It was programmed into the 5th 8k memory bank (@ buffer address $8000) of an EPROM. The EPROM was inserted into IC1 and JP1 was set to .

SYS4x1022 started the software properly.

- Bank select (100) on JP3 and (JP1) verified

## RAM Test

The RAM configuration was tested with the RAM Expansion Test Software Rev. 1.0 (https://github.com/svenpetersen1965/VIC-20-RAM-Expansion-Test-Software)

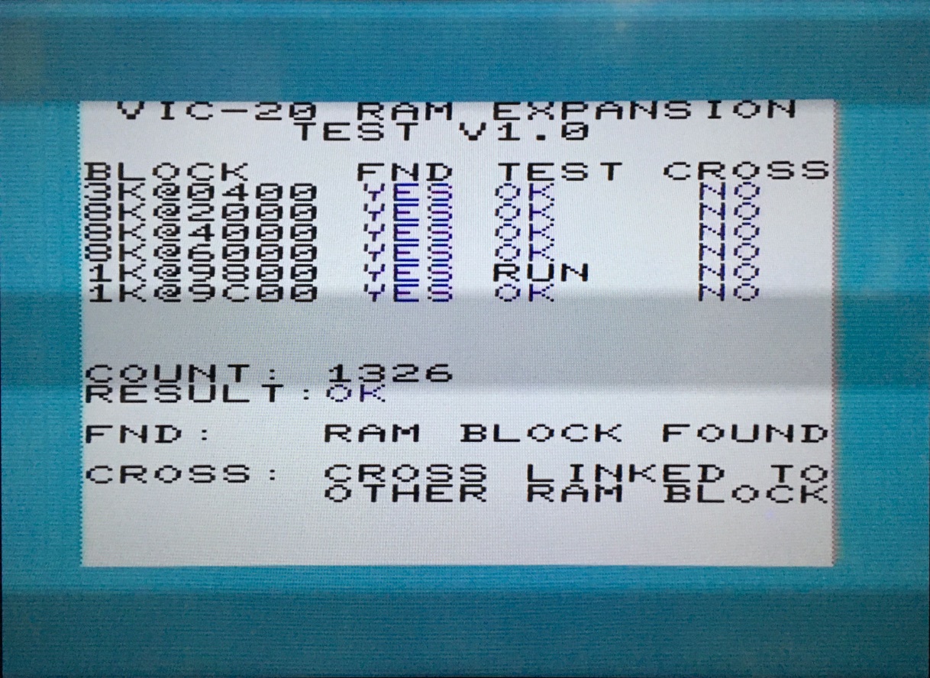
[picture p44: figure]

Figure 4: RAM Expansion Test running from EPROM

The version v1.0 of the RAM Test Software is capable of testing the RAM blocks attached to and . This software tests every bit in a RAM block for LOW and for HIGH. Also address line conflicts and a cross talk to other RAM blocks are detected.

In the first pass, the RAM Test was running from the on-board EPROM IC1, configured to $A000 with BLK5). The test was running several thousand times without reporting any problems.

To test the 7th RAM bank configured at $A000, the EPROM was removed and the JP4 was set to BLK5. This test configuration did not report any problems, either.


Figure 5: RAM Expansion Test running from a disk image

The game DOOM for VIC-20 requires 35k of RAM. It was played with all RAM activated and the EPROM deactivated.


Figure 6: DOOM running on the VIC-20 with the Hyper Expander configured to maximum RAM

- RAM function verified

## Installation in cartridge cases

The fully assembled Hyper Expander PCB (all ICs on sockets and all vertical jumpers) was installed in the original Commodore Super Expander cartridge case. This could be accomplished without a problem.


Figure 7: Installation in a tfw8bit case

The original Commodore Game cartridge case required removing some support structures for small PCBs, after that, it also fit.

The tfw8bit.com VIC-20 cartridge case fits after removing the support structures for the short PCBs.

In case the RESET switch is desired, the cases require a modification (5mm hole in the back)

- Dimensions verified

# Conclusion

The Hyper Expander Rev. 1 is fully functional

VIC20_HExpI_Test.docx 05.05.2021 21:03 Drafted by Sven Petersen Page 2 of 2 Doc.-No.: 171-6-03-01

VIC20_HExpI_Test.docx 05.05.2021 21:03 Drafted by Sven Petersen Page 1 of 1 Doc.-No.: 000-6-00-00

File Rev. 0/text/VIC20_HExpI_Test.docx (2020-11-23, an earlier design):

Commodore VIC-20: Hyper Expander Rev. 0

Testing

# Test Setup

The tests were conducted with a VIC-20 (ASSY 250403 Rev. D) and a Hyper Expander cartridge (Rev. 0) with a HN61256BLP-7 RAM and up to two 27C512 EPROMs.

# Test Execution

## Super Expander Software

First, the original Super Expander Software from zimmers.net and the VIC-MON for $B000 were programed to an EPROM. These two programs fit into one 8k memory bank, since the Super Expander software is a 4k software. The EPROM was inserted the in IC1 socket and (JP1) was set to ($A000-$BFFF). The RAM was configured to 3k RAM expansion only (JP4=3k, J5: 7-8 only = BLK5/3k).

The cartridge was inserted into the VIC-20 and the computer was switched on. It booted normally and 6519 Bytes Free were reported. The Super Expander requires bytes in RAM, so this is correct.


Figure 1: Test with Super Expander Firmware and full RAM expansion

The function keys produce some of the additional Super Expander instructions. A short program, which is using those instructions, was executed successfully.

- Function of RAM and EPROM IC1 with and the Super Expander Software verified.

SYS11*4096 (which is $B000) started the VIC-MON.

- Additional test.

The Super Expander Software was tested with all other RAM configurations, the VIC-20 always booted properly.

## RESET Button

The RESET button (SW1) was pressed. The VIC-20 rebooted properly.

- RESET button verified

## VIC-20 Diagnostic Software

The software (PAL) also origins from zimmers.net. It was programmed into the 2nd 8k of the said EPROM, a different version of this software (NTSC) was programmed to the 3rd 8k.

The jumpers on JP3 were set to the 2nd 8k (A15...A13: set open), JP1 remained at .

The RAM was configured to 3k Expansion only.

The diagnostics software started and executed properly (together with the VIC-20 diagnostics harness). For the 2nd version of the diagnostic software, JP3 was set to the 3rd 8k bank (A15...A13: set open set). This software executed properly, too.

- Bank select (000, 001, 010) on JP3 verified

## Game Cartridge Donkey Kong

This game is a 16k game and requires both EPROMs.
The software for $A000 was programmed in a fresh EPROM, which was inserted into IC1. JP1 remained at . The other part of the software, which is located at $2000 was programmed into another fresh EPROM, which was then inserted into the IC2 socket. JP2 was set to . All jumpers on JP3 were set.

The software started properly and the game could be played.

- EPROM IC2 with verified

## Game Cartridge AE

The software origins from zimmers.net. It consisted of two images, one for $A000 and one for $6000. The images were programmed into two EPROMs, the $A000 software was inserted into IC1, the $6000 software into IC2. Jumper JP1 was set to , JP2 to . The software started properly and the game could be played.

- EPROM IC2 with verified

## VIC-MON (for $4000)

The source of this software is once again zimmers.net. It was programmed into the 5th 8k memory bank (@ buffer address $8000) of an EPROM. The EPROM was inserted into IC1 and JP1 was set to .

SYS4x1022 started the software properly.

- Bank select (100) on JP3 and (JP1) verified

## RAM Test

The RAM configuration was tested with the RAM Expansion Test Software Rev. 0.0 (https://github.com/svenpetersen1965/VIC-20-RAM-Expansion-Test-Software)

This software tests every bit in a RAM block for LOW and for HIGH. Also address line conflicts and a cross talk to other RAM blocks are detected.

In the first pass, the RAM Test was running from the on-board EPROM IC1, configured to $A000 with BLK5). The 4th RAM block was configured to be the 3kByte RAM expansion.

The test was running several thousand times without reporting any problems.


Figure 2: RAM Expansion Test running from EPROM

To test the 4th RAM bank configured at $A000, the EPROM was removed and the JP4 was set to BLK5.

This test configuration did not report any problems, either.


Figure 3: RAM Expansion Test running from a disk image

- RAM function verified

## Installation in cartridge cases

The fully assembled Hyper Expander PCB (all ICs on sockets and all vertical jumpers) was installed in the original Commodore Super Expander cartridge case. This could be accomplished without a problem.


Figure 4: Installation in a tfw8bit case

The original Commodore Game cartridge case required removing some support structures for small PCBs, after that, it also fit.

The tfw8bit.com VIC-20 cartridge case fits after removing the support structures for the short PCBs.

In case the RESET switch is desired, the cases require a modification (5mm hole in the back)

- Dimensions verified

# Conclusion

The Hyper Expander Rev. 0 is fully functional

VIC20_HExpI_Test.docx 23.11.2020 20:31 Drafted by Sven Petersen Page 2 of 2 Doc.-No.: 171-6-03-00

VIC20_HExpI_Test.docx 23.11.2020 20:31 Drafted by Sven Petersen Page 1 of 1 Doc.-No.: 000-6-00-00

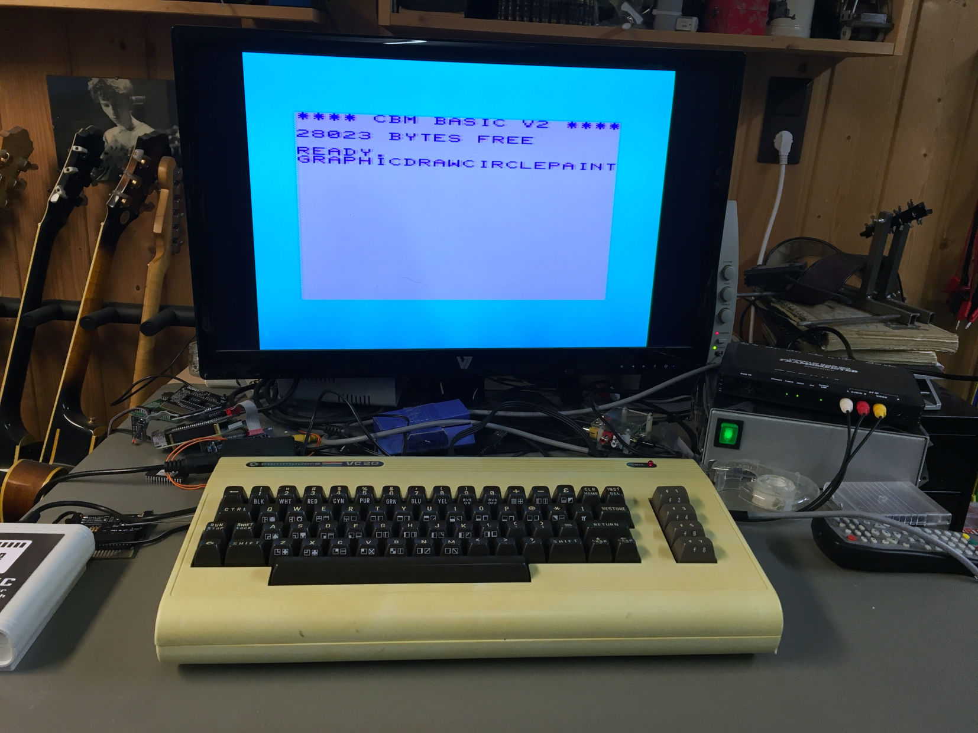
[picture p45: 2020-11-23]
Rev. 0/pictures/6765_Super_Expander_Software_Test.JPG

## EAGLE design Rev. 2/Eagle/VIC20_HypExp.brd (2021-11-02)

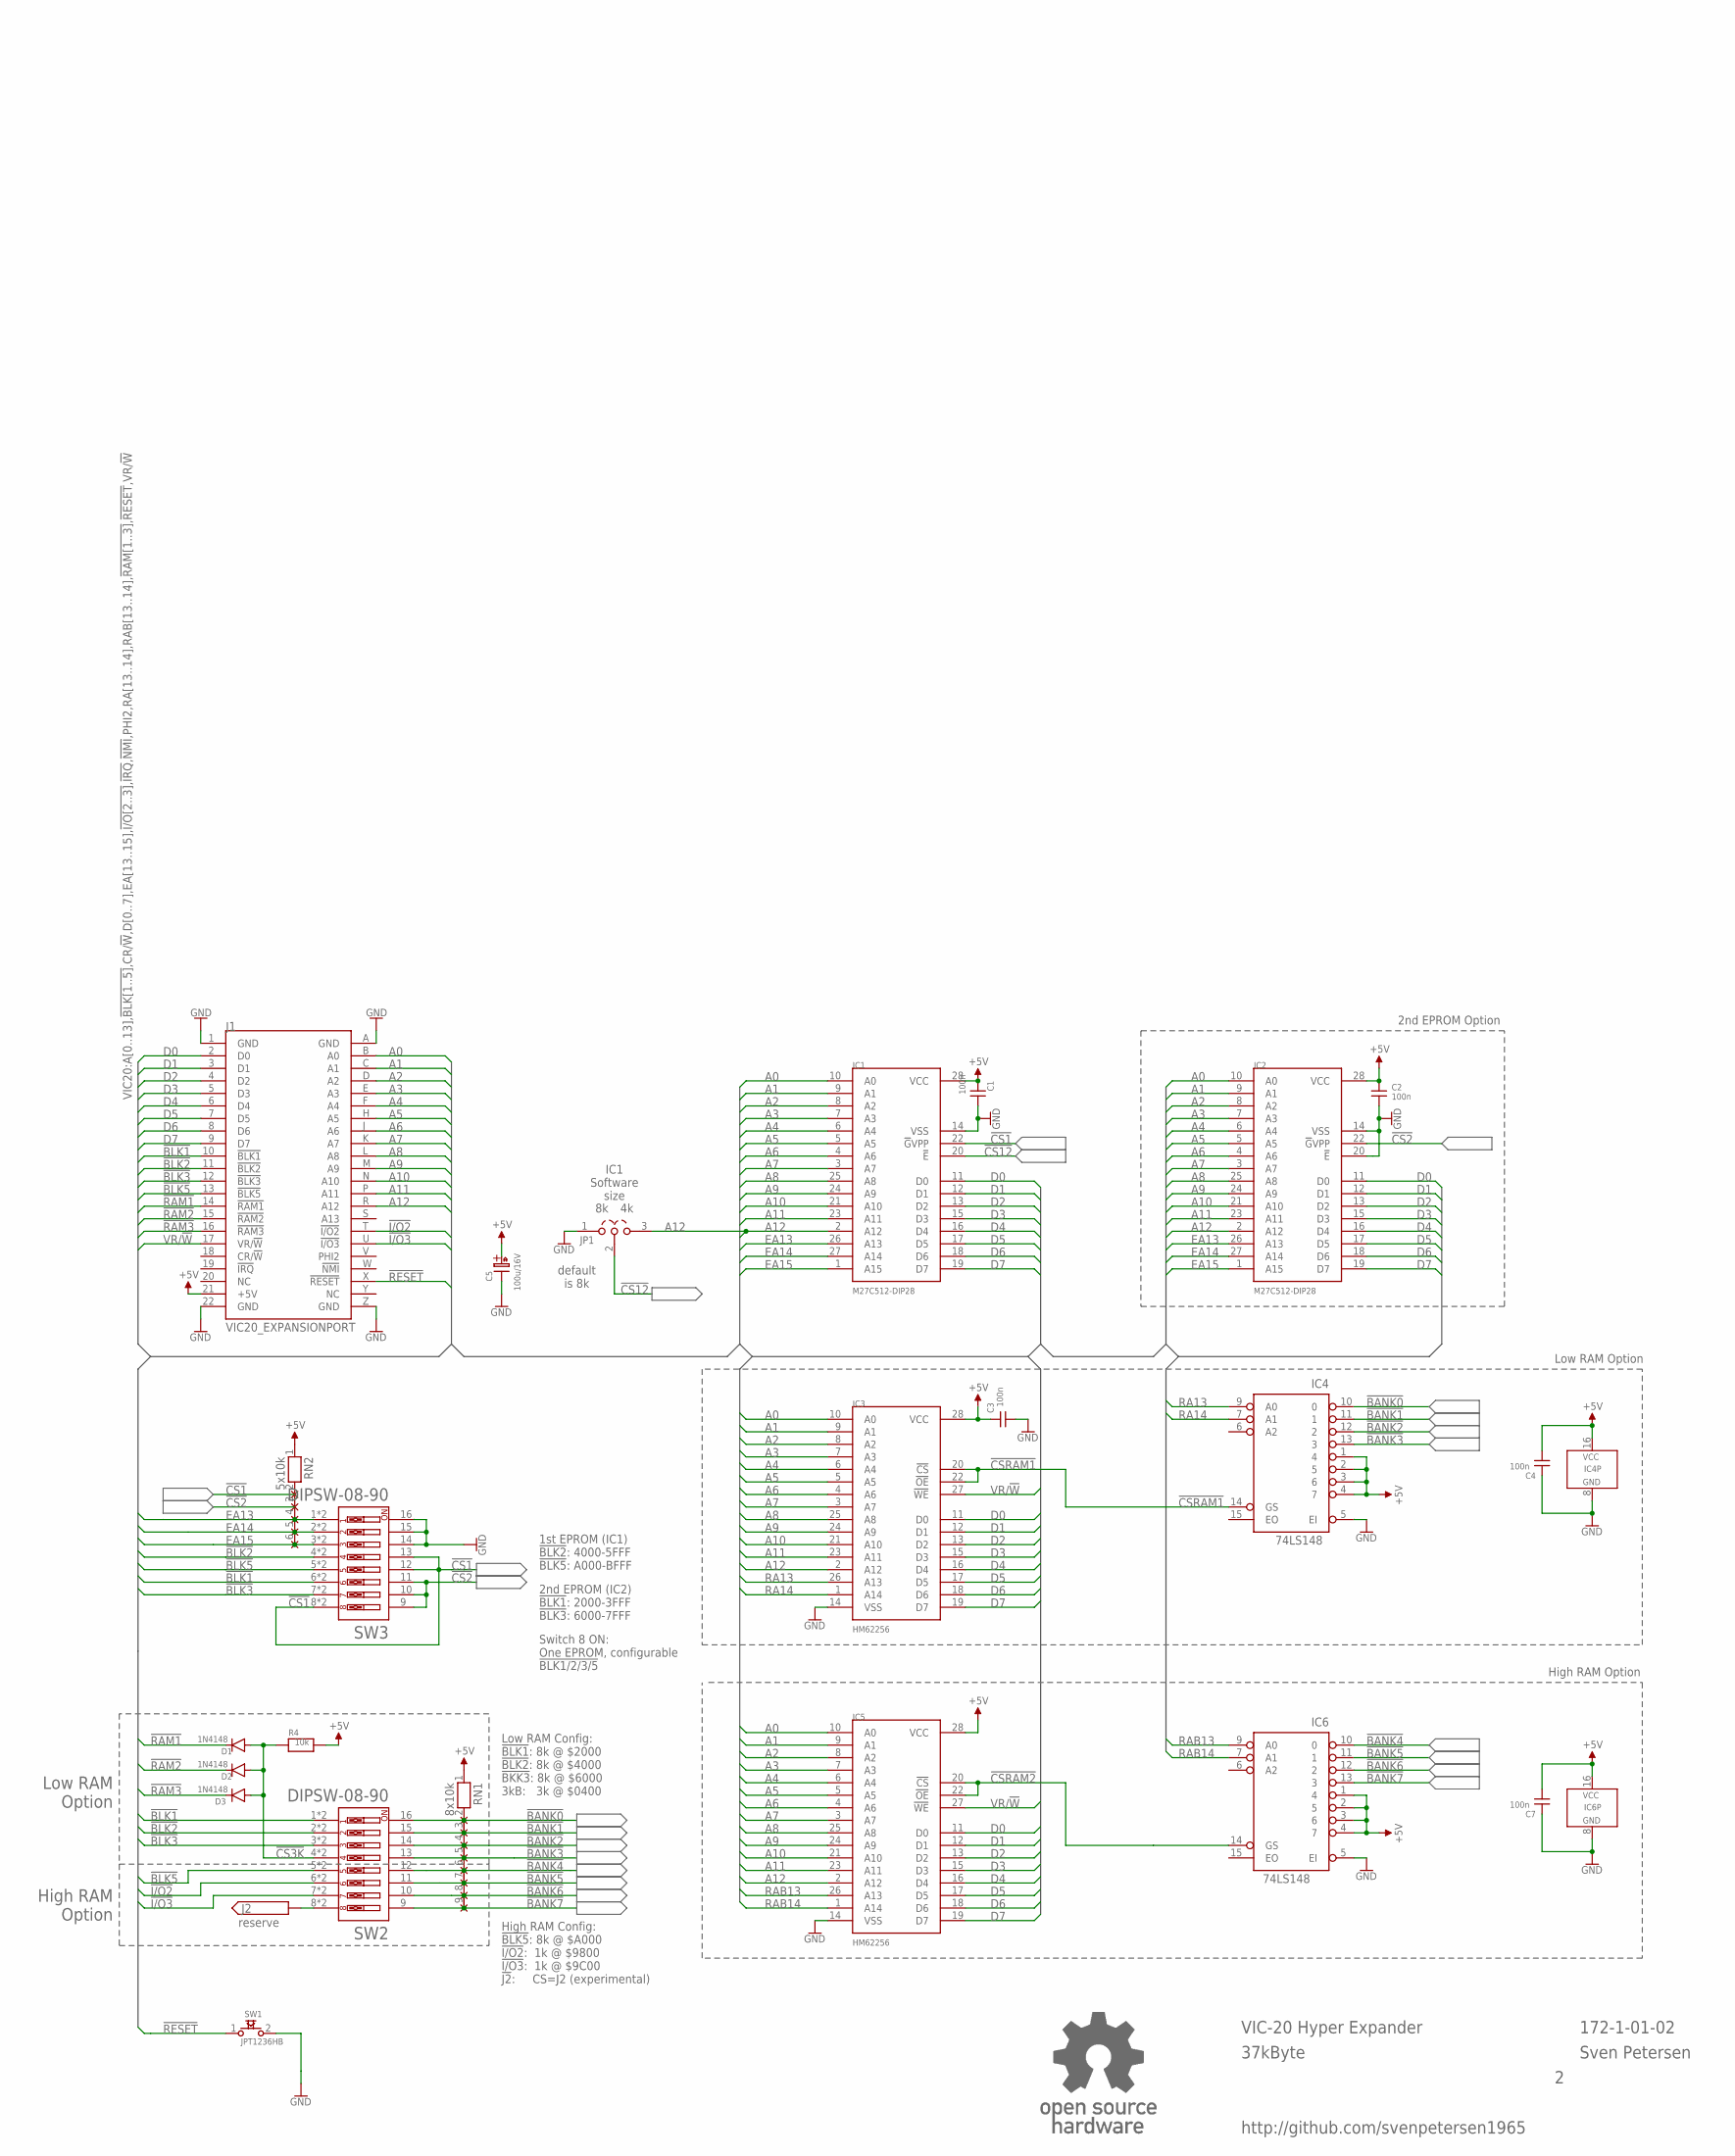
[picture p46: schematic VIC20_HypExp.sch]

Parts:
C1, C2, C3, C4, C7: 100n; C-2,5
C5: 100u/16V; C07/2,5
D1, D2, D3: 1N4148; DO-35/3
IC1, IC2: M27C512-DIP28; DIL28-6
IC3, IC5: HM62256; DIL28-6
IC4, IC6: 74LS148; DIL-16
J1: VIC20_EXPANSIONPORT; VIC20_EXPANSION
J2: PINHD-1X1; 1X01
JP1: COMBI-3P
R4: 10k; R-10
RN1: 8x10k; RN-9
RN2: 5x10k; RN-6
SW1: JPT1236HB; JTP_1236HB
SW2, SW3: DIPSW-08-90
U$2: OPEN_SOURCE_HW; OPENHW

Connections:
!BANK0: IC4.10 (0), RN1.2, SW2.16
!BANK1: IC4.11 (1), RN1.3, SW2.15
!BANK2: IC4.12 (2), RN1.4, SW2.14
!BANK3: IC4.13 (3), RN1.5, SW2.13
!BANK4: IC6.10 (0), RN1.6, SW2.12
!BANK5: IC6.11 (1), RN1.7, SW2.11
!BANK6: IC6.12 (2), RN1.8, SW2.10
!BANK7: IC6.13 (3), RN1.9, SW2.9
!BLK1: J1.10 (!BLK1), SW2.1, SW2.1A (1), SW3.6, SW3.6A (6)
!BLK2: J1.11 (!BLK2), SW2.2, SW2.2A (2), SW3.4, SW3.4A (4)
!BLK3: J1.12 (!BLK3), SW2.3, SW2.3A (3), SW3.7, SW3.7A (7)
!BLK5: J1.13 (!BLK5), SW2.5, SW2.5A (5), SW3.5, SW3.5A (5)
!CS1: IC1.22 (!G!VPP), RN2.2, SW3.8, SW3.8A (8), SW3.12, SW3.13
!CS2: IC2.22 (!G!VPP), RN2.3, SW3.9, SW3.10, SW3.11
!CS3K: D1.A, D2.A, D3.A, R4.1, SW2.4, SW2.4A (4)
!CS12: IC1.20 (!E), JP1.2
!CSRAM1: IC3.20 (!CS), IC3.22 (!OE), IC4.14 (GS)
!CSRAM2: IC5.20 (!CS), IC5.22 (!OE), IC6.14 (GS)
!I/O2: J1.T (!I/O2), SW2.6, SW2.6A (6)
!I/O3: J1.U (!I/O3), SW2.7, SW2.7A (7)
!RAM1: D1.K, J1.14 (!RAM1)
!RAM2: D2.K, J1.15 (!RAM2)
!RAM3: D3.K, J1.16 (!RAM3)
!RESET: J1.X (!RESET), SW1.1
+5V: C1.1, C2.1, C3.2, C4.1, C5.A (+), C7.1, IC1.28 (VCC), IC2.28 (VCC), IC3.28 (VCC), IC4.1 (4), IC4.2 (5), IC4.3 (6), IC4.4 (7), IC4.16 (VCC), IC5.28 (VCC), IC6.1 (4), IC6.2 (5), IC6.3 (6), IC6.4 (7), IC6.16 (VCC), J1.21 (+5V), R4.2, RN1.1, RN2.1
A0: IC1.10 (A0), IC2.10 (A0), IC3.10 (A0), IC5.10 (A0), J1.B (A0)
A1: IC1.9 (A1), IC2.9 (A1), IC3.9 (A1), IC5.9 (A1), J1.C (A1)
A2: IC1.8 (A2), IC2.8 (A2), IC3.8 (A2), IC5.8 (A2), J1.D (A2)
A3: IC1.7 (A3), IC2.7 (A3), IC3.7 (A3), IC5.7 (A3), J1.E (A3)
A4: IC1.6 (A4), IC2.6 (A4), IC3.6 (A4), IC5.6 (A4), J1.F (A4)
A5: IC1.5 (A5), IC2.5 (A5), IC3.5 (A5), IC5.5 (A5), J1.H (A5)
A6: IC1.4 (A6), IC2.4 (A6), IC3.4 (A6), IC5.4 (A6), J1.J (A6)
A7: IC1.3 (A7), IC2.3 (A7), IC3.3 (A7), IC5.3 (A7), J1.K (A7)
A8: IC1.25 (A8), IC2.25 (A8), IC3.25 (A8), IC5.25 (A8), J1.L (A8)
A9: IC1.24 (A9), IC2.24 (A9), IC3.24 (A9), IC5.24 (A9), J1.M (A9)
A10: IC1.21 (A10), IC2.21 (A10), IC3.21 (A10), IC5.21 (A10), J1.N (A10)
A11: IC1.23 (A11), IC2.23 (A11), IC3.23 (A11), IC5.23 (A11), J1.P (A11)
A12: IC1.2 (A12), IC2.2 (A12), IC3.2 (A12), IC5.2 (A12), J1.R (A12), JP1.3
D0: IC1.11 (D0), IC2.11 (D0), IC3.11 (D0), IC5.11 (D0), J1.2 (D0)
D1: IC1.12 (D1), IC2.12 (D1), IC3.12 (D1), IC5.12 (D1), J1.3 (D1)
D2: IC1.13 (D2), IC2.13 (D2), IC3.13 (D2), IC5.13 (D2), J1.4 (D2)
D3: IC1.15 (D3), IC2.15 (D3), IC3.15 (D3), IC5.15 (D3), J1.5 (D3)
D4: IC1.16 (D4), IC2.16 (D4), IC3.16 (D4), IC5.16 (D4), J1.6 (D4)
D5: IC1.17 (D5), IC2.17 (D5), IC3.17 (D5), IC5.17 (D5), J1.7 (D5)
D6: IC1.18 (D6), IC2.18 (D6), IC3.18 (D6), IC5.18 (D6), J1.8 (D6)
D7: IC1.19 (D7), IC2.19 (D7), IC3.19 (D7), IC5.19 (D7), J1.9 (D7)
EA13: IC1.26 (A13), IC2.26 (A13), RN2.4, SW3.1, SW3.1A (1)
EA14: IC1.27 (A14), IC2.27 (A14), RN2.5, SW3.2, SW3.2A (2)
EA15: IC1.1 (A15), IC2.1 (A15), RN2.6, SW3.3, SW3.3A (3)
GND: C1.2, C2.2, C3.1, C4.2, C5.K (-), C7.2, IC1.14 (VSS), IC2.14 (VSS), IC2.20 (!E), IC3.14 (VSS), IC4.5 (EI), IC4.8 (GND), IC5.14 (VSS), IC6.5 (EI), IC6.8 (GND), J1.1 (GND), J1.22 (GND), J1.A (GND), J1.Z (GND), JP1.1, SW1.2, SW3.14, SW3.15, SW3.16
unnamed: J2.1, SW2.8, SW2.8A (8)
NC: J1.20 (NC)
RA13: IC3.26 (A13), IC4.9 (A0)
RA14: IC3.1 (A14), IC4.7 (A1)
RAB13: IC5.26 (A13), IC6.9 (A0)
RAB14: IC5.1 (A14), IC6.7 (A1)
VR/!W: IC3.27 (!WE), IC5.27 (!WE), J1.17 (VR/!W)

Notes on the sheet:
VIC-20 Hyper Expander
172-1-01-02
Sven Petersen
http://github.com/svenpetersen1965
reserve
37kByte
High RAM Option
Low RAM Option
Low RAM Option
2nd EPROM Option
1st EPROM (IC1) !BLK2!: 4000-5FFF !BLK5!: A000-BFFF
2nd EPROM (IC2) !BLK1!: 2000-3FFF !BLK3!: 6000-7FFF
Low RAM Config: !BLK1!: 8k @ $2000 !BLK2!: 8k @ $4000 !BKK3!: 8k @ $6000 3kB: 3k @ $0400
High RAM Config: !BLK5!: 8k @ $A000 !I/O2!: 1k @ $9800 !I/O3!: 1k @ $9C00 !J2!: CS=J2 (experimental)
Switch 8 ON: One EPROM, configurable !BLK1/2/3/5
IC1 Software size
default is 8k
High RAM Option

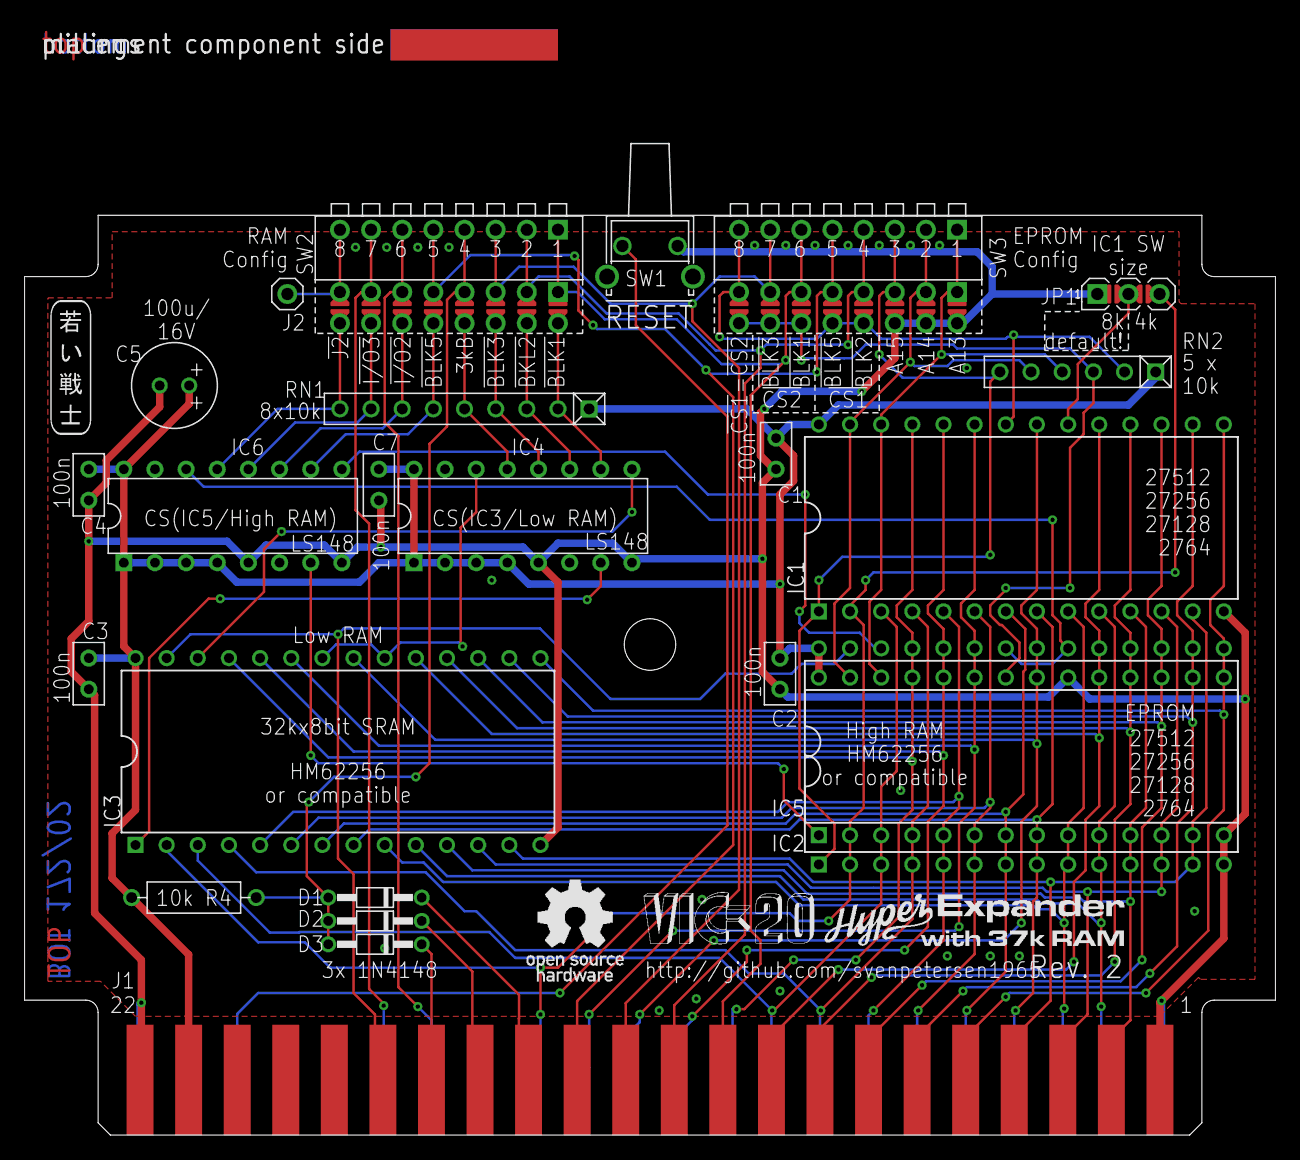
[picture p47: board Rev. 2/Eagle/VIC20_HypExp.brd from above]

Board: 2 copper layers, 102.0 x 75.0 mm, 30 parts (0 on the bottom side), 56 nets.

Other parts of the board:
U$15: SVEN_TAG
U$16: 2LAYER
U$40: PCB-TITLE/
U$42: VIC-20
U$58: HYPER_EXPANDER

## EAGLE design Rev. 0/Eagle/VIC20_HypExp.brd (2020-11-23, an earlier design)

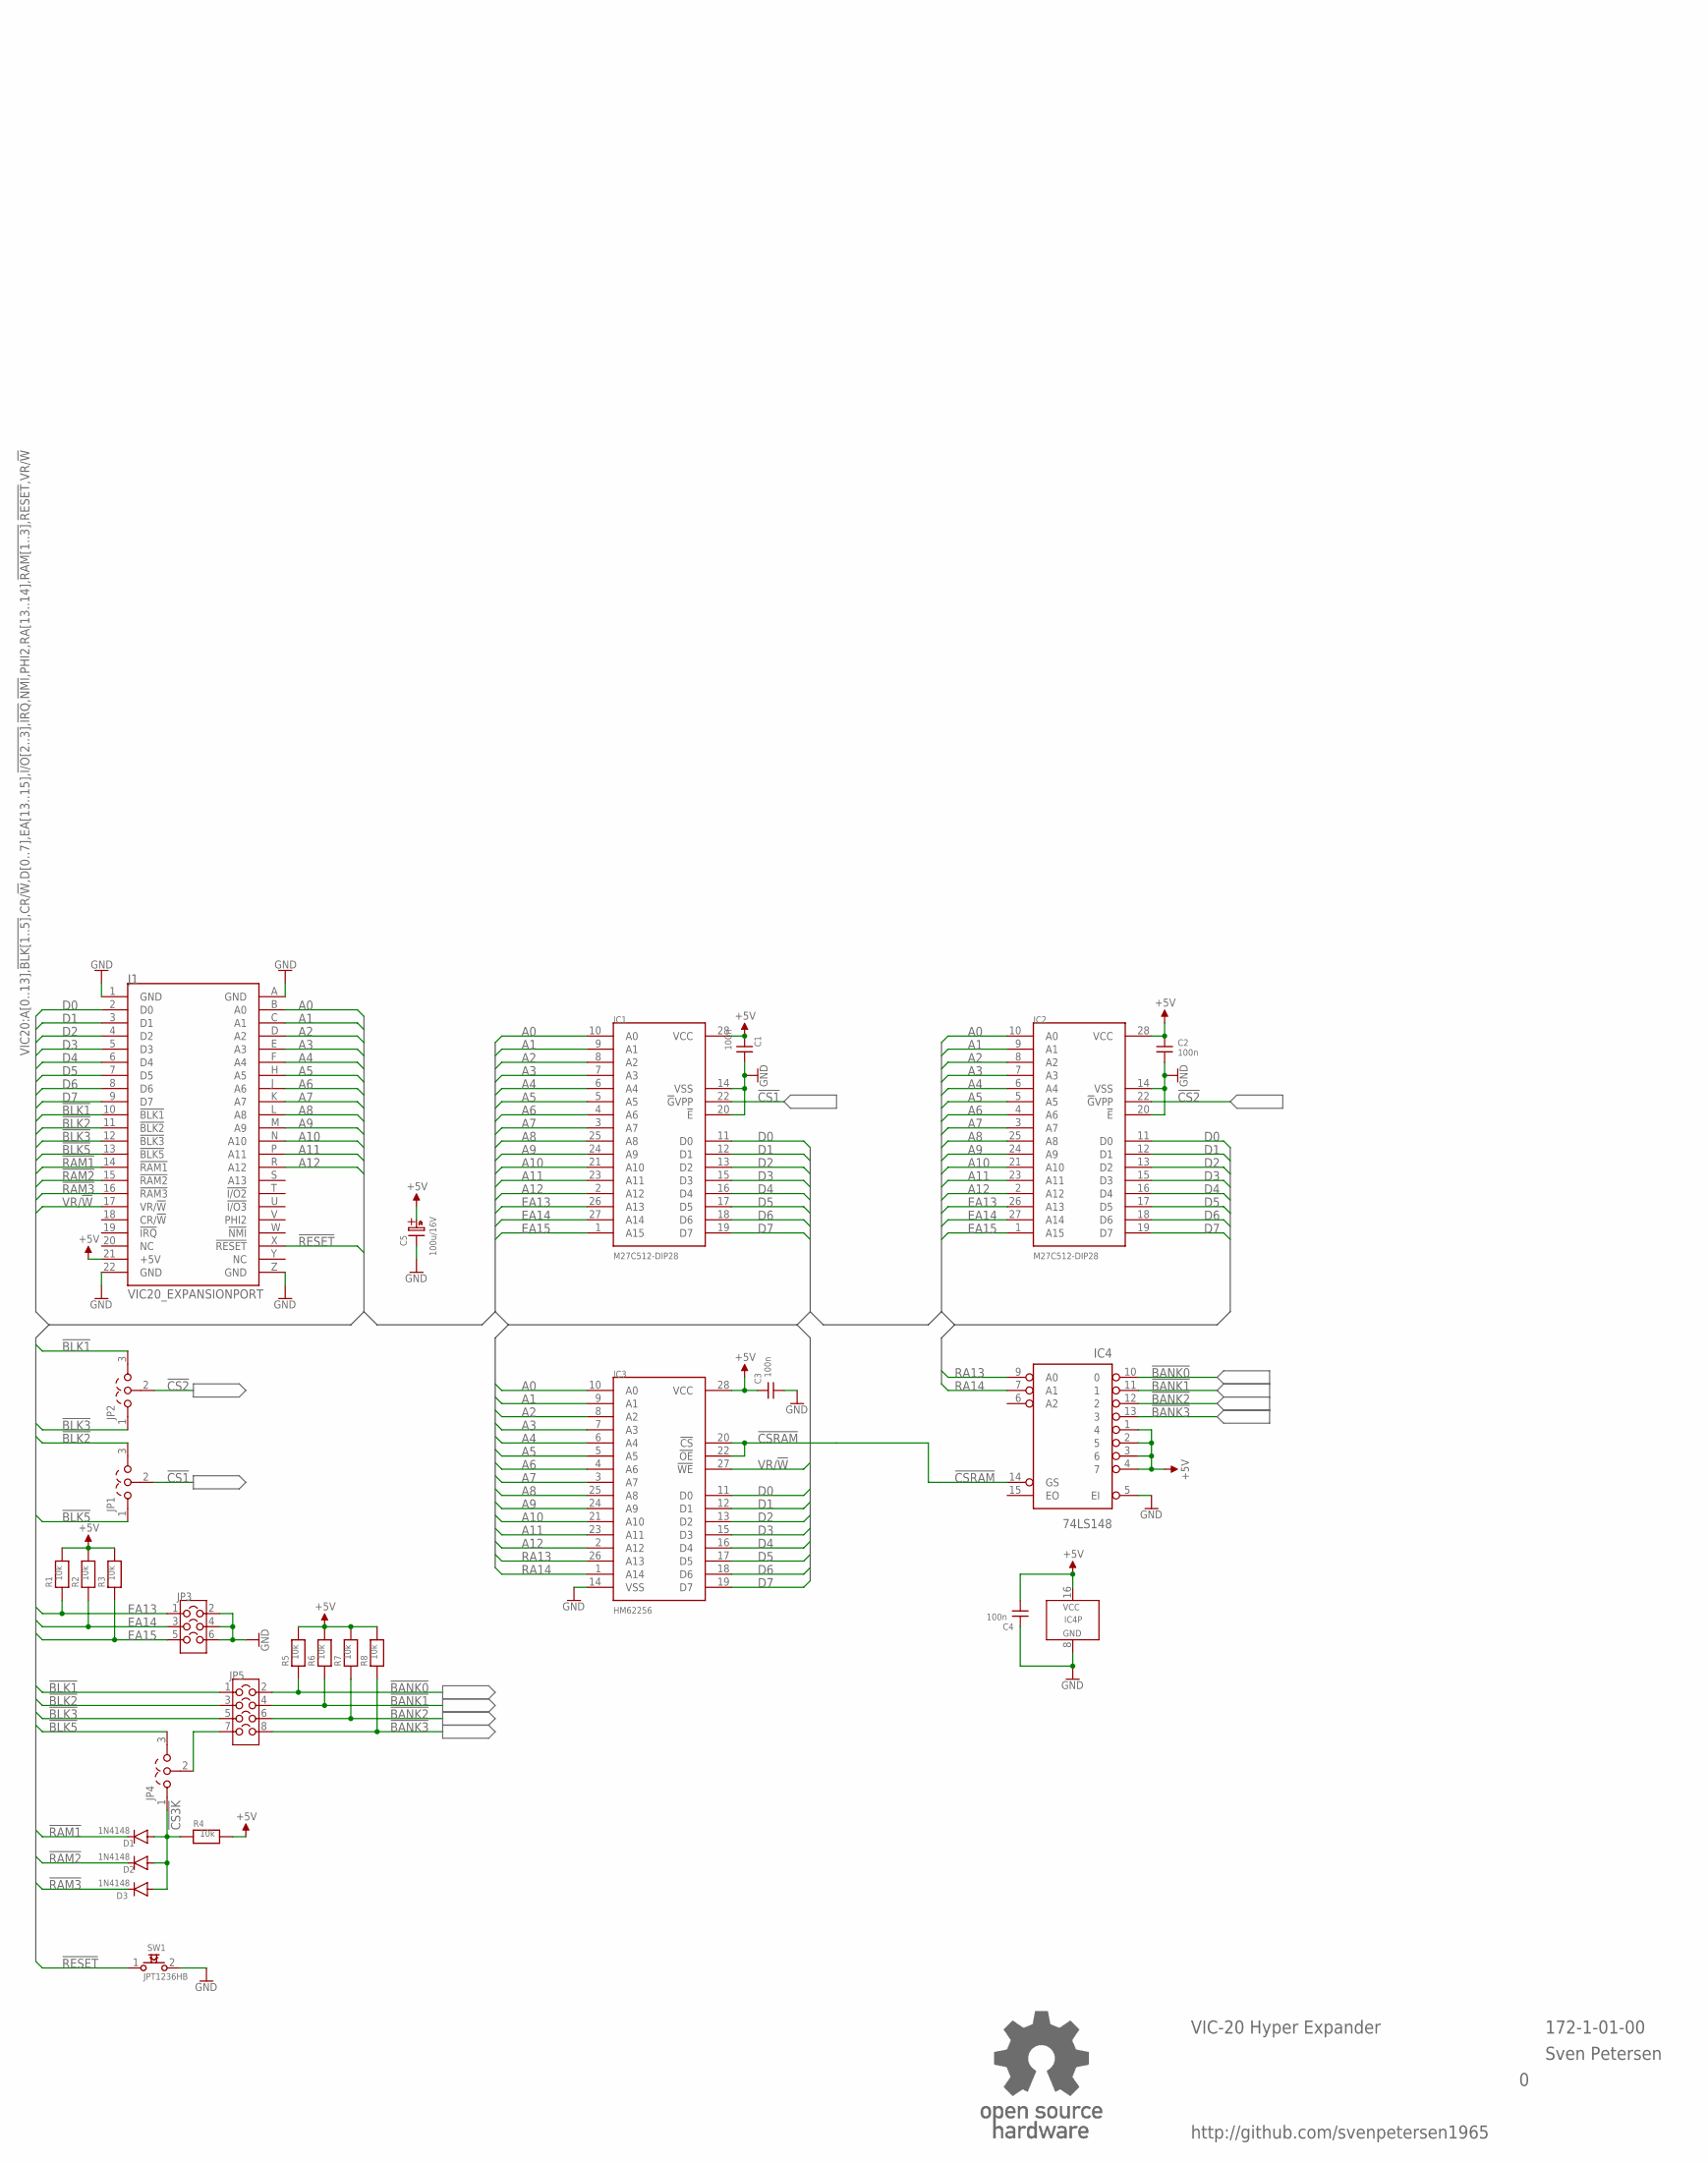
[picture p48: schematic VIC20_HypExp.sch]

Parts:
C1, C2, C3, C4: 100n; C-2,5
C5: 100u/16V; C07/2,5
D1, D2, D3: 1N4148; DO-35/3
IC1, IC2: M27C512-DIP28; DIL28-6
IC3: HM62256; DIL28-6
IC4: 74LS148; DIL-16
J1: VIC20_EXPANSIONPORT; VIC20_EXPANSION
JP1, JP2, JP4: COMBI-3P
JP3: COMBI-3X2P; COMBI-3X2
JP5: COMBI-4X2P; COMBI-4X2
R1, R2, R3, R4, R5, R6, R7, R8: 10k; R-10
SW1: JPT1236HB; JTP_1236HB
U$2: OPEN_SOURCE_HW; OPENHW

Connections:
!BANK0: IC4.10 (0), JP5.2, R5.1
!BANK1: IC4.11 (1), JP5.4, R6.1
!BANK2: IC4.12 (2), JP5.6, R7.1
!BANK3: IC4.13 (3), JP5.8, R8.1
!BLK1: J1.10 (!BLK1), JP2.3, JP5.1
!BLK2: J1.11 (!BLK2), JP1.3, JP5.3
!BLK3: J1.12 (!BLK3), JP2.1, JP5.5
!BLK5: J1.13 (!BLK5), JP1.1, JP4.3
!CS1: IC1.22 (!G!VPP), JP1.2
!CS2: IC2.22 (!G!VPP), JP2.2
!CS3K: D1.A, D2.A, D3.A, JP4.1, R4.1
!CSRAM: IC3.20 (!CS), IC3.22 (!OE), IC4.14 (GS)
!RAM1: D1.K, J1.14 (!RAM1)
!RAM2: D2.K, J1.15 (!RAM2)
!RAM3: D3.K, J1.16 (!RAM3)
!RESET: J1.X (!RESET), SW1.1
+5V: C1.1, C2.1, C3.2, C4.1, C5.A (+), IC1.28 (VCC), IC2.28 (VCC), IC3.28 (VCC), IC4.1 (4), IC4.2 (5), IC4.3 (6), IC4.4 (7), IC4.16 (VCC), J1.21 (+5V), R1.2, R2.2, R3.2, R4.2, R5.2, R6.2, R7.2, R8.2
A0: IC1.10 (A0), IC2.10 (A0), IC3.10 (A0), J1.B (A0)
A1: IC1.9 (A1), IC2.9 (A1), IC3.9 (A1), J1.C (A1)
A2: IC1.8 (A2), IC2.8 (A2), IC3.8 (A2), J1.D (A2)
A3: IC1.7 (A3), IC2.7 (A3), IC3.7 (A3), J1.E (A3)
A4: IC1.6 (A4), IC2.6 (A4), IC3.6 (A4), J1.F (A4)
A5: IC1.5 (A5), IC2.5 (A5), IC3.5 (A5), J1.H (A5)
A6: IC1.4 (A6), IC2.4 (A6), IC3.4 (A6), J1.J (A6)
A7: IC1.3 (A7), IC2.3 (A7), IC3.3 (A7), J1.K (A7)
A8: IC1.25 (A8), IC2.25 (A8), IC3.25 (A8), J1.L (A8)
A9: IC1.24 (A9), IC2.24 (A9), IC3.24 (A9), J1.M (A9)
A10: IC1.21 (A10), IC2.21 (A10), IC3.21 (A10), J1.N (A10)
A11: IC1.23 (A11), IC2.23 (A11), IC3.23 (A11), J1.P (A11)
A12: IC1.2 (A12), IC2.2 (A12), IC3.2 (A12), J1.R (A12)
D0: IC1.11 (D0), IC2.11 (D0), IC3.11 (D0), J1.2 (D0)
D1: IC1.12 (D1), IC2.12 (D1), IC3.12 (D1), J1.3 (D1)
D2: IC1.13 (D2), IC2.13 (D2), IC3.13 (D2), J1.4 (D2)
D3: IC1.15 (D3), IC2.15 (D3), IC3.15 (D3), J1.5 (D3)
D4: IC1.16 (D4), IC2.16 (D4), IC3.16 (D4), J1.6 (D4)
D5: IC1.17 (D5), IC2.17 (D5), IC3.17 (D5), J1.7 (D5)
D6: IC1.18 (D6), IC2.18 (D6), IC3.18 (D6), J1.8 (D6)
D7: IC1.19 (D7), IC2.19 (D7), IC3.19 (D7), J1.9 (D7)
EA13: IC1.26 (A13), IC2.26 (A13), JP3.1, R1.1
EA14: IC1.27 (A14), IC2.27 (A14), JP3.3, R2.1
EA15: IC1.1 (A15), IC2.1 (A15), JP3.5, R3.1
GND: C1.2, C2.2, C3.1, C4.2, C5.K (-), IC1.14 (VSS), IC1.20 (!E), IC2.14 (VSS), IC2.20 (!E), IC3.14 (VSS), IC4.5 (EI), IC4.8 (GND), J1.1 (GND), J1.22 (GND), J1.A (GND), J1.Z (GND), JP3.2, JP3.4, JP3.6, SW1.2
unnamed: JP4.2, JP5.7
NC: J1.20 (NC)
RA13: IC3.26 (A13), IC4.9 (A0)
RA14: IC3.1 (A14), IC4.7 (A1)
VR/!W: IC3.27 (!WE), J1.17 (VR/!W)

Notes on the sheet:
VIC-20 Hyper Expander
172-1-01-00
Sven Petersen
http://github.com/svenpetersen1965

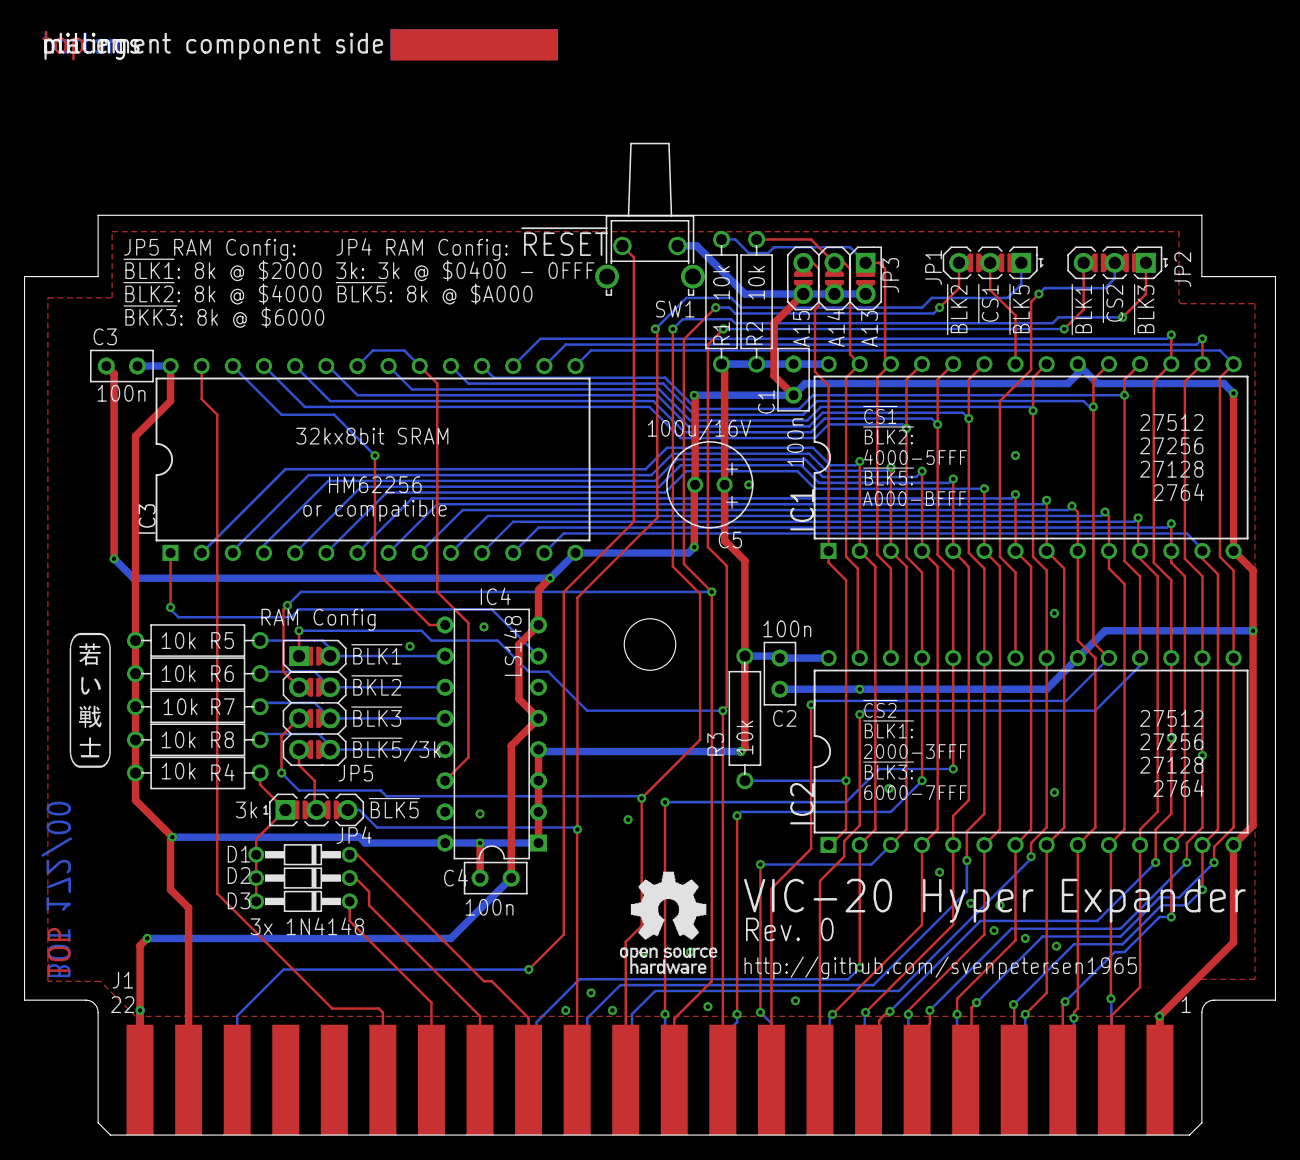
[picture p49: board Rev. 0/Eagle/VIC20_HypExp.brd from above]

Board: 2 copper layers, 102.0 x 75.0 mm, 31 parts (0 on the bottom side), 46 nets.

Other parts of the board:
U$15: SVEN_TAG
U$16: 2LAYER
U$40: PCB-TITLE/

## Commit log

2020-12-12 Added calculation
    [VIC20_SExpII_BOM_v0_0_calc.xlsx]
2021-05-05 Rev. 1 released
    [VIC20_HypExp.brd, VIC20_HypExp.dxf, VIC20_HypExp.sch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]
2021-11-02 Rev. 2 released
    [VIC20_HypExp.brd, VIC20_HypExp.dxf, VIC20_HypExp.sch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]
2022-02-26 Gerbers removed
